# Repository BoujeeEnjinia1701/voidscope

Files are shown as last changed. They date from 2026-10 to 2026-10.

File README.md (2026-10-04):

# VoidScope

     

**Area:** Situational field hardware · **TRL:** 3 of 9 (proof of concept on paper) · **Value-engineering target:** about $2,000 USD (estimated cost $1,780 USD) · **Difficulty:** 3 of 5

Searches rubble voids with a camera probe that also delivers water and air to a trapped survivor.

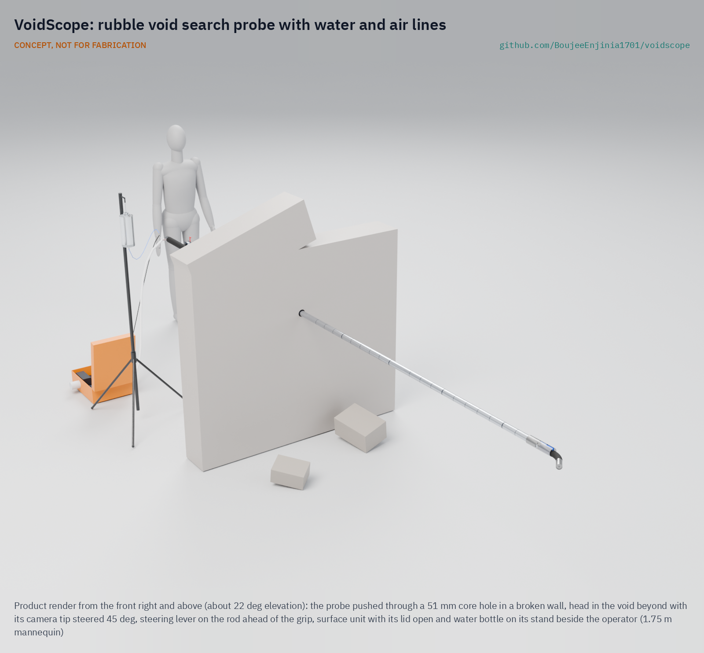
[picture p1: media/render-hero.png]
VoidScope: rubble void search probe with water and air lines, product render


[Exploded render](media/render-exploded.png) · [Detail render](media/render-detail.png) · [Interactive 3D model](media/viewer.html) · [Concept blueprint (PDF)](media/concept-blueprint.pdf) · [General arrangement (PDF)](cad/drawings/VDS-DWG-001.pdf) · [Calculations](docs/04-calcs/01-sizing.md) · [Prototype build plan](docs/05-build-plan.md) · [Design decisions](docs/06-design-decisions.md) · [Review note](docs/REVIEW.md)

## Concept rationale

Most people pulled alive from collapsed buildings are found by local responders in the first day, with little equipment. A camera probe lets a crew look into a void through a small hole instead of opening it blind, and the same probe can then carry water and fresh air to the person it finds. One tool does both jobs, so a crew that has located a survivor does not have to break a second path in to supply them.

Keeping the design open and buildable from commodity parts matters because commercial search cameras sit in the tens of thousands of dollars. VoidScope is a documented push probe built from a bought sealed camera head, aluminium tube and turned aluminium parts, with the rod itself as the air duct and a single-use food-grade water line inside it. Its value-engineering target is $2,000 USD and the constructable design is estimated at $1,780 USD, so that municipal and volunteer teams can build, repair and train with it.

## Burning platform

Time decides who lives. More than 90 per cent of earthquake survivors are rescued within the first three days, most within 24 hours by local responders using minimal equipment, and international teams typically need more than 24 hours to arrive ([Gulf News, citing Ilan Kelman, UCL, 2023](https://gulfnews.com/world/mena/why-first-72-hours-are-crucial-for-turkey-syria-quake-rescues-1.1675864021699)). The same source notes that without water, trapped people start dying at the three to five day mark.

The tools that help crews see into voids are costly. A Leader Cam search camera lists at $17,562 USD ([Emergency Responder Products](https://emergencyresponderproducts.com/products/leader-cam)), and the Savox SearchCam 3000 kit weighs 18.6 kg (41 lb) in its case ([Savox datasheet](https://www.datocms-assets.com/120614/1756472896-savox-searchcam-3000-datasheet-2.pdf)). Neither delivers water or air. Where supplies do reach trapped people, it is by improvisation: at Rana Plaza, rescuers gave the survivor Reshma water, oxygen and saline while they cut her free ([Global News, 2013](https://globalnews.ca/news/550768/bangladesh-rescuers-find-survivor-in-rubble-17-days-after-collapse/)).

## Where it could be used

### By industry

| Industry | Use |
| --- | --- |
| Fire and rescue services | Hasty void search and survivor support by municipal crews without a funded USAR camera |
| Humanitarian and disaster response | Low-cost search kit for local and volunteer teams in the first 72 hours after an earthquake |
| Construction and demolition | Standby search tool on sites where structures under construction may collapse |
| Mining and tunnelling | Looking into collapsed drifts or rescue pipes and passing water and air to trapped workers |
| Training and education | Affordable training probe for USAR courses and community emergency response teams |

### By country or region

| Country or region | Why it matters there |
| --- | --- |
| Turkey and Syria | The February 2023 earthquakes killed more than 42,000 people, and one survivor was pulled out after 248 hours without food or water ([CNN, 2023](https://www.cnn.com/2023/02/16/europe/turkey-syria-earthquake-rescue-efforts-intl/index.html)). |
| Bangladesh | The Rana Plaza collapse in 2013 left more than 1,000 dead, and rescuers worked for more than two weeks to reach survivors in the basement ([IBTimes UK, 2013](https://www.ibtimes.co.uk/rana-plaza-disaster-woman-named-reshma-found-466613)). |
| Nigeria | When a 21-storey building under construction collapsed in Ikoyi, Lagos, in 2021, up to 100 people were feared trapped ([Al Jazeera, 2021](https://www.aljazeera.com/news/2021/11/1/lagos-building-collapses-several-killed)) and 42 bodies were eventually recovered ([VOA, 2021](https://www.voanews.com/a/death-toll-in-lagos-high-rise-building-collapse-rises-to-42-/6303343.html)). |
| Nepal | The 2015 magnitude 7.8 earthquake killed more than 1,300 people by the first day's reports, and survivors pulled from the rubble swamped hospitals in the capital ([NPR, 2015](https://www.npr.org/sections/thetwo-way/2015/04/25/402160910/7-8-quake-hits-nepal-toppling-buildings-killing-at-least-138)). |

## What sparked the idea

On 10 May 2013, seventeen days after the Rana Plaza building collapsed near Dhaka, rescuers heard a garment worker named Reshma tapping on the wreckage with a pipe. She had rationed a few bottles of water. While crews cut through rods and debris to free her, they passed her water, oxygen and saline ([Global News, 2013](https://globalnews.ca/news/550768/bangladesh-rescuers-find-survivor-in-rubble-17-days-after-collapse/)). Finding her took days of listening; supplying her took improvisation. VoidScope asks whether one simple probe could do both, sooner.

## Problem

After a building collapse, local crews reach most survivors first but rarely have search cameras, and those who find someone alive still need to keep them supplied while the dig goes on. Commercial search cameras cost more than many local teams can pay and do not deliver water or air.

Full problem statement: [docs/01-problem.md](docs/01-problem.md)

## Concept

A 4.5 m push probe, 48 mm across at its widest, that passes a standard 51 mm core hole; its camera tip bends up to 90° either way from a thumb lever to look around a bend. Four aluminium sections click together with snap buttons and stay threaded on the camera cable and a water guide tube, like the cord in a tent pole. A sealed 1080p camera with its own lights sits in the steerable tip; a small speaker for two-way talk and a bite valve sit in the turned aluminium head. A battery blower in the surface unit pushes filtered air down the rod's bore and out of six holes at the head, never above 0.9 kPa even when the tip is blocked; a gravity drip from a bottle on a stand reaches the bite valve through a capillary that caps the flow at 4.5 mL/min. The monitor and recorder sit in the lid of the surface unit.

Full design precis: [docs/02-concept.md](docs/02-concept.md) · Requirements: [docs/03-requirements.md](docs/03-requirements.md)

## Key components

- Camera head: bought IP68 pipe-inspection head, 29 mm, 1080p, 12 LEDs
- Head: turned aluminium collar (socket, air outlets, speaker, water exit) and nose (camera, bite valve pocket)
- Rod: four 1,050 mm sections of 38.1 mm aluminium tube with bonded couplers and snap buttons; depth bands every 100 mm
- Tail cap with the air inlet barb, and a grip
- Lines: camera and speaker cable; PTFE guide tube; single-use water set with capillary, roller clamp and bite valve
- Surface unit: IP67 case with LiFePO4 battery, blower, intake filter, flow meter, push-to-talk amplifier, and a 7 in monitor with recorder in the lid
- Water bottle on a light stand; rod carry case; cleaning kit and spare water sets

## Building the prototype

The design is constructable: every part can be cut, drilled, turned or bought, and every joint has a fixing, checked by 180 model checks. The [prototype build plan](docs/05-build-plan.md) takes a maker through fourteen made components and seventeen assembly steps, each with a picture, and lists the first checks and the safety stops. It is a plan, not yet built; building and testing to it is TRL 4 work. Decisions live in the [design decisions register](docs/06-design-decisions.md).

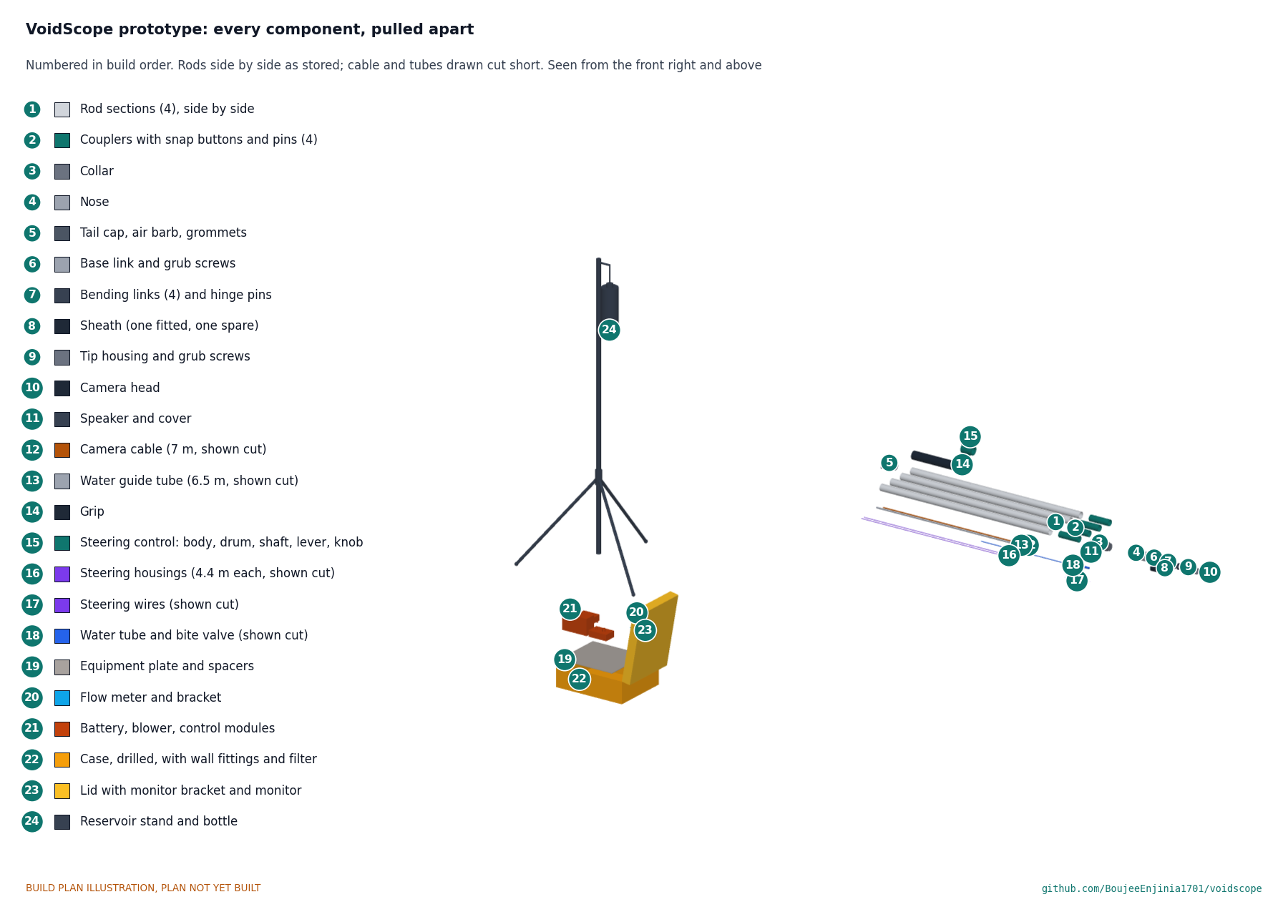
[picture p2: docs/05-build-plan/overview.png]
VoidScope prototype: every component, pulled apart


## Safety

> Safety-critical rescue equipment. Published as an open engineering reference, never as certified rescue equipment, and not a medical device. This is a TRL 3 concept, not for fabrication.
>
> Only trained rescue teams should use it, inside their own incident command and structural safety procedures. The operator never enters the void.
>
> Water can be inhaled by a survivor who is drowsy, injured or lying badly. Give water only under the direction of the team's medical lead, only to a conscious person who can drink, and only by the gravity drip through the bite valve, never under pressure. Never remove the capillary that caps the flow.
>
> Fresh air must be clean and low pressure; blowing air into a void can raise dust. Filter the intake and never connect fuel-engine exhaust, a compressor or compressed gas cylinders. The blower is chosen so it cannot exceed 1 kPa even with the tip blocked.
>
> The surface unit holds 12.8 V lithium iron phosphate packs. Charge them only on their own charger, away from the kit, on a non-combustible surface, never below 0 °C.
>
> Parts that touch the survivor are single-use or cleaned to a written procedure between uses.
>
> This design is published as an open engineering reference. It is not certified equipment.

## Repository layout

| Folder | Contents |
| --- | --- |
| `docs/` | Problem, concept, requirements, calculations and design decisions |
| `cad/src/` | build123d Python source, the source of truth for all geometry |
| `cad/step/`, `cad/stl/` | Exported models for FreeCAD, other CAD tools and printing |
| `cad/drawings/` | 2D sketches and dimensioned drawings |
| `bom/` | Bill of materials |
| `electronics/` | KiCad schematics and PCB layouts |
| `firmware/` | Microcontroller code |
| `media/` | Renders, perspectives and photos |
| `build-log/` | Dated prototyping notes |

## Documentation

Controlled documents follow the portfolio [documentation standard](.kit/STANDARDS.md). Each carries a document ID (VDS-PRC-001 for the precis), a version and a revision history. Branded PDFs are built with `python .kit/render.py` and attached to GitHub Releases when a document is tagged, for example `VDS-PRC-001/v1.0`.

## Credits

Designed by Amish Chadha at Design Molecule Labs. See [CONTRIBUTORS.md](CONTRIBUTORS.md) for roles. To cite this design, use [CITATION.cff](CITATION.cff) (GitHub shows it as "Cite this repository").

AI assistance (Claude) was used to accelerate prototype documentation and first-pass research. Design direction and all decisions are Amish Chadha's, recorded in this repository's decision records (`docs/decisions/`).

## Licenses

- **Hardware** (CAD, drawings, BOM, electronics): [CERN-OHL-S v2](LICENSE)
- **Software** (firmware, scripts, notebooks): [MIT](LICENSE-SOFTWARE)

A project of the [Design Molecule](https://designmolecule.com) lab.

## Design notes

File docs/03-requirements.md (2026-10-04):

---
doc_id: VDS-REQ-001
title: VoidScope requirements
project: VoidScope
doc_type: Requirements
version: "0.5"
status: Draft
date: '2026-10-03'
author: Amish Chadha
license: CERN-OHL-S-2.0
revisions:
- version: "0.1"
  date: '2026-09-30'
  author: Amish Chadha
  change: Initial scaffold
- version: "0.2"
  date: '2026-10-03'
  author: Amish Chadha
  change: "TRL 2: R2 split into reach (R2) and bends (R11); R5 restated as a ceiling with a bite valve; R6 adds the blocked-tip limit; R8 worded as a value-engineering target; R12 two-way voice added; concept status for each"
- version: "0.3"
  date: '2026-10-03'
  author: Amish Chadha
  change: "TRL 3: status from VDS-CAL-001 on the constructable design (VDS-DDR-002)"
- version: "0.4"
  date: '2026-10-03'
  author: Amish Chadha
  change: "R11 restated by Amish (decision 3A) as seeing around a 45-degree bend from a straight hole, with a test-box verification; met on paper by the steerable camera tip (VDS-DDR-003); status of R1, R2, R4, R8 and R9 updated from VDS-CAL-001 v0.2"
- version: "0.5"
  date: '2026-10-03'
  author: Amish Chadha
  change: "Round-2 decision 3A (VDS-DDR-004): water offered with the tip steered aside; medical lead's confirmation in drills. Requirement wording unchanged"
---

# VoidScope requirements

Eleven of the twelve requirements are met on paper by the constructable design with its steerable camera tip: eight by calculation and three by design, all to be confirmed by test at TRL 4. R9 (setup in 3 minutes) is estimated at 2.2 minutes but can only be settled by timed drills. R11 was restated on 2026-10-03 by Amish, who chose option A for it ("3A", in his reply "1A 2A 3A 4A 5A 6A 7A 8A 9A 10A 11A"): instead of following a channel with two 45° bends, the probe goes in straight and its camera tip, steered from the handle, looks around a 45° bend. The rigid rod, the air path through its bore and the water tube to the bite valve are unchanged.

*Table 1. Requirements and status at TRL 3 (tags in brackets refer to VDS-CAL-001).*

| ID | Requirement | Target | Verification (TRL 4 or later) | Status at TRL 3 |
| --- | --- | --- | --- | --- |
| R1 | Probe passes a standard core hole | Outer diameter of tip and rod at or below 50 mm | Pass the assembled probe through a 51 mm test ring along its full length | Met with the tip locked straight: 48 mm at the head and tip, 47 mm at the grip [A1]. The handle-end fittings (the tail cap's air barb and now the steering control) are wider and stay outside the hole |
| R2 | Reach into a void along a straight path | Working length of at least 4 m (13 ft) | Measure assembled length from the grip to the tip | Met: 4,203 mm from the grip; 4,131 mm can go in before the steering control reaches the hole [A4g, A4] |
| R3 | See in darkness and dust | Read a 20 mm high letter at 1 m in a dark, dusty test box | Test box with a set dust load and no ambient light | Met on paper: 19 pixels per letter against 10 needed; 7 lx left after 2 m of dusty air [C2, C6]; dust load to test |
| R4 | Survive rubble handling | Head survives 20 drops of 1 m onto concrete and 1 m water immersion for 30 minutes | Drop and immersion tests followed by a video check | By design: IP68 camera in an aluminium tip housing, sheathed bending section, nose with 2.85 mm minimum wall [G2]; to test, with the tip straight and bent |
| R5 | Controlled water delivery | Drip from 0 up to a ceiling of no more than 5 mL/min at any allowed height up to 40 °C; no flow when the clamp is closed or the valve is not bitten | Timed collection at the tip at set heights and temperatures | Met: ceiling 1.5 mL/min at 1 m and 20 °C, 4.5 mL/min at 2 m and 40 °C [D1, D2] |
| R6 | Air delivery to the void | At least 20 L/min of filtered air at the tip; never more than 1 kPa above ambient, even with the tip blocked | Flow meter and manometer at the tip, open and blocked | Met: 44 L/min at full speed, 0.9 kPa at shut-off [E3, E5] |
| R7 | Shift-long battery life | At least 4 h of continuous video and light at 20 °C and at -10 °C | Run-down test at 20 °C and at -10 °C | Met: 6.2 h and 4.3 h on one pack [F4] |
| R8 | Cost against the value-engineering target | Full kit parts cost against the USD 2,000 target | Costed bill of materials from named suppliers | USD 1,780, USD 220 under the target [I2, I4] |
| R9 | Quick to deploy | Two trained people assemble and start searching within 3 minutes | Timed drills with a USAR partner | Estimate 2.2 min [H6]; only a timed drill can settle it |
| R10 | Hygienic water path | Water path parts replaceable in under 5 minutes without tools | Timed replacement against a cleaning procedure | By design: single-use water set, about 4 min [D8]; to time |
| R11 | See around a 45-degree bend from a straight hole (restated 2026-10-03, Amish, decision 3A) | With the probe pushed straight through a 51 mm hole, steer the camera to look down a passage that turns 45° to either side and read what is there | Test box: a 51 mm hole into a straight passage 300 mm wide that turns 45° 0.5 m beyond the hole. Push the probe straight in, steer the tip from the handle and read 20 mm letters 1 m down the turned passage on the monitor; repeat to the other side; straighten the tip and withdraw it through the hole | Met on paper: the tip bends up to 90° each way [J3]; bent 45° it needs 83 mm to the side [J6] and a 20 mm letter at 1 m gets 19 pixels [C2] |
| R12 | Talk with the survivor | Two-way voice between the operator and a person at the tip | Speech test in a rubble box | By design: tip speaker as speaker and microphone, push-to-talk headset |

## Assumptions

- Local crews can open or find gaps of about 50 mm into most voids of interest.
- A rigid, sectioned rod is good enough for a first version, with a camera tip that bends in one plane; turning the rod chooses the plane. Following a bent channel with the rod itself is not required (R11 as restated).
- A slow gravity drip through a bite valve is an acceptable way to give water when a medical lead directs it; the bite valve stays on the nose and the operator steers the tip aside to give water (drill card, build plan section 5a); the medical lead's confirmation in drills is a TRL 4 item.
- Commodity sealed pipe-inspection camera heads meet the image, light and sealing targets.

> **Safety:** These requirements describe rescue equipment that delivers water and air to a trapped person and carries a lithium battery. The steerable tip must be locked straight before it goes into or comes out of a hole. Meeting them on paper does not make the design safe to use. VoidScope is an open engineering reference, not certified rescue equipment and not a medical device; see VDS-PRC-001, Safety.

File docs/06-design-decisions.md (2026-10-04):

---
doc_id: VDS-DEC-001
title: VoidScope design decisions register
project: VoidScope
doc_type: Design decisions register
version: "0.3"
status: Draft
date: '2026-10-03'
author: Amish Chadha
license: CERN-OHL-S-2.0
revisions:
- version: "0.1"
  date: '2026-10-03'
  author: Amish Chadha
  change: "Register opened at TRL 3; every decision made under Amish's 2026-10-03 pre-approval"
- version: "0.2"
  date: '2026-10-03'
  author: Amish Chadha
  change: "Amish's requirement decision 3A (steerable camera tip, R11 restated) recorded as made (VDS-DDR-003); one new open decision on bite valve access; four items to confirm when parts are bought; value engineering updated"
- version: "0.3"
  date: '2026-10-03'
  author: Amish Chadha
  change: "Open decision 1 (bite valve access) decided, round 2, 3A (VDS-DDR-004); one item added to confirm when parts are bought; no open decisions"
---

# VoidScope design decisions register

Every design decision still to be made, and every decision made, in one place. Each decision is argued in full in its decision record under `docs/decisions/`; this register is the index Amish works from. The build plan (`docs/05-build-plan.md`) describes the design as it stands and does not list open decisions.

> **Safety:** Several decisions below set safety stops: the drip ceiling, the bite valve, the blower's shut-off pressure and the battery chemistry. The open decision on bite valve access touches how a survivor is given water. They were taken on the conservative side (VDS-DDR-001, Table 2). VoidScope is rescue equipment that is not certified and is not a medical device.

## Open decisions

None. Open decision 1 (bite valve access) was decided by Amish on 2026-10-03: the valve stays on the nose and the tip is steered aside to give water; see Decisions made and VDS-DDR-004.

## To confirm when parts are bought

| # | What to confirm | Why it matters | Source |
| --- | --- | --- | --- |
| 1 | The camera head is 29 mm or less across and about 55 mm long, IP68 at 1 m for 30 min, AHD 1080p with about a 90° view and 12 dimmable LEDs, with a pigtail at least 170 mm long | It sets the tip housing bore, R3 and R4; the pigtail must reach back through the tip to its splice in the nose | VDS-DDR-001 D4; VDS-CAL-001 C |
| 2 | The blower's shut-off (maximum static) pressure is 1.0 kPa or less, and its curve gives at least 20 L/min through 0.38 kPa | It is the air pressure safety stop (R6) | VDS-DDR-001 D8, S3; VDS-CAL-001 E |
| 3 | The flow meter's pressure drop is 0.2 kPa or less at 20 L/min and it fits 100 mm tall | A larger drop lowers the full-speed flow; the lid must close | VDS-CAL-001 E; VDS-DDR-002 P11 |
| 4 | The snap button suits 1.47 mm and 2.11 mm walls, its button stands about 1.5 mm proud, and it holds a 300 N pull | It locks every joint | VDS-DDR-002 P2; VDS-CAL-001 B |
| 5 | The two tube sizes telescope with about 0.11 mm a side as bought | The couplers must slide in by hand | VDS-DDR-002 P1 |
| 6 | The capillary bore is 0.5 mm and the measured flow at 1 m and 20 °C is about 1.5 mL/min | It sets the drip ceiling (R5) | VDS-DDR-001 S1; VDS-CAL-001 D |
| 7 | The bite valve is about 11 mm across, fits the 4 mm tube and stays shut under 20 kPa of water head | It is the water safety stop | VDS-DDR-001 S2; VDS-CAL-001 D7 |
| 8 | The speaker is 20 mm across and 4 mm thick, IP67 | It must sit flush in its pocket | VDS-DDR-002 P8 |
| 9 | The hybrid cable is 6 mm or less across, and the case, monitor (28 mm deep) and battery (151 x 65 x 94 mm) match the sizes modelled | They set the grommets, the plate layout and the lid stack | VDS-DDR-002 P10, P11 |
| 10 | The 0.6 mm 7x7 stainless wire rope breaks at 250 N or more | It sets the factor of 3.0 at a 30 N thumb push against the stop | VDS-DDR-003; VDS-CAL-001 J16 |
| 11 | The 3 mm steering housings bend to about 15 mm radius where they turn up into the control body, and their friction is about 0.15 | A stiffer housing needs a taller pad; more friction raises the thumb force | VDS-DDR-003 T5, T8; VDS-CAL-001 J13 |
| 12 | The camera cable's bending stiffness is near 5,000 N·mm² | It sets the thumb force to hold 90° (about 5 N) | VDS-CAL-001 J12 to J14 |
| 13 | The printed links' 2.0 mm pin holes ream cleanly and the lugs hold the pins without rocking | The joints must swing freely but not wobble the camera | VDS-DDR-003 T3 |
| 14 | Confirm in drills with the medical lead that a survivor can reach the bite valve on the nose past the tip steered fully aside | The valve stays on the nose (decision 3A, round 2); if it is hard to reach, a 60 mm flexible valve extension is the fallback | VDS-DDR-004 |

## Value engineering

Value-engineering target: USD 2,000 (a hypothetical control target, not a limit). Estimated cost of the constructable design: USD 1,780 (USD 220 under the target). Main cost drivers and savings worth trying:

- The largest lines are the lathe time allowance (USD 240), the monitor with recorder and bracket (USD 175), the cleaning kit and four spare water sets (USD 118), the rod sections (USD 128 for four), the rod carry case (USD 115), the battery packs (USD 110 for two), the surface unit case (USD 110) and the camera head (USD 95).
- Savings worth trying: a builder with a lathe saves USD 240; a soft carry bag in place of the hard rod case saves about USD 80; a single battery pack saves USD 55 but leaves no spare for a full shift at -10 °C; printing the base link and drum in PA12 with the links would save about an hour of lathe time (USD 60) at some cost in wear.
- Making the design constructable added the couplers, buttons and pins, the guide tube, the equipment plate, the brackets and the lathe allowance, about USD 290 in all. The steerable tip (decision 3A) added USD 202: links, pins and sheaths USD 42, base link USD 6, tip housing USD 8, wires and housings USD 38, steering control USD 48 and one more hour of lathe time USD 60.

## Decisions made

| Date | Decision | Decided by | Record |
| --- | --- | --- | --- |
| 2026-10-03 | TRL 2 review items D1 to D13: lines inside with the bore as air duct; 38.1 mm aluminium sections with snap buttons; no articulation; bought IP68 camera head; monitor in the surface unit lid; tip speaker as speaker and microphone; gravity drip with capillary ceiling and bite valve; blower chosen by shut-off pressure; two LiFePO4 packs; independent of the crawler block; requirements restated; budget, pitch and problem kept | Amish: "I pre-approve the batch runs along with any recommendations you come up with. I also accept any cost overruns or variations from the assumed scope cost." | VDS-DDR-001 |
| 2026-10-03 | Conservative safety choices S1 to S6, each with the evidence that would relax it | Amish, same pre-approval | VDS-DDR-001, Table 2 |
| 2026-10-03 | First co-design candidate to approach: the disaster management training school of the Armed Police Force, Nepal; second: Turkey's AFAD training centres (not contacted, not partners) | Amish, same pre-approval | VDS-DDR-001 D11 |
| 2026-10-03 | Design for construction, changes P1 to P14 | Amish, same pre-approval | VDS-DDR-002 |
| 2026-10-03 | R11 (two 45° bends) recorded as not met in the first version; a flexible lead section is a later version, not TRL 3 work (superseded the same day by decision 3A below) | Amish, same pre-approval | VDS-REQ-001 v0.3; VDS-DDR-001 D12 |
| 2026-10-03 | Appearance model departures from `model.py` (rounded edges, depth bands, labels, cables drawn to the surface unit, rubble context) accepted for renders only | Amish, same pre-approval | `docs/REVIEW.md`, TRL 3 |
| 2026-10-03 | Decision 3A: add a cable-steered articulating camera tip that bends up to 90° each way, controlled from the handle; restate R11 as "see around a 45-degree bend from a straight hole" with a verification method; keep the rigid rod, the air path and the water tube to the bite valve; the tip must still pass the 51 mm hole | Amish: "1A 2A 3A 4A 5A 6A 7A 8A 9A 10A 11A" | VDS-DDR-003; VDS-REQ-001 v0.4 |
| 2026-10-03 | 3A (round 2): bite valve kept on the nose; the drill card says steer the tip aside to give water; "confirm in drills with the medical lead" added under To confirm; articulating camera tips added to the patent screen list. No design change | Amish: "i agree with all the 46 recommendations you provided. please proceed." | VDS-DDR-004 |

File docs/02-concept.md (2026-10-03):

---
doc_id: VDS-PRC-001
title: VoidScope design precis
project: VoidScope
doc_type: Precis
version: "0.4"
status: Draft
date: '2026-10-03'
author: Amish Chadha
license: CERN-OHL-S-2.0
revisions:
- version: "0.1"
  date: '2026-09-30'
  author: Amish Chadha
  change: Initial scaffold
- version: "0.2"
  date: '2026-10-03'
  author: Amish Chadha
  change: "TRL 2 populate: how it works, components, key design choices, first-order numbers, safety, concept media"
- version: "0.3"
  date: '2026-10-03'
  author: Amish Chadha
  change: "TRL 3: constructable design (VDS-DDR-002), numbers from VDS-CAL-001, decisions recorded under Amish's 2026-10-03 pre-approval"
- version: "0.4"
  date: '2026-10-03'
  author: Amish Chadha
  change: "Steerable camera tip (Amish's decision 3A, VDS-DDR-003): summary, key choice 2, numbers from VDS-CAL-001 v0.2, patent note"
---

# VoidScope design precis

Searches rubble voids with a camera probe that also delivers water and air to a trapped survivor.

VoidScope is a 4.5 m push probe, 48 mm across at its widest, that passes a standard 51 mm core hole. A sealed 1080p camera with its own lights sits in a steerable tip that a thumb lever on the rod bends up to 90° to either side, so the camera looks around a bend from a straight hole; a small speaker on the head gives two-way talk. The rod is the air duct: a battery blower at the surface pushes filtered air down the bore and out of six holes at the head, at no more than 0.9 kPa even with every hole blocked. Inside the rod a guide tube carries a single-use water tube from a bottle at the surface to a bite valve on the nose, so a survivor can sip a slow gravity drip of at most 4.5 mL/min. The estimated parts cost is USD 1,780 against a value-engineering target of USD 2,000.

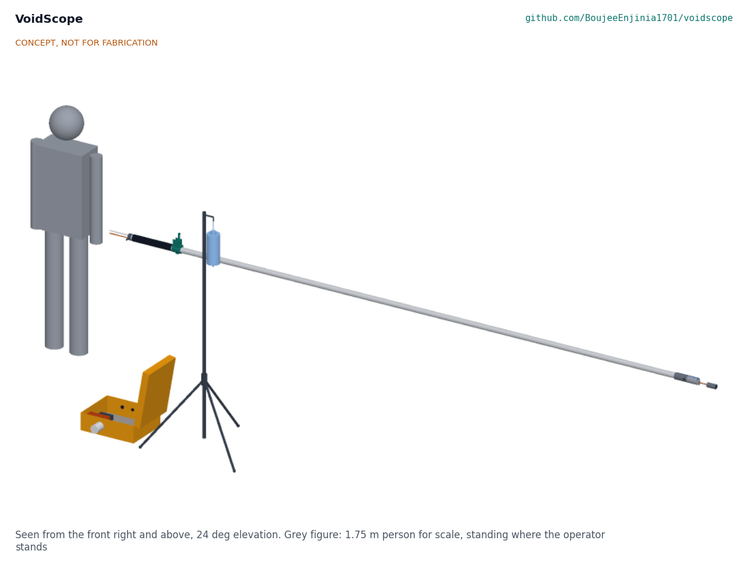
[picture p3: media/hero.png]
Figure 1. VoidScope concept: probe, surface unit and reservoir stand


*Figure 1. The kit as deployed: probe held at waist height by the operator (grey figure, 1.75 m), surface unit on the ground with its lid open, water bottle on its stand.*

## How it works

Two rescuers carry two cases. The long case holds the four rod sections side by side, already threaded on the camera cable and the water guide tube like the shock cord in a tent pole, with the head at the front. The second case is the surface unit: battery, blower, flow meter, push-to-talk amplifier and a 7 in monitor with a recorder in its lid.

To search, the crew joins the sections (each snap button clicks into the next section), plugs the camera cable and the air hose into the surface unit and feeds the probe into a gap or a cored hole while watching the monitor. The camera is aimed by turning the rod; depth marks every 100 mm show how far in the tip is.

When they find someone, they leave the probe in place. They talk through the speaker at the tip, which also works as the microphone. If the team's medical lead decides that the person is conscious and able to drink, the crew hangs the water bottle on its stand no more than 1 m above the tip and opens the roller clamp. The survivor pulls the bite valve out of its pocket on the nose and sips; the tube pays out from the surface. A 600 mm capillary in the line sets the highest possible flow, so even a bottle hung too high on a hot day cannot pass more than 4.5 mL/min. The blower is set to about 20 L/min on the flow meter to freshen the air in the void while the dig goes on around the probe.

*Figure 2. Air and water paths, with estimated flows.*

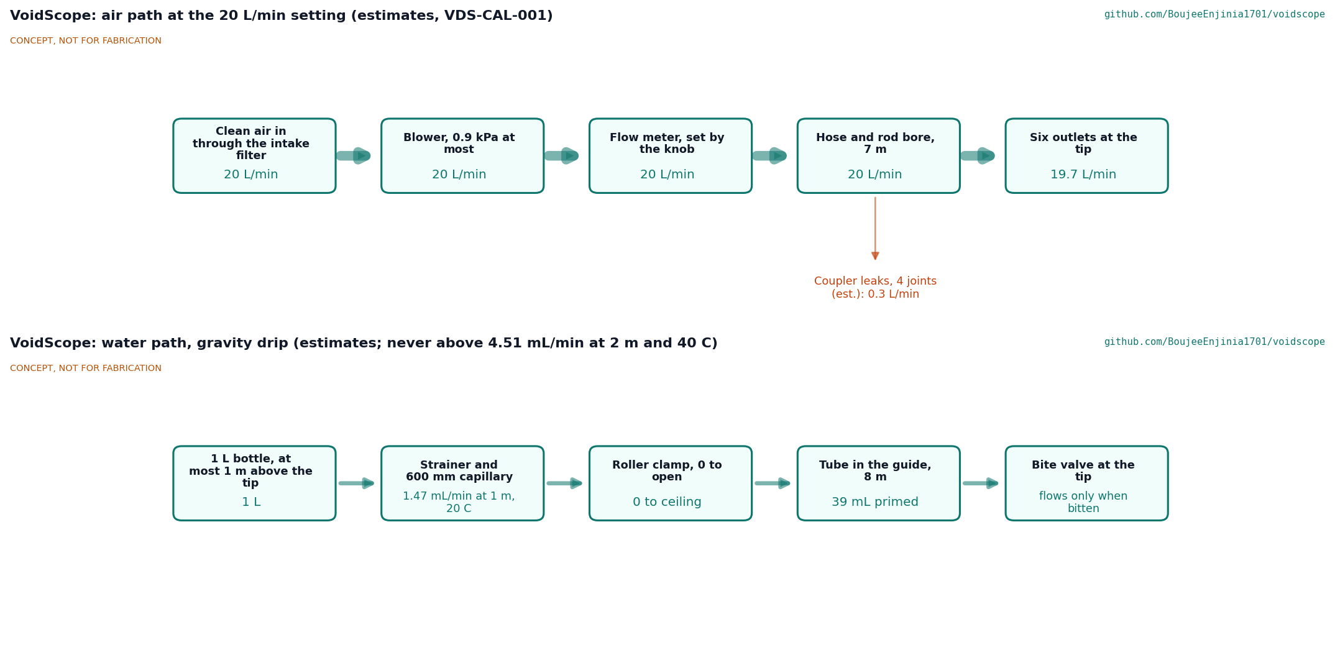
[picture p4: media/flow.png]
Figure 2. Air and water flow


## Components

*Table 1. Main components (BOM line numbers in brackets).*

| # | Component | Role |
| --- | --- | --- |
| 1 | Camera head (1) | Bought sealed pipe-inspection camera, 29 mm, IP68, AHD 1080p, 12 LEDs |
| 2 | Nose (2) and collar (3) | Turned 6061 aluminium head, 48 mm: camera bore below the axis, bite valve pocket on top, air plenum with six outlets, speaker pocket, water exit, socket for the first rod section |
| 3 | Speaker (4) | 20 mm IP67 speaker in the collar, also the microphone |
| 4 | Rod sections (5) and couplers (6) | Four 1,050 mm sections of 38.1 x 1.47 mm 6061-T6 tube; internal couplers bonded and pinned, locked by V-spring snap buttons; the bore is the air duct |
| 5 | Tail cap (7) and grip (8) | Turned cap with the air inlet barb and two grommets for the lines; rubber grip |
| 6 | Lines (9, 10, 11) | Hybrid camera and speaker cable; PTFE guide tube; single-use food-grade water tube with bite valve, capillary, roller clamp, stopcock and strainer |
| 7 | Water reservoir (12, 13) | 1 L graduated bottle hung on a light stand with height marks |
| 8 | Surface unit (14 to 23) | IP67 case with an equipment plate, LiFePO4 battery, blower, intake filter, flow meter, control modules, wall fittings, and the monitor with recorder in the lid; headset with push-to-talk |
| 9 | Support kit (24 to 28) | Air hose and sleeve, charger, rod carry case, cleaning kit and spare water sets, fixings |

## Key design choices

All choices below were decided on 2026-10-03 under Amish's pre-approval ("I pre-approve the batch runs along with any recommendations you come up with"); the TRL 2 choices are in VDS-DDR-001 and the changes made for construction in VDS-DDR-002.

1. **Lines inside the rod, with the bore as the air duct.** Nothing runs outside to catch on rebar, and the bore gives the air a large, low-loss path: about 10 Pa over the rod at 20 L/min.
2. **Rigid sectioned rod with a steerable camera tip.** The rod stays cheap and repairable and still cannot follow bends; instead the camera tip, on five pinned joints steered by two wires from a thumb lever, looks around a 45° bend from a straight hole (R11 as restated by Amish on 2026-10-03, decision 3A; VDS-DDR-003).
3. **Bought sealed camera head in a machined nose.** Sealing a camera to IP68 is the hardest part to make well; a pipe-inspection head already is.
4. **Tent-pole storage.** The sections stay threaded on the cable and guide tube, so setting up means only joining four snap buttons.
5. **Pressure-limited air.** A centrifugal blower whose shut-off pressure is at or below 1 kPa cannot pressurise a blocked void beyond that, whatever the knob says.
6. **Flow-limited water with a bite valve.** A fixed capillary sets the ceiling; the bite valve means no water leaves the tip unless the survivor bites. No pump and no pressurised water.
7. **Two-way voice at the tip.** Talking to the survivor is how the crew judges whether they are conscious and able to drink.
8. **One battery type, two packs.** 12.8 V LiFePO4 packs with built-in protection; one runs video and light for 4.3 h at -10 °C.

## First-order numbers

*Table 2. Key figures from VDS-CAL-001 (estimates, assumptions stated there).*

| Quantity | Value |
| --- | --- |
| Largest diameter; clearance in a 51 mm hole | 48 mm; 1.5 mm a side |
| Probe length; length that can go into a void | 4,538 mm; 4,131 mm |
| Camera tip: bend each way; sideways reach bent 45° | 90°; 83 mm |
| Probe mass; surface unit mass | 4.2 kg; 6.2 kg |
| Tip droop with 2 m unsupported | 17 mm |
| Buckling load of the whole rod | 940 N (4.7 times a 200 N push) |
| Pixels across a 20 mm letter at 1 m | 19 (10 needed) |
| Water ceiling: 1 m at 20 °C; 2 m at 40 °C | 1.5 mL/min; 4.5 mL/min |
| Air: total loss at 20 L/min; flow at full speed | 0.38 kPa; 44 L/min |
| Highest air pressure at a blocked tip | 0.9 kPa |
| Run time, video and light, one pack at -10 °C | 4.3 h |
| Estimated cost | USD 1,780 (USD 220 under the USD 2,000 target) |

## Patent design-arounds

From the preliminary patent, trademark and prior-art screen (not legal advice):

- Run a focused CPC patent search on combined search camera and supply probes before public release (the preliminary screen found no blocking patent).
- The rigid rod was first chosen partly to stay clear of articulation patents. The steerable tip (decision 3A) uses a plain two-wire pinned-link bending section of the kind long used in borescopes, but the focused search should now also cover articulating camera tips on search poles.
- Water is delivered by a passive, gravity-fed sanitary drip only, with no pump and no pressurised water to the survivor. The constructable design keeps this: bottle, capillary, clamp and bite valve.
- VoidScope does not adopt the proposed tethered crawler block (VDS-DDR-001, D10), so the RedZone US8024066B2 tether odometry question does not arise; the depth marks are printed on the rod.

## Shared blocks

- Rescue family siblings RubbleJack, HeapLine and SleeveDrift for procedures and kit lists.
- The tethered crawler block is not used (D10).

## Safety

> **Safety:** VoidScope is safety-critical rescue equipment. It is published as an open engineering reference, never as certified rescue equipment, and it is not a medical device.
>
> - **Structure.** Only trained rescue teams should use it, inside their own incident command and structural safety procedures. The operator never enters the void and never stands on unstable debris to push the probe.
> - **Water.** Water can be inhaled by a survivor who is drowsy, injured or lying badly. Give water only under the direction of the team's medical lead, only to a conscious person who can drink, and only by the gravity drip. Never connect a pump, a pressurised container or a syringe to the line once the probe is in the void. The capillary and bite valve are the safety stops; never remove the capillary to speed up the flow.
> - **Air.** Air must be clean and at low pressure. Filter the intake, keep it away from engine exhaust and smoke, and never connect a compressor or a gas cylinder to the tail cap. Blowing air can raise dust; start at the lowest setting and watch the picture.
> - **Battery.** The packs are 12.8 V lithium iron phosphate with built-in protection. Charge them only with the matching charger, away from the kit, on a non-combustible surface, never below 0 °C.
> - **Hygiene.** Parts that touch the survivor (water tube, bite valve) are single-use. The bottle is cleaned to a written procedure between uses.
>
> Choices that touch safety took the conservative option (VDS-DDR-001): the drip ceiling is sized for a 2 m water height at 40 °C, twice the allowed height, and the blower is chosen by its shut-off pressure rather than by a relief valve. The evidence that would relax them is listed in VDS-DEC-001.

## Next steps

- TRL 4 (not started; capped): build the prototype to VDS-BLD-001, then test it against VDS-REQ-001 with the first co-design candidate's medical lead.

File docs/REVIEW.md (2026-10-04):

# Review note: VoidScope

## Session 2026-09-30: scaffolded

### What was done

- Repository created from kit 1.6.0 at TRL 1, target TRL 2.
- `docs/01-problem.md` (VDS-PRB-001 v0.1): problem with cited evidence, users, environment, constraints, prior work, open questions.
- `docs/02-concept.md` (VDS-PRC-001 v0.1): how it works, components, patent design-arounds, shared blocks, safety.
- `docs/03-requirements.md` (VDS-REQ-001 v0.1): 10 proposed requirements.
- `README.md` with concept rationale, burning platform, where it could be used, and what sparked the idea.

## Session 2026-10-03: TRL 2 (populate)

Run as the first half of `/to-trl3` under Amish's instruction of 2026-10-03: "start with the first 14 repos from the list of 29 projects. I pre-approve the batch runs along with any recommendations you come up with. I also accept any cost overruns or variations from the assumed scope cost." Kit 1.7.0 installed first (`.kit/`, `.claude/commands/`, root `CLAUDE.md`; `.kit/PHASE.yaml` as installed). No commit or push, by instruction.

### What was done

- VDS-PRB-001 v0.2: constraints tied to the requirements; co-design checklist; first co-design candidate named; the v0.1 open questions answered by the TRL 2 decisions.
- VDS-PRC-001 v0.2: how it works, components, key design choices with first-order numbers, safety section.
- VDS-REQ-001 v0.2: R2 split into straight reach (R2) and bends (R11); R5 restated as a drip ceiling with a bite valve; R6 adds a blocked-tip limit; R8 worded as a value-engineering target; R12 two-way voice added.
- Concept media: because the whole TRL 3 path ran in one session, the massing model was taken straight into the constructable model, and every concept picture was generated from that (see the TRL 3 section).

### Key results at TRL 2 (first-order, superseded by VDS-CAL-001)

- Lines inside the rod fit with room to spare once the rod bore carries the air; a separate 9 mm air line would have lost about 0.46 kPa at 20 L/min, more than a pressure-limited blower can give.
- A fixed capillary is the simplest way to cap a gravity drip whatever the bottle height; an open 2.5 mm tube alone would pass about 70 mL/min at 1 m.
- A rigid rod cannot meet the TRL 1 verification of "a test channel with two 45° bends"; that part of R2 became R11.

### Decisions made under Amish's pre-approval (VDS-DDR-001)

D1 to D13, each with options and the reason, in `docs/decisions/0001-trl2-review-decisions.md`: lines inside with the bore as the air duct; 38.1 mm aluminium sections with snap buttons, tent-pole storage; no articulation; bought IP68 camera head; monitor in the surface unit lid; tip speaker as speaker and microphone, fitted as standard; gravity drip with a capillary ceiling and a bite valve; blower chosen by its shut-off pressure; two LiFePO4 packs; independent of the tethered crawler block; requirements restated; budget, pitch and problem kept. Safety choices S1 to S6 taken on the conservative side, each with the evidence that would relax it. First co-design candidate to approach: the disaster management training school of the Armed Police Force, Nepal; second: Turkey's AFAD training centres (not contacted, not partners).

### Safety concerns

- Aspiration: water to a drowsy or badly lying survivor. Mitigated by the medical lead's direction, the bite valve (no flow unless bitten) and the capillary ceiling.
- Air: pressurising or dusting a void. Mitigated by a blower whose shut-off pressure is at most 1 kPa, an intake filter and a flow meter.
- Structure: the operator never enters the void; the probe is never a lever.
- Battery: LiFePO4 packs with built-in protection, charged away from the kit.

## Session 2026-10-03: TRL 3 (advance, constructable design and build plan)

The second half of `/to-trl3`: `/advance-trl3` including `/build-plan` steps 1 to 4, with every decision recorded as made under Amish's pre-approval quoted above. TRL cap respected: no hardware, test plans, firmware, PCB layouts, purchasing lists or build-log entries. No commit or push.

### What was done

- `cad/src/model.py`: parametric build123d model of the whole kit as deployed (probe, surface unit, reservoir stand), built from components with every fixing, and 106 constructability checks (`python cad/src/model.py --check`). All 106 pass. STEP and STL in `cad/step/` and `cad/stl/` (assembly, probe, head, surface unit).
- `docs/04-calcs/sizing.py` and `docs/04-calcs/01-sizing.md` (VDS-CAL-001 v0.1): envelope and reach, rod structure and handling, vision, water, air, power, robustness, deployment, mass and cost; `results.csv`.
- `cad/src/sheets.py`: general arrangement VDS-DWG-001 at Rev P2 (P1 preliminary GA, P2 design for construction), with a 1:2 detail of the head.
- `bom/bom.csv`: 29 lines, every one priced, with a supplier type.
- `cad/src/concept_media.py`: hero (1.75 m figure standing where the operator stands), head cutaway, exploded view, air and water flow diagram, blueprint VDS-DWG-010 Rev P2, `model.glb` (1.2 MB, exported at 1.0 mm linear and 0.35 rad angular deflection) and `viewer.html`.
- `docs/decisions/0002-design-for-construction.md` (VDS-DDR-002): fourteen changes, P1 to P14, with reasons.
- `cad/src/build_plan_media.py`: overview, nine making sketches VDS-DWG-101 to 109, eight joint close-ups, fifteen step pictures and the wiring and lines diagram.
- `docs/05-build-plan.md` (VDS-BLD-001 v0.1) and `docs/06-design-decisions.md` (VDS-DEC-001 v0.1).
- `cad/src/product_model.py`: appearance model with `product_parts()`, `TITLE` and `RENDER_VIEWS` (hero, exploded, detail); render scenes exported to `/home/claude/renders/voidscope` for the photoreal renders on Amish's Mac.
- VDS-PRB-001 v0.3, VDS-PRC-001 v0.3, VDS-REQ-001 v0.3; `project.yaml` at TRL 3 with `design_state: constructable` and the evidence list; README with the render hero, links line and a "Building the prototype" section.

### Key results (VDS-CAL-001)

- Envelope 48 mm (head) in a 51 mm core hole; probe 4,398 mm; working length 4,063 mm.
- Probe 3.66 kg; surface unit about 6.2 kg with one pack.
- Rod buckling 1,001 N (5 times a 200 N push); 2.55 on yield at a button hole with 3 m unsupported in a void; tip droop 15 mm at 2 m.
- Vision: 19 pixels across a 20 mm letter at 1 m; 7 lx after 2 m of heavy dust.
- Water ceiling 1.47 mL/min at 1 m and 20 °C; never more than 4.51 mL/min (2 m, 40 °C).
- Air: 0.38 kPa loss at 20 L/min, 44 L/min at full speed, 0.9 kPa with the tip blocked.
- Battery: 6.2 h at 20 °C and 4.3 h at -10 °C of video and light on one pack.
- Value-engineering target: USD 2,000. Estimated cost of the constructable design: USD 1,578 (USD 422 under the target); USD 1,398 for a builder with a lathe.

### Requirements not met

- **R11, two 45° bends:** not met. The rigid rod goes straight only. A flexible lead section between section 1 and the head is a later version (recorded as decided, not redesigned at TRL 3).
- R9 (3 min setup) is an estimate, 2.1 min, that only a timed drill can settle. R3, R4, R10 and R12 are met on paper or by design and need TRL 4 tests.

### Decisions made under the pre-approval

- VDS-DDR-001 (TRL 2 review, D1 to D13 and S1 to S6) and VDS-DDR-002 (design for construction, P1 to P14), indexed in VDS-DEC-001. Open decisions: none. Nine items are listed in VDS-DEC-001 to confirm when parts are bought (camera size and rating, blower shut-off pressure, flow meter drop, snap button strength, tube telescoping fit, capillary flow, bite valve, speaker, cable, case, monitor and battery sizes).
- Appearance model departures from `model.py`, accepted under the same pre-approval: painted depth bands every 100 mm, a screen face on the monitor, LED dots and a lens on the camera face, the hose, cable and water tube drawn from the probe to the surface unit and bottle, a broken concrete wall with a 51 mm core hole, rubble and a standing 1.75 m mannequin. All main dimensions come from `model.py`.

### Build plan findings

- The concept said nothing about how the sections join; two stock tube sizes (1.5 x 0.058 in and 1.375 x 0.083 in) telescope with 0.11 mm a side and made the coupler a cut-to-length part, no turning.
- A flat 28 mm speaker cannot sit inside a 48 mm round outline; the 20 mm speaker fits with its cover flush.
- Putting the camera 6.5 mm below the axis made room for the bite valve pocket on top inside the 48 mm outline, with 2.85 mm minimum walls.
- The first model check found three clashes, each fixed: the lines against a 25 mm tail cap bore (now 30 mm with a 44 mm flange), the water tube 0.25 mm into the collar spigot (groove floor raised to 20 mm), and the tube's bend into the bite valve hitting the groove floor (pocket lengthened to 50 mm); a stand leg crossed the open case (stand moved).
- A variable-area flow meter reads only upright and must fit under the lid: it stands on a bracket at the end of the plate; the tallest part is 19 mm below the rim.
- With 3 m in the void and the tip unsupported, the operator must push down 34 N at the grip; in practice the tip must rest on debris beyond about 2 m. This is in the first checks.

### Safety concerns

- The water line is the main hazard: aspiration by a survivor who cannot drink safely. The bite valve, the capillary ceiling sized for twice the allowed height, the medical lead's direction and the rule never to connect a pump or pressurised container are the stops (build plan S5, S7).
- The blower's shut-off pressure is the only air pressure stop; it must be confirmed on the datasheet when bought and measured at a blocked tip before use (S4).
- Lathe work with an offset four-jaw set-up (nose, collar) and tube cutting (S1).
- LiFePO4 packs: fuse and lead out until the checks pass; charging away from the kit (S2, S3, S8).
- Structural: the operator stays outside the void; the probe is never a lever (S6).

### Kit notes (reported for the kit source, kit not edited)

- `.kit/concept.py` `cutaway_parts()` centres its cutting box on x = 0 and z = 0, so it removes nothing from parts far from the origin; `concept_media.py` moves the head to the origin before cutting.
- `.kit/concept.py` `export_web_model()` uses the default 0.001 mm glTF deflection and `Compound(children=...)`; `concept_media.py` calls `export_gltf` itself with `Compound([...])` and 1.0 mm and 0.35 rad deflection.

### Not done here

- Photoreal renders, captions, `media/render-*.png`, `media/card.png` and `media/social-preview.png`: made on Amish's Mac from the exported scenes. The README already leads with `media/render-hero.png`, so `render.py --check` warns until it exists.

### Recommended next step

The design looks ready for TRL 4: build the prototype to VDS-BLD-001 and run the first checks, starting with the parts in "To confirm when parts are bought", and approach the first co-design candidate so its medical lead can review the water line before any drill with a person at the tip. TRL 4 stays on hold under the portfolio cap until Amish lifts it.

## 2026-10-03: photoreal renders

Rendered with Blender Cycles on Amish's Mac from `cad/src/product_model.py`; captioned with `.kit/photo_caption.py`; `media/card.png` and `media/social-preview.png` made with `.kit/cards.py`. Views: hero, exploded, detail. image_qc passes and `render.py --check` has no FAIL.

## 2026-10-03: Amish's requirement decisions carried out

Amish chose option A on every requirement decision put to him: "1A 2A 3A 4A 5A 6A 7A 8A 9A 10A 11A". VoidScope's is decision 3A (R11): add a cable-steered articulating camera tip that bends up to 90° each way, controlled from the handle; restate R11 as "see around a 45-degree bend from a straight hole" with a verification method; keep the rigid rod, the air path and the water tube to the bite valve; check the tip still passes the 51 mm hole. Recorded in VDS-DDR-003 (`docs/decisions/0003-steerable-camera-tip.md`) and in the register VDS-DEC-001 v0.2. TRL cap respected; no commit or push, by instruction.

### Changes and their results

- **Steerable camera tip** (`cad/src/model.py`): the camera moves out of the nose into a turned tip housing on five pinned joints (turned base link in the nose, four PA12 links printed by SLS, 2 mm stainless pins, nested lugs with ends rounded about the pins), covered by a 0.6 mm silicone sheath. Each joint closes at 18.1°, so the tip bends 90° each way (VDS-CAL-001 J2, J3); posed at 90° each way in the model, no two links overlap (J7). The tip adds 140 mm ahead of the nose.
- **Steering**: two 0.6 mm stainless wires from crimped anchors in the tip housing, through every link, into two 3 mm PTFE-lined housings that run inside the rod bore (clear of the springs by 2.0 mm, the coupler bores by 0.95 mm, the cable by 6.0 mm) and up through two 4 mm holes in section 4 into a printed steering control clamped 8 mm ahead of the grip: 18 mm drum, 50 mm thumb lever, friction lock. 71° of lever gives 90° at the tip, 35° gives 45°; about 5 N at the thumb holds the full bend (J10, J11, J14).
- **Knock-on changes**: nose bored through with two M3 grub screw holes, the camera's lip and spacer ring gone; collar's lower side outlets moved from 225° and 315° to 240° and 300° so the housings pass, plus two housing stops in its front wall; one more hour of lathe time.
- **Constructability checks**: 180 of 180 pass (was 106), including every tip part inside the 48 mm head outline with the tip straight, each joint's lug clearances (0.2 mm) and pins, wires in their holes (0.3 mm), housings along the rod and the control's fits. STEP and STL regenerated.

### New result per requirement

- **R11 (restated in VDS-REQ-001 v0.4):** met on paper. 90° available each way against 45° needed; bent 45° the tip needs 83 mm to the side of the probe's line (J6), so it turns in the 300 mm test passage; the camera then points down the turned passage with 19 pixels across a 20 mm letter at 1 m (C2). Verification: test box with a 51 mm hole into a 300 mm passage turning 45° 0.5 m beyond it; read 20 mm letters 1 m down the turn, each side; straighten and withdraw.
- **R1:** still met with the tip locked straight, 48 mm (A1). The steering control, like the tail cap's air barb, is wider and stays outside the hole.
- **R2:** 4,131 mm can go into a void before the steering control reaches the hole (A4); 4,203 mm from the grip (A4g); target 4,000 mm.
- **R4:** by design, to test; the printed links and the thin sheath are the new weak points, so the drop tests should be run with the tip straight and bent.
- **R8:** Value-engineering target: USD 2,000. Estimated cost of the constructable design: USD 1,780 (USD 220 under the target). The tip added USD 202 (BOM lines 30 to 34 and line 29 raised to USD 240), each with its price basis in `bom/bom.csv`. `budget_usd` unchanged.
- **R9:** 2.2 min estimated (0.1 min added to check the steering); still needs timed drills.
- **Mass and handling:** probe 4.18 kg (was 3.66 kg); head 0.77 kg; buckling 940 N, 4.7 times a 200 N push; at 3 m unsupported 32 N at the grip and 2.33 on yield at a button hole. R3, R5, R6, R7, R10 and R12 are unchanged.

### Documents and pictures changed

- VDS-REQ-001 v0.4, VDS-CAL-001 v0.2 (new section J), VDS-BLD-001 v0.2, VDS-DEC-001 v0.2, VDS-DDR-003 v0.1 (new), `bom/bom.csv` (34 lines).
- General arrangement VDS-DWG-001 to Rev P3 (detail A now shows the head and tip in plan at 1:2.5). Making sketches VDS-DWG-101, 103 and 104 to Rev P2; new VDS-DWG-110 (bending link), 111 (base link), 112 (tip housing), 113 (steering control body) and 114 (drum and lever).
- Build plan pictures: overview, joint 3 (nose and base link), joint 5 subtitle, new joints 9 (bending section) and 10 (steering control), steps 3, 5, 6, 7, 8 and 11 redrawn for the tip and control, and steps 9, 10 and 12 to 17 redrawn (renumbered from 8 to 15).
- Concept media: hero, cutaway (head and tip), exploded view, `model.glb` and the concept blueprint VDS-DWG-010 to Rev P3.
- Appearance model `cad/src/product_model.py`: the tip is shown steered 45° (toward the viewer) in the hero and detail views and straight in the exploded view, with the steering control and red lever on section 4. Render scenes re-exported to `/home/claude/renders/voidscope`; the photoreal renders on Amish's Mac need re-running.

### Decisions proposed and awaiting Amish

- **Bite valve access (VDS-DEC-001, open decision 1). Proposed, awaiting Amish.** The valve stays on top of the nose as decision 3A asked, so the camera tip now extends 140 mm beyond it. Options: A, keep it there and steer the tip fully aside to offer water, confirmed in drills with the medical lead; B, carry the valve on a 60 mm flexible extension clipped along the sheath; C, move it onto the tip housing. Recommendation: A for the first prototype, B if drills find the valve hard to reach.

### Safety concerns

- The tip must be locked straight before it goes into or out of a hole (new safety stop S9); the wires are not self-locking, so a bent tip pulled back is straightened by the hole's edge rather than jamming, but it should not be relied on.
- The bent tip is not a tool for moving debris: the links are printed nylon (S9). A 30 N thumb push against the stop puts 83 N in a wire, a factor of 3.0 on its assumed breaking load (J15, J16); the wire's real breaking load is to confirm when bought (VDS-DEC-001, item 10).
- Giving water past the steered tip (open decision 1; build plan S7 now asks for the tip to be steered aside).

### Recommended next step

Amish to settle open decision 1. The design otherwise remains ready for TRL 4 under the portfolio cap: the R11 test box and the steering checks are added to the first checks in VDS-BLD-001.

## 2026-10-03: photoreal renders redone after Amish's requirement decisions

Rendered with Blender Cycles on Amish's Mac from `cad/src/product_model.py`; captioned with `.kit/photo_caption.py`; `media/card.png` and `media/social-preview.png` made with `.kit/cards.py`. Views: hero, exploded, detail. image_qc passes and `render.py --check` has no FAIL.

## 2026-10-03: Amish's round-2 requirement decisions carried out

Amish, 2026-10-03: "i agree with all the 46 recommendations you provided. please proceed." For VoidScope this is decision 3A on bite valve access, recorded in `docs/decisions/0004-bite-valve-on-the-nose.md` (VDS-DDR-004) and in the register `docs/06-design-decisions.md` (VDS-DEC-001 v0.3). A records and wording change only: no geometry, bill of materials, drawing or picture changed.

| Change | Files | New result |
| --- | --- | --- |
| Bite valve kept on the nose | none (no design change) | Valve 2 mm behind the nose front, tip 140 mm ahead; R5 and R11 as before |
| Drill card: steer the tip aside to give water | `docs/05-build-plan.md` v0.3, new section 5a; stop S7 points to it | The camera sits about 109 mm to the side and 51 mm ahead of the nose, so the valve is the foremost part |
| "Confirm in drills with the medical lead" | `docs/06-design-decisions.md` v0.3, To confirm item 14 | To confirm at TRL 4 |
| Open decision 1 closed | register v0.3, VDS-DDR-004 | Open decisions: none |
| Requirements wording | `docs/03-requirements.md` v0.5 (assumption only) | All results unchanged: R11 met on paper; R9 2.2 min estimated |
| Cost | unchanged | Value-engineering target: USD 2,000. Estimated cost of the constructable design: USD 1,780 (USD 220 under the target). `budget_usd` unchanged |

Mass unchanged (probe 4.18 kg). Pictures changed: none; the appearance model is unchanged and no views were re-exported.

### Patent screen list (to search before public release)

1. Combined search camera and supply probes (CPC search, from the TRL 2 screen).
2. **Articulating camera tips on search poles and borescope-style pinned-link bending sections (added 2026-10-03 under decision 3A).** The tip is a two-wire pinned-link bending section of a long-established kind, but the focused search should cover it before release. Not legal advice.

### Decisions proposed, awaiting Amish

None.

### Cross-repo actions

None.

### Safety

- Water is offered only on the medical lead's direction, in drills, to a person who can speak and drink, with the flow set from closed; the tip is steered aside only after it has been checked straight on the monitor and is straightened and locked afterwards.
- Stops S7 and S9 are unchanged in substance.

### Recommended next step

TRL 4 (R11 test box, steering checks, and the drill with the medical lead on valve reach) needs a new instruction from Amish.

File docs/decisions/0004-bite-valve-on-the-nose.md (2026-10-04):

---
doc_id: VDS-DDR-004
title: VoidScope bite valve kept on the nose
project: VoidScope
doc_type: Design decision record
version: "0.1"
status: Draft
date: '2026-10-03'
author: Amish Chadha
license: CERN-OHL-S-2.0
revisions:
- version: "0.1"
  date: '2026-10-03'
  author: Amish Chadha
  change: Amish's round-2 decision 3A on bite valve access recorded
---

# 0004: Bite valve kept on the nose; steer the tip aside to give water

- **Date:** 2026-10-03
- **Status:** decided by Amish, 2026-10-03 (round 2): "i agree with all the 46 recommendations you provided. please proceed." For VoidScope this is decision 3A, the open decision in VDS-DEC-001 v0.2.

## Context

The steerable camera tip (VDS-DDR-003) extends 140 mm beyond the nose. The bite valve stays on top of the nose, 2 mm behind its front, so a survivor reaches it past the tip and the bending section, whose top is 2.8 mm below the valve.

## Options considered

| Option | What it means |
| --- | --- |
| A (chosen) | Keep the valve on the nose. To offer water, the operator steers the tip fully to one side (the camera then sits 109 mm to the side and 51 mm ahead of the nose); the medical lead confirms in drills that a survivor can reach the valve |
| B | Carry the valve on a 60 mm flexible extension of the water tube clipped along the sheath |
| C | Move the valve onto the tip housing, running the water tube through the bending section (not recommended: the tube would flex at every bend and be harder to change and keep clean, R10) |

## Decision

Option A. No design change: the water line, nose and valve are as in VDS-DDR-003. The changes are written ones:

*Table 1. Changes.*

| Item | Was | Now |
| --- | --- | --- |
| Drill card | None | New: build plan section 5a, "steer the tip aside to give water" |
| Items to confirm | 13 | 14: "Confirm in drills with the medical lead" that a survivor can reach the valve past the steered-aside tip |
| Patent screen list | Focused search to cover articulating camera tips (concept note) | Also listed as an item in the review note, to be searched before public release |

## Consequences

| Item | Result |
| --- | --- |
| Requirements | None changed; R5 (water ceiling) and R11 as before |
| Cost and mass | Unchanged. Value-engineering target: USD 2,000. Estimated cost of the constructable design: USD 1,780 (USD 220 under the target). `budget_usd` unchanged |
| Risk | If drills show the valve is hard to reach, option B is the fallback (a clip and a 60 mm longer water tube) |

## Safety

> **Safety:** VoidScope delivers air and, in drills, water to a person who may be trapped; it carries a lithium iron phosphate battery. Water is offered only when the team's medical lead directs it, the person is conscious, can speak and can drink, and the flow is set from closed. The tip is locked straight before it goes into or out of a hole. It is an open engineering reference, not certified rescue equipment and not a medical device.

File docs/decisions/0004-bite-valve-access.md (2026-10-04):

---
doc_id: VDS-DDR-004
title: VoidScope bite valve access with the steerable tip
project: VoidScope
doc_type: Design decision record
version: "0.1"
status: Draft
date: '2026-10-03'
author: Amish Chadha
license: CERN-OHL-S-2.0
revisions:
- version: "0.1"
  date: '2026-10-03'
  author: Amish Chadha
  change: Amish's decision on register open decision 1 (portfolio decision 46) recorded
---

# 0004: Bite valve access with the steerable tip

- **Date:** 2026-10-03
- **Status:** decided by Amish Chadha, 2026-10-03: "i approve all of the 47 recommendations provided by you. Execute them." For VoidScope this is portfolio decision 46, the recommendation on open decision 1 of VDS-DEC-001 v0.2, taken exactly as worded: "A for the first prototype, B if drills find the valve hard to reach".

## Context

Decision 3A (VDS-DDR-003) added a cable-steered camera tip and kept the water line as it was, so the bite valve still sits in its pocket on top of the nose, 2 mm behind the nose front. The tip now extends 140 mm beyond the valve, and the top of the bending section lies 2.8 mm below it (VDS-DDR-003, T9). A survivor must reach the valve past the steered tip.

## Options considered

*Table 1. Options (no cost or mass stated for any).*

| Option | What it means |
| --- | --- |
| A | Keep the valve on the nose. To offer water the operator steers the tip fully to one side (the camera then sits 109 mm to the side and 51 mm ahead of the nose), and the medical lead confirms in drills that a survivor can reach the valve |
| B | Carry the valve on a 60 mm flexible extension of the water tube clipped along the sheath, so it is the foremost part when the tip is steered aside |
| C | Move the valve onto the tip housing, running the water tube through the bending section |

## Decision

**A for the first prototype; B if the drills find the valve hard to reach.** Nothing in the model, the BOM or the drawings changes. The water line, the capillary ceiling and the bite valve pocket stay as built in VDS-DDR-002 and VDS-DDR-003. The way water is offered changes in the documents:

- To offer water, the operator steers the camera tip fully to one side and locks it, so the bite valve on top of the nose is the foremost part a survivor can reach (build plan safety stop S7, concept VDS-PRC-001).
- A new first check in the build plan (section 5, "Bite valve access") is run in drills with the team's medical lead: a volunteer lying in a mock void reaches, pulls out and bites the valve past the steered tip, with the tip steered to each side.
- If the medical lead finds the valve hard to reach, option B (a 60 mm flexible extension clipped along the sheath) is the fallback. It comes back to Amish with what the drills found, its cost and its effect on the water set change time (R10).

## Consequences

*Table 2. Results.*

| Item | Result |
| --- | --- |
| Requirements | Unchanged: eleven of twelve met on paper, R9 estimated |
| Cost | USD 1,780, unchanged (value-engineering target USD 2,000) |
| Model, drawings, media | Unchanged; no re-render needed |

- With the tip steered fully aside, the camera looks sideways, 109 mm off the nose. It may no longer show the survivor's mouth while they drink, so the operator may have only the voice link to judge coughing or choking. The drills record whether a partly steered tip keeps the survivor in view and still leaves the valve within reach. This is a drill item for the medical lead, not a new decision.
- C stays not recommended: the water tube would flex at every bend and be harder to change and keep clean (R10).

## Safety

> **Safety:** Water can be inhaled by a survivor who is drowsy, injured or lying badly. The risk of aspiration is not reduced by this decision. Water is offered only under the direction of the team's medical lead, only to a conscious person who can speak and drink, only by the gravity drip through the bite valve with the capillary in the line, and never under pressure. The operator steers the tip aside and locks it before water is offered, keeps talking with the survivor while they drink, and shuts the roller clamp at any cough, choking or loss of response. Reaching the valve is confirmed in drills with the medical lead before any use. VoidScope is not certified rescue equipment and is not a medical device.

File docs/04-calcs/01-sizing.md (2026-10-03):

---
doc_id: VDS-CAL-001
title: VoidScope sizing calculations
project: VoidScope
doc_type: Calculation
version: "0.2"
status: Draft
date: '2026-10-03'
author: Amish Chadha
license: CERN-OHL-S-2.0
revisions:
- version: "0.1"
  date: '2026-10-03'
  author: Amish Chadha
  change: "First issue for TRL 3 on the constructable design (VDS-DDR-002): envelope and reach, rod structure and handling, vision, water, air, power, robustness, deployment, mass and cost"
- version: "0.2"
  date: '2026-10-03'
  author: Amish Chadha
  change: "Steerable camera tip (VDS-DDR-003, Amish's decision 3A): new section J for R11 as restated; envelope, reach, masses, handling, setup time and cost recomputed"
---

# VoidScope sizing calculations

On paper the constructable design, now with a steerable camera tip (VDS-DDR-003), meets eleven of its twelve requirements and estimates R9 within its target. The probe is 48 mm at its widest with the tip straight and goes 4.13 m into a void; the rod buckles at 940 N, 4.7 times a hard two-handed push. The tip bends up to 90° each way from a thumb lever, so the camera looks around a 45° bend with half its travel to spare (R11 as restated by Amish on 2026-10-03). The camera puts 19 pixels across a 20 mm letter at 1 m, twice what reading needs. The water ceiling is 1.5 mL/min at the allowed 1 m height at 20 °C and never more than 4.5 mL/min even at twice that height on a 40 °C day. The air path loses 0.38 kPa at 20 L/min, so the blower delivers 44 L/min at full speed while it can never put more than 0.9 kPa on a blocked tip. One battery pack runs video and light for 6.2 h at 20 °C and 4.3 h at -10 °C. The kit costs an estimated USD 1,780, USD 220 under the USD 2,000 value-engineering target. Every number in this note is printed by `docs/04-calcs/sizing.py`; the tag in brackets, for example [B3], is the line of that script's output that carries it.

> **Safety:** These are first-principles estimates for a paper proof of concept. They do not show that the probe is safe to use in a collapsed structure, that the water line is safe for a survivor, or that the battery is safe. The drip ceiling, the blocked-tip pressure and the snap-button pull strength must be measured on hardware before any use. VoidScope is not certified rescue equipment and not a medical device; see VDS-PRC-001, Safety.

## Scope and method

The note checks every requirement in VDS-REQ-001 v0.4 against the design in VDS-PRC-001 v0.3, as changed by VDS-DDR-003, and the parametric model `cad/src/model.py`. The script imports the model's `PARAMS` and `derived()` and builds the model once for part volumes, so the rod, head and case used here are the ones in the STEP files and in drawing VDS-DWG-001. It reads `bom/bom.csv` and `budget_usd` in `project.yaml`. Run it from the repo root with `python docs/04-calcs/sizing.py`; it also writes `docs/04-calcs/results.csv`.

The design case is a probe pushed horizontally or downward through a 51 mm core hole into a dark, dusty void, with the water bottle hung at most 1 m above the tip and the blower set to 20 L/min.

## Assumptions

*Table 1. Main assumptions.*

| Area | Assumption | Basis |
| --- | --- | --- |
| Rod | 6061-T6: E = 69 GPa, yield 240 MPa, density 2.7 g/cm³; stress concentration 3 at an 8.5 mm button hole | Handbook values |
| Loads | Two-handed push 200 N; pull to free a stuck probe 300 N | Assumed; to confirm in drills |
| Masses | Aluminium parts from model volumes; printed nylon (PA12) 0.95 g/cm³, stainless 7.9 g/cm³, silicone 1.15 g/cm³ from model volumes; camera 0.18 kg; cable 45 g/m; steering housings 25 g/m; PTFE guide, water tube and water from their sections; grip 0.15 kg; case 2.6 kg, pack 0.85 kg, monitor 0.6 kg | Catalogue-typical; to weigh at TRL 4 |
| Steering | Camera cable bending stiffness 5,000 N·mm²; housing friction coefficient 0.15 over 180° of bends; 0.6 mm 7x7 stainless wire rope breaks at 250 N; a firm thumb push is 30 N; printed PA12 yields at about 45 MPa | Assumed; the cable stiffness and wire strength to confirm when bought |
| Camera | 1920 pixels across a 90° horizontal view; 10 pixels needed across a letter; LEDs 60 lm in a 120° beam; minimum illumination 0.01 lx | Typical pipe-inspection head data; to confirm when bought |
| Dust | Extinction 0.5 per metre of path | Assumed for heavy suspended dust |
| Water | Poiseuille flow in a 0.5 mm by 600 mm capillary and 8 m of 2.5 mm tube; viscosity 1.52, 1.00 and 0.65 mPa·s at 5, 20 and 40 °C; bite valve and strainer losses ignored (they only lower the flow) | Laminar flow; standard water properties |
| Air | Smooth tubes (laminar or Blasius friction); minor loss 1.5 at each barb, 0.5 at each joint, 1.5 at the outlets; filter 2.5 Pa per L/min; flow meter 0.2 kPa at any flow (variable-area meters are near constant); blower curve shut-off 0.9 kPa and free flow 300 L/min, scaling with speed squared and speed | Screening values; the blower and flow meter figures are to confirm when bought |
| Power | Camera with LEDs 3 W; monitor and recorder 7 W; converter 90 %; blower 4 W at full speed, scaling with speed cubed, plus 0.3 W controller; amplifier standby 0.4 W | Typical module data |
| Battery | 12.8 V 6 Ah LiFePO4, 90 % usable, 70 % of capacity at -10 °C | Typical cell data |

## A. Envelope and reach (R1, R2)

With the tip locked straight the probe passes a 51 mm core hole along its whole length: the head, bending section and tip housing all lie inside 48 mm, the grip is 47 mm and the snap buttons stand 1.5 mm proud of the 38.1 mm rod [A1], leaving 1.5 mm a side at the head [A2]. The model checks every head part, the steerable tip included, inside the 48 mm outline. The steering control on section 4 is wider, but it sits behind the grip's front hand position and never enters the hole. The assembled probe is 4,538 mm long [A3]. The probe can go 4,131 mm into a void before the steering control reaches the hole [A4] (4,203 mm measured from the front of the grip [A4g]), so R2 is met with 131 mm to spare. The head is 313 mm long [A5], of which the steerable tip is the front 140 mm [A6].

## B. Rod structure and handling

The 38.1 x 1.47 mm tube has a second moment of area of 28,400 mm⁴ and a section modulus of 1,490 mm³ [B1, B2]. With couplers, steering housings and filled lines the rod weighs 0.65 kg per metre [B3]; the head weighs 0.77 kg [B4], of which 0.28 kg is the steerable tip ahead of the nose [B4t]. The steering housings, wires and control add 0.41 kg [B4s], and the assembled probe weighs 4.18 kg [B5].

*Table 2. Handling with the hole lip as the pivot and the tip hanging free.*

| Length in the void | Tip droop | Hand force at the grip | Tag |
| --- | --- | --- | --- |
| 1 m | 1.7 mm | 8.6 N lift | [B6a], [B71] |
| 2 m | 17 mm | 3.1 N push down | [B6b], [B72] |
| 3 m | not computed | 32 N push down | [B73] |

The rod is stiff enough to aim, and the operator holds it easily until about 2 m is in the void with nothing under the tip. Beyond that the hand force rises quickly, so in practice the tip should rest on debris; the build plan's first checks include it. At 3 m with the tip unsupported the moment at the hole lip is 51.2 N·m [B8], 34 MPa in the plain tube [B9] and 103 MPa at a button hole [B10], a factor of 2.33 on yield [B11].

The whole rod buckles, pinned at both ends, at 940 N [B12], 4.7 times a 200 N two-handed push [B13]. A 300 N pull to free a stuck probe bears 25.5 MPa on a button hole [B14], shears 3.4 MPa behind it [B15] and puts 11.9 MPa on the two coupler pins with no help from the epoxy [B16]. The button itself is a bought part; its pull strength is to be confirmed when bought (VDS-DEC-001).

## C. Vision (R3)

The camera head is the same bought unit, now carried in the tip housing. At 1 m it sees a 2,000 mm wide field [C1], which puts 19.2 pixels across a 20 mm letter [C2] against the 10 assumed to read it [C3]. The LEDs give about 19 lx on axis at 1 m [C4], about 1,900 times the sensor's minimum [C5], and about 7 lx after 2 m of heavily dusty air [C6]. R3 is met on paper; backscatter from dust close to the lens is the real risk and is a TRL 4 test.

## D. Water (R5, R10)

*Table 3. Drip ceiling with the clamp fully open (mL/min) [D1].*

| Water height above the tip | 5 °C | 20 °C | 40 °C |
| --- | --- | --- | --- |
| 0.5 m | 0.49 | 0.74 | 1.13 |
| 1.0 m (the allowed height) | 0.97 | 1.47 | 2.26 |
| 2.0 m (twice the allowed height) | 1.94 | 2.94 | 4.51 |

The capillary is sized conservatively: even with the bottle hung a metre too high on a 40 °C day, the flow cannot pass 4.51 mL/min [D2], under the 5 mL/min ceiling of R5. At the allowed 1 m and 20 °C the ceiling is 1.47 mL/min [D3], about 88 mL an hour [D4], or roughly 2 L a day; the roller clamp sets any lower rate down to zero. Without the capillary the same line would pass 70 mL/min [D6], which is why it is fitted and never removed. The primed line holds 39 mL [D5]; at most 19.6 kPa of water head sits behind the bite valve [D7], within what a hydration bite valve holds shut. Changing the water set takes about 4 minutes by the steps in [D8], within R10.

What would relax the ceiling: measured flows at the tip with the bought capillary, and the co-design medical lead's view of the rate a survivor should be offered. A shorter capillary could then raise the ceiling toward 5 mL/min at 1 m.

## E. Air (R6)

*Table 4. Pressure losses at 20 L/min [E1].*

| Part of the path | Loss (Pa) |
| --- | --- |
| Intake filter | 50 |
| Flow meter | 200 |
| Hose, 12 mm, 2.5 m | 55 |
| Two barbs (case outlet and tail cap) | 54 |
| Rod bore with four joints | 10 |
| Six outlets | 7 |
| Total | 376 |

The rod bore is a generous duct: it loses only 10 Pa. Most of the loss is in the flow meter and the filter. The air leaves the six outlets at 2.8 m/s [E2], gentle enough not to blast dust. With the assumed blower curve the system passes 44 L/min at full speed [E3], and the speed knob near 65 % [E4] gives 20 L/min. With every outlet blocked the pressure cannot exceed the blower's shut-off, 0.9 kPa [E5], under the 1 kPa limit of R6; this is why the blower is chosen by its shut-off pressure. Each coupler leaks about 0.08 L/min at 50 Pa [E6], negligible. At 20 L/min the blower draws 1.4 W [E7].

What would relax it: none is needed for R6. If the flow meter's real pressure drop is larger than 0.2 kPa, the flow at full speed falls; a flow meter with a lower drop is the fix.

## F. Power (R7)

Video and light draw 11.1 W at the battery [F1], 12.9 W with air and audio [F2]. One 76.8 Wh pack [F3] runs video and light for 6.2 h at 20 °C and 4.3 h at -10 °C [F4], meeting R7 at both temperatures; with air and audio it runs 5.4 h and 3.8 h [F5]. The two packs together give 7.5 h at -10 °C with everything on [F6]. The peak current is 1.4 A [F7], far below the 7.5 A fuse and the pack's rating.

## G. Robustness (R4)

A 1 m drop of the head and the first section together carries about 14 J [G1]. The nose keeps a minimum wall of 2.85 mm [G2]. The camera, already rated IP68, now sits in a 1.85 mm aluminium tip housing with its window recessed 3 mm behind the housing's front edge, and the bending section is covered by a replaceable 0.6 mm silicone sheath. The printed links and the sheath are the new weak points in a drop or against sharp rubble. R4 is met by design and is a TRL 4 test, now including drops with the tip bent and straight.

## H. Deployment (R9)

*Table 5. Setup time estimate, two people [H1 to H6].*

| Step | Minutes |
| --- | --- |
| Open both cases, lift out the rod bundle and head | 0.4 |
| Join the head and four sections (snap buttons) | 0.7 |
| Plug the camera cable, fit the air hose, hang the bottle | 0.6 |
| Switch on, check the picture and voice | 0.4 |
| Steer the tip both ways, lock it straight | 0.1 |
| Total | 2.2 |

The steering wires stay threaded with the other lines, so steering adds no connection, only a check.

## I. Mass and cost (R8)

The surface unit weighs about 6.2 kg with one pack fitted [I1]; with the 4.2 kg probe in its long case the kit is a two-person carry. The bill of materials prices the constructable design at USD 1,780 [I2]. Value-engineering target: USD 2,000 [I3]. Estimated cost of the constructable design: USD 1,780 (USD 220 under the target) [I4]. The steerable tip added USD 202: the printed links, pins and sheaths (USD 42), the base link (USD 6), the tip housing (USD 8), the wires and housings (USD 38), the steering control (USD 48) and one more hour of lathe time (USD 60). A builder with a lathe saves the USD 240 machining allowance, bringing it to USD 1,540 [I5].

## J. Steerable tip (R11, R1)

R11 as restated by Amish on 2026-10-03: see around a 45° bend from a straight hole. The tip is five pinned joints [J1] in a 66 mm bending section [J4] between the base link in the nose and the tip housing that carries the camera. Each joint's link faces close at 18.1° [J2], so with every joint closed the tip bends 90.4° each way [J3]; the lever's stops end the travel at 90°. The model was posed at 90° each way and no two neighbouring links overlap [J7]: the lug ends are rounded about their pins so a link face can swing past them.

*Table 6. Where the camera points (bend shared equally by the five joints).*

| Bend | Camera face, ahead of the nose front | Camera face, to the side | Sideways reach of the bent tip from the centreline | Tag |
| --- | --- | --- | --- | --- |
| 45° | 115 mm | 72 mm | 83 mm | [J5-45], [J6] |
| 90° | 51 mm | 109 mm | 109 mm | [J5-90], [J8] |

To look down a passage that turns 45°, the tip needs half its travel. Bent 45°, the camera points straight down the turned passage and its 90° field of view takes in everything from the line of the probe to 90° off it, so a 20 mm letter 1 m down the turned passage still gets 19 pixels [C2], nearly twice the 10 needed [C3]. The bent tip needs 83 mm to the side of the probe's line [J6], so it turns in any passage about 170 mm wide or wider; the R11 test passage is 300 mm wide. R11 is met on paper with 45° of bend to spare.

**Steering effort.** A 45° bend pulls in 11.1 mm of wire on the inside and pays out 10.9 mm on the outside [J9-45]; 90° pulls in 22.2 mm and pays out 21.6 mm [J9-90]. The 0.6 mm difference is taken up by the housings and needs no spring at this stage. On the 18 mm drum the lever turns 35° for 45° at the tip [J11] and 71° for 90° [J10]. Holding the camera cable bent 90° takes about 119 N·mm [J12], 8.5 N in the wire at the tip and 13.6 N at the drum with friction in the housings [J13], or about 5 N at the thumb on the 50 mm lever [J14].

**Strength.** A 30 N thumb push against the stop puts 83 N in the wire [J15], a factor of 3.0 on its assumed breaking load [J16], 13 MPa of shear in a joint's two 2 mm pins [J17] and 8.7 MPa of bearing on the printed lugs [J18], about a fifth of what PA12 takes. The lugs are the part to watch in drop and abrasion tests; the wire's breaking load is to confirm when bought.

**Getting out again (R1).** The friction lock only holds the lever; the wires are not self-locking. If the probe is withdrawn with the tip still bent, the hole's edge pushes the tip straight against at most a few newtons of wire tension. The procedure is still to steer straight and lock before pulling back through the hole.

What would relax it: a measured bending stiffness for the bought camera cable (a stiffer cable raises the thumb force, a softer one lowers it) and drop tests of the printed links. A two-plane tip (up and down as well) is possible later with four wires; one plane plus turning the rod covers R11.

## Results against requirements

*Table 7. Requirement status.*

| ID | Result | Status |
| --- | --- | --- |
| R1 | 48 mm largest diameter with the tip straight | Met |
| R2 | 4,131 mm into the void (4,203 mm from the grip) | Met |
| R3 | 19 pixels per letter; 7 lx in dust | Met on paper |
| R4 | IP68 camera in an aluminium tip housing; sheathed bending section; 2.85 mm minimum nose wall | By design, to test |
| R5 | Ceiling 1.47 mL/min at 1 m and 20 °C; 4.51 mL/min at most | Met |
| R6 | 44 L/min at full speed; 0.9 kPa blocked | Met |
| R7 | 6.2 h at 20 °C; 4.3 h at -10 °C | Met |
| R8 | USD 1,780 against the USD 2,000 target | USD 220 under the target |
| R9 | 2.2 min estimated | Estimate; timed drills needed |
| R10 | About 4 min, no tools | By design, to time |
| R11 | Tip bends 90° each way; 45° bend seen with 19 px per letter at 1 m; bent tip needs 83 mm to the side | Met on paper |
| R12 | Speaker and microphone on the head, about 0.2 m behind the camera | By design |

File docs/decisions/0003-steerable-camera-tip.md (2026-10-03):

---
doc_id: VDS-DDR-003
title: VoidScope steerable camera tip (R11)
project: VoidScope
doc_type: Design decision record
version: "0.1"
status: Draft
date: '2026-10-03'
author: Amish Chadha
license: CERN-OHL-S-2.0
revisions:
- version: "0.1"
  date: '2026-10-03'
  author: Amish Chadha
  change: "Amish's requirement decision 3A carried out: cable-steered camera tip, R11 restated, the changes it needed and their results"
---

# 0003: Steerable camera tip (R11)

- **Date:** 2026-10-03
- **Status:** accepted. Decided by Amish on 2026-10-03, who chose option A on every requirement decision put to him: "1A 2A 3A 4A 5A 6A 7A 8A 9A 10A 11A". Decision 3A is VoidScope's.

## Context

At TRL 3 the constructable design (VDS-DDR-002) met every requirement but R11, "pass a 4 m test channel with two 45° bends". The rigid rod goes straight only, and a flexible lead section had been left to a later version (VDS-DDR-001 D12). Option A, which Amish chose, keeps the rigid rod and instead lets the camera look around a bend: a cable-steered articulating camera tip that bends up to 90° each way, controlled from the handle, with R11 restated as "see around a 45-degree bend from a straight hole" and given a verification method. The rigid rod, the air path through its bore and the water tube to the bite valve stay as they are, and the tip must still pass the 51 mm hole.

## Options considered

The options were put to Amish with the requirement decisions; he chose A. The design choices below were made to carry A out.

*Table 1. How the tip is built: choices made.*

| Question | Options looked at | Chosen | Why |
| --- | --- | --- | --- |
| Bending section | Notched single tube (laser cut); rolling-contact links; pinned hinge links | Five pinned joints: a turned base link, four printed links and a turned tip housing, joined by 2 mm stainless pins | Pinned links can be printed by any SLS service and built with hand tools; a notched tube needs laser cutting and fatigues |
| Bending planes | One plane (two wires); two planes (four wires) | One plane, sideways (left and right of the bite valve) | R11 needs one plane; turning the rod picks the plane; two wires fit beside the existing lines, four would not |
| Where the camera goes | Keep it in the nose; move it to the tip | In a turned tip housing on the last joint, its window 3 mm behind the front edge | A camera behind the bend cannot see around it |
| How the wires reach the handle | Separate cable outside the rod; inside the rod bore | Two 3 mm PTFE-lined steel-coil housings inside the rod, stopping in the collar's front wall at the head end and in the control body at the handle | No loose cable outside; the housings stay threaded with the other lines (tent-pole storage) |
| Handle control | Bought borescope handle; drum and lever | A printed clamp body on section 4 ahead of the grip, with an 18 mm drum on a shaft, a thumb lever and a friction lock | Built from stock and printed parts; the lever sits where the rear hand's thumb reaches |
| Sealing the joints | Bare links; a sheath | A 0.6 mm silicone sheath over the bending section, replaceable, with a spare in the kit | Keeps grit out of the pins; the camera itself is already IP68 |

## Decision

*Table 2. Changes made to the model, the BOM and the calculations.*

| # | Before | Now | Why |
| --- | --- | --- | --- |
| T1 | Camera in the nose against a 26 mm lip, clamped by a rubber spacer ring | Camera in a tip housing (33 mm outside, 29.3 mm bore, 66 mm long) held by two nylon-tipped M3 grub screws; the spacer ring is gone | The camera must be ahead of the bend |
| T2 | Nose bore 29.3 mm from 12 to 72 mm, then the lip | Nose bore 29.3 mm right through; two M3 tapped holes near the front for the base link's grub screws | Takes the base link's spigot |
| T3 | Nothing ahead of the nose | Base link (turned, 29.25 mm spigot 14 mm into the nose, 33 mm flange), four printed PA12 links (33 mm outside, 23 mm bore, 10 mm bodies, 5.25 mm gaps), tip housing; ten 2 mm pins; nested lugs top and bottom with their ends rounded about the pins | Each joint closes at 18.1°, so five give 90° each way; the rounded lug ends keep neighbouring links clear at full bend (checked in the model at 90° each way) |
| T4 | No steering | Two 0.6 mm 7x7 stainless wires, 14 mm either side of the camera axis, from crimped anchors in the tip housing, through every link and a slanted hole in the base link, along the nose bore and through the collar's front wall into their housings | Pulling one wire bends the tip toward it |
| T5 | No housings in the rod | Two 3 mm housings in the rod bore 10.5 mm either side and 7.5 mm below the axis, clear of the snap button springs (2.0 mm), the coupler bores (0.95 mm), the cable (6.0 mm) and the guide tube (5.0 mm) | The only place in the bore below the spring strips that clears everything |
| T6 | Collar outlets at 0, 45, 135, 225, 270 and 315° | Lower side outlets moved to 240 and 300°; two 3.2 mm housing stops 2 mm deep in the plenum side of the front wall, 1.2 mm wire holes on through the spigot | The housings pass the outlets where 225 and 315° would have put the holes on top of them; six outlets of the same size, so the air path is unchanged |
| T7 | Section 4 plain behind the coupler | Two 4 mm holes on top of section 4, 332 and 368 mm from its back end | Where the housings leave the rod for the control |
| T8 | Nothing on the rod ahead of the grip | Steering control: printed PA12 clamp body 8 mm ahead of the grip, 18 mm aluminium drum on a 6 mm shaft between two cheeks, 50 mm thumb lever, friction lock knob, M4 clamp screw | 71° of lever gives 90° at the tip; about 5 N at the thumb holds it there |
| T9 | Bite valve ending 2 mm behind the nose front | Unchanged position, 2 mm behind the nose front; the tip now extends 140 mm beyond it | The water line is kept as Amish asked; access to the valve is a new open decision (VDS-DEC-001) |
| T10 | Lathe allowance 3 h (USD 180) | 4 h (USD 240) for the base link, tip housing and drum | Three more turned parts |

R11 is restated in VDS-REQ-001 v0.4: "see around a 45-degree bend from a straight hole", verified in a test box with a 51 mm hole into a 300 mm wide passage that turns 45° 0.5 m beyond the hole, reading 20 mm letters 1 m down the turned passage, to each side, then straightening the tip and withdrawing it.

## Consequences

*Table 3. Results (VDS-CAL-001 v0.2).*

| Requirement | Before | Now |
| --- | --- | --- |
| R11, see around a 45° bend (restated) | Not met (rigid rod, old wording) | Met on paper: 90° each way available, 45° needed; bent 45° the tip needs 83 mm to the side; 19 pixels across a 20 mm letter at 1 m |
| R1, 51 mm core hole | 48 mm | 48 mm with the tip locked straight; every tip part inside the outline in the model |
| R2, reach | 4,063 mm from the grip | 4,131 mm can go in before the steering control reaches the hole (4,203 mm from the grip) |
| R9, setup | 2.1 min | 2.2 min (0.1 min to check the steering) |
| R8, cost | USD 1,578 | USD 1,780: Value-engineering target: USD 2,000. Estimated cost of the constructable design: USD 1,780 (USD 220 under the target) |
| Probe mass | 3.66 kg | 4.18 kg (tip 0.28 kg ahead of the nose; housings, wires and control 0.41 kg) |
| Rod buckling | 1,001 N, 5.0 times a 200 N push | 940 N, 4.7 times (longer probe, heavier line) |
| Handling, 3 m unsupported | 34 N at the grip, 2.55 on yield at a button hole | 32 N at the grip, 2.33 on yield |

The model now runs 180 constructability checks, all passing. The new parts to watch at TRL 4 are the printed lugs (8.7 MPa bearing at a 30 N thumb push against the stop, about a fifth of PA12's strength), the 0.6 mm sheath against sharp rubble, the wire's breaking load (a factor of 3.0 assumed) and the camera cable's real bending stiffness, which sets the thumb force. The wires are not self-locking, so a bent tip straightens against the hole's edge if it is pulled back; the procedure is still to steer straight and lock before going in or out.

New for Amish: with the tip 140 mm ahead of the bite valve, the survivor reaches the valve past the camera tip. Options and a recommendation are in the design decisions register (VDS-DEC-001, open decision 1).

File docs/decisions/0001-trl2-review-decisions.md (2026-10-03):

---
doc_id: VDS-DDR-001
title: VoidScope TRL 2 review decisions
project: VoidScope
doc_type: Design decision record
version: "0.1"
status: Draft
date: '2026-10-03'
author: Amish Chadha
license: CERN-OHL-S-2.0
revisions:
- version: "0.1"
  date: '2026-10-03'
  author: Amish Chadha
  change: "TRL 2 review decisions, decided under Amish's 2026-10-03 pre-approval of the batch and its recommendations"
---

# 0001: TRL 2 review decisions

- **Date:** 2026-10-03
- **Status:** accepted. Decided by Amish under his pre-approval of 2026-10-03: "start with the first 14 repos from the list of 29 projects. I pre-approve the batch runs along with any recommendations you come up with. I also accept any cost overruns or variations from the assumed scope cost."

## Context

The TRL 2 populate step (session 2026-10-03, `docs/REVIEW.md`) answered the open questions of VDS-PRB-001 v0.1 and set the key design choices of VDS-PRC-001 v0.2. Under the normal rules each would be recorded as "Proposed, awaiting Amish". Amish pre-approved every recommendation in this batch run, so each item below is recorded as decided, with its options and the reason for the choice. Choices that touch safety take the conservative option and state what evidence would relax them. Partners and regions are recorded as the first candidate to approach, not as agreed. The TRL 2 approval that the TRL 3 step needs is the same instruction.

## Options considered

*Table 1. Options for each item.*

| # | Item | Options | Chosen |
| --- | --- | --- | --- |
| D1 | Where the water and air lines run | Alongside the rod in clips; inside, each in its own tube; inside, with the rod bore as the air duct and the water in a guide tube | Inside, bore as air duct, water tube in a PTFE guide tube |
| D2 | Rod and joints | Telescopic carbon pole; threaded sections; sections with internal couplers and snap buttons | 6061-T6 tube 38.1 x 1.47 mm in four 1,050 mm sections, internal couplers, V-spring snap buttons, lines left threaded through (tent-pole storage) |
| D3 | Head articulation | Articulating head; fixed head aimed by turning the rod | Fixed head, about 90° view, aimed by turning the rod; articulation left for a later version (cost and patent risk) |
| D4 | Camera | Bare board camera in a self-made sealed head; bought sealed pipe-inspection head in a machined nose | Bought IP68 29 mm AHD 1080p head with 12 LEDs, in a turned aluminium nose |
| D5 | Display | Handheld screen on its own cable; monitor in the surface unit lid; phone or tablet over USB | 7 in AHD monitor with recorder in the lid of the surface unit (one battery, one cable; USB does not reach 7 m) |
| D6 | Audio | None; separate microphone and speaker; one speaker used as both, with push-to-talk | One 20 mm IP67 speaker at the tip used as speaker and microphone, push-to-talk headset at the surface (fitted, not optional, because talk is how the crew judges consciousness before water) |
| D7 | Water delivery | Open drip tip with a roller clamp; IV-style drip set; gravity drip with a fixed capillary ceiling, roller clamp and a bite valve | Gravity drip: bottle, strainer, 600 mm x 0.5 mm capillary, roller clamp, priming stopcock, single-use tube, bite valve parked in the nose |
| D8 | Air supply | Hand bellows; diaphragm pump with a relief valve; centrifugal blower with shut-off at or below 1 kPa | 12 V centrifugal blower chosen by its shut-off pressure, intake filter, flow meter, speed knob |
| D9 | Power | AA cells; power-tool packs; 12.8 V LiFePO4 packs | Two 12.8 V 6 Ah LiFePO4 packs with built-in protection, one fitted and one spare |
| D10 | Tethered crawler block | Share the proposed crawler head interface; stay independent | Independent; no shared head interface, so the RedZone tether odometry question does not arise |
| D11 | Co-design partner and region | Any accredited USAR team; a national fire or civil protection training school in an earthquake-prone country | First candidate to approach: the disaster management training school of the Armed Police Force, Nepal; second: Turkey's AFAD training centres. Not contacted; not partners |
| D12 | Requirements | Keep the TRL 1 set; restate | R2 split into reach (R2) and bends (R11); R5 as a ceiling with a bite valve; R6 adds a blocked-tip limit; R8 as a value-engineering target; R12 two-way voice added |
| D13 | Budget, pitch and problem | Change; keep | Kept: `budget_usd` stays at USD 2,000 as a value-engineering target; pitch and problem unchanged |

## Decision

All items D1 to D13 are decided as chosen in Table 1, by Amish under his 2026-10-03 pre-approval.

*Table 2. Safety choices taken on the conservative side, and what would relax them.*

| # | Conservative choice | Evidence that would relax it |
| --- | --- | --- |
| S1 | Drip ceiling sized for a 2 m water height at 40 °C (twice the allowed height), giving 1.5 mL/min at the normal 1 m and 20 °C | Measured flows at the tip with the bought capillary, and the co-design medical lead's view of the rate to offer |
| S2 | Water only through a bite valve, never an open drip tip | A written medical protocol from the co-design partner that allows another mouthpiece |
| S3 | Blower chosen by shut-off pressure (at most 1 kPa), with no relief valve to fail | None needed; a measured blocked-tip pressure at TRL 4 confirms it |
| S4 | Audio fitted as standard, so the crew can judge consciousness before water | The medical lead's view that another check is enough |
| S5 | LiFePO4 packs with built-in protection, charged only away from the kit | None; this is the lowest-risk common lithium chemistry |
| S6 | The probe is never used as a lever or pry bar; the 300 N pull and 200 N push are the design loads | Measured joint and button strength at TRL 4 |

## Consequences

- VDS-PRB-001 v0.2, VDS-PRC-001 v0.2 and VDS-REQ-001 v0.2 carry these decisions; the TRL 3 versions (v0.3) add the constructable design of VDS-DDR-002.
- R11 (bends) is not met by D2 and D3; it is recorded as a requirement not met, not redesigned at TRL 3.
- `project.yaml`: only the TRL fields, `design_state` and the evidence list change. `budget_usd`, the pitch and the problem are unchanged.
- Nothing here authorizes building or testing; TRL 4 is capped.

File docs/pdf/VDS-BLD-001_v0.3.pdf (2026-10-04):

VO I D S C O P E · B U I L D P L A N

# VoidScope prototype build plan

Design Molecule Lab · designmolecule.com

D O C U M E N T CO N T RO L

Document ID | VDS-BLD-001 | Version | 0.3
Status | Draft | Date | 2026-10-03
Author | Amish Chadha | License | CERN-OHL-S-2.0
Project TRL | TRL 3 | Proof of concept
Repository | github.com/BoujeeEnjinia1701/voidscope
Source | docs/05-build-plan.md @ uncommitted

R EV I S I O N H I STO RY

Version | Date | Author | Change
0.3 | 2026-10-03 | Amish Chadha | Drill card added with the rule to steer the tip aside to give water (Amish's round-2 decision 3A, VDS-DDR-004)
0.2 | 2026-10-03 | Amish Chadha | Steerable camera tip and steering control added (VDS-DDR-003, Amish's decision 3A); new sketches, joints and steps
0.1 | 2026-10-03 | Amish Chadha | First build plan; design made constructable (VDS-DDR-002)

D R A F T · N O T F O R F A B R I C A T I O N

## VoidScope prototype build plan

Plan, not yet built. How to build the first proof-of-concept prototype, component by component. Building and testing to it is TRL 4 work. Decisions are kept in the design decisions register (docs/06-design-decisions.md), not here.

### 1. What you are building


Figure 1. Every component pulled apart and numbered in build order. The rod sections lie side by side as they are stored; the cable, tubes, steering housings and wires are drawn cut short.
The prototype is a 4.5 m camera probe and its surface unit. The probe is four aluminium tube sections that click together with snap buttons, a turned aluminium head holding a small speaker and a bite valve, a camera tip ahead of the head that bends up to 90° to either side, a steering lever on the rod just ahead of the grip, and a turned tail cap where the air goes in. The camera cable, a guide tube for the water and two steering wires in their housings stay threaded through the sections. The surface unit is a bought hard case holding a battery, a blower, a flow meter and small control modules, with a monitor in its lid; a water bottle hangs on a light stand beside it. Figure 1 shows the 24 components in the order you make or fit them. Fourteen are made: the rod sections, couplers, collar, nose, base link, tip housing, steering drum and tail cap (tube cutting, drilling and lathe work), the bending links and the steering control body (printed in nylon by a print service), the equipment plate and two small brackets (sheet and angle), and the drilled case. The rest are bought and fitted. The parts cost about USD 1,780 from the bill of materials.

Safety: VoidScope is rescue equipment for trained teams; this prototype is not certified and it is not a medical device. The battery packs are 12.8 V lithium iron phosphate: keep the battery lead unplugged and the fuse out until section 6 says otherwise, and charge packs only on their own charger, on a non-combustible surface. Turning, drilling and cutting tube throw chips and leave sharp edges: wear safety glasses, keep hair and sleeves clear of the lathe chuck, and deburr everything. Cut steering wire ends are sharp; crimp or tape them at once. The water line must never be connected to a pump or a pressurised container, and the capillary is never removed. Two-part epoxy and threadlocker need gloves and ventilation.

### 2. What changed to make it buildable

The concept showed what the probe does; it did not say how the sections join, how the lines cross the joints or how the head fits everything inside 48 mm. Each change keeps what VoidScope does, and all of them are recorded in decision record VDS-DDR-002.
Table 1. Changes from the concept.

Component | The concept had | The buildable design has | Why
Rod and joints | A rod about 50 mm across in about 1 m sections; joints not defined | 38.1 mm tube in four 1,050 mm sections, a 34.93 mm coupler bonded and pinned in each, locked by a snap button (Figure 3) | The two stock tube sizes slide together by hand, and the thinner rod leaves room for the head
Lines | Connectors at each joint | Cable and guide tube stay threaded through every section, like the cord in a tent pole | No connectors inside the rod; setup is four clicks
Air | A separate air line | The rod's own bore carries the air | Far less pressure loss; the joints need no seals
Water | A line inside the rod | A guide tube the single-use water tube pushes through (Figure 9) | The water set changes in about 4 minutes, no tools
Head | One sealed piece | A turned collar and nose joined by three screws; camera set 6.5 mm below the centre; a 20 mm speaker (Figures 5 to 8) | Each part turns on a small lathe; the bite valve and speaker fit inside 48 mm
Display | A handheld screen | A monitor in the lid of the surface unit (Figure 16) | One battery and one cable; the crew's hands stay on the rod
Surface unit | Not laid out | An equipment plate on spacers, an upright flow meter, sealed wall fittings (Figure 13) | The case stays sealed and the lid still closes
Details found by checking the model | A 25 mm tail cap bore, a water groove 0.5 mm too deep, a short valve pocket | A 30 mm bore with a 44 mm flange, the groove floor 20 mm from the centre, a 50 mm pocket | Each part now clears its neighbours
Camera tip | A rigid head; the camera behind a lip in the nose | A camera tip on five pinned joints that bends up to 90° to either side, steered by two wires from a thumb lever on the rod (Figures 18 to 24) | Amish's decision 3A: the camera must see around a 45° bend from a straight hole
Collar outlets | Lower outlets at 225° and 315° | Lower outlets at 240° and 300°; two stops for the steering housings in the front wall (Figure 4) | The steering housings pass where the old outlets were
Hinge lugs | Square lug ends | Lug ends rounded about their pins | With square ends the neighbouring link hit the lug before the full 90° bend

### 3. Making the components

Make and check each component before the assembly step that needs it. Sizes are in millimetres. "Top" is the side the bite valve pocket is on; the tip bends to the left and right of it; the "button line" is a straight line scribed along every section and coupler, on the right side as seen from behind the tail cap, so all the buttons line up. Workshop tolerance is 0.2 mm on turned diameters and 0.5 mm elsewhere unless a step says otherwise; drawings do not carry tolerances before TRL 4.

### 3.1 Rod sections (make 4)

Figure 2. Rod section making sketch (VDS-DWG-101).
What it is and what it is made from. The four straight lengths of the probe. Each is 6061-T6 drawn aluminium tube, 38.1 mm (1.5 in) outside with a 1.47 mm (0.058 in) wall, 1,050 mm long.
How to make it.
Cut four lengths of 1,050 mm, square, with a fine-tooth saw or a tube cutter. Number them 1 to 4; section 1 goes next to the head.
Deburr both ends inside and out. The inside edge must be smooth, because the cable slides past it.
Scribe the button line along each tube with a straight edge.
Sections 1, 2 and 3: on the button line, 30 mm from the back end, drill an 8.5 mm hole (start with 3 mm, then step up). The next section's snap button comes through this hole.
Section 4: no button hole at the back. The tail cap pins go through it in step 2. On top of section 4, drill two 4 mm holes for the steering housings: one 332 mm from the back end and 10.5 mm to the button-line side of the top line, the other 368 mm from the back end and 10.5 mm to the other side.
Mark depth bands every 100 mm, counting from the tip of the assembled probe, and the section number at each end, with a paint marker. Cover each section with clear heat-shrink.

How it fits the parts next to it. The front end of each section takes a coupler, bonded in for 60 mm (Figure 3). The back end slides over the coupler of the section behind it until the two tube ends butt; the snap button pops through the 8.5 mm hole. Section 1's front coupler goes into the collar instead.

1.

2.
3.
4.

5.

6.

Check before moving on. A coupler slides into each back end by hand without rocking, and all four sections are 1,050 mm within 0.5 mm. On section 4 the two housing holes are deburred inside, so the housings are not cut.

### 3.2 Couplers with snap buttons (make 4)

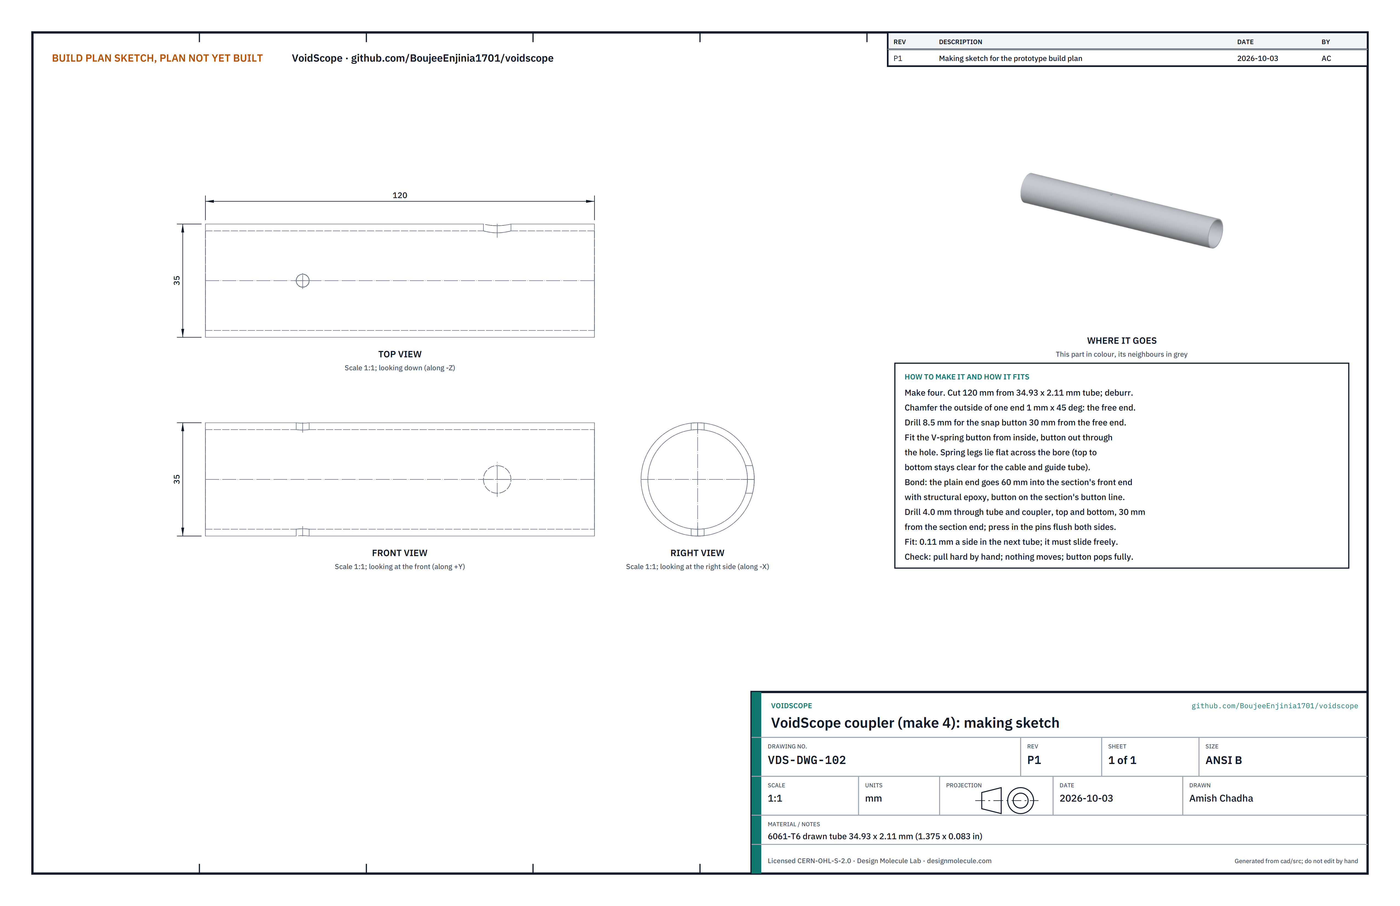
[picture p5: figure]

Figure 3a. Coupler making sketch (VDS-DWG-102).
What it is and what it is made from. The short inner tube that joins two sections. 6061-T6 tube, 34.93 mm (1.375 in) outside with a 2.11 mm (0.083 in) wall, 120 mm long; a stainless V-spring snap button with an 8 mm button; two 4 mm aluminium pins.
How to make it.
Cut four 120 mm lengths; deburr. Chamfer the outside of one end 1 mm at 45°: this is the free end.
Scribe a button line along each. On it, 30 mm from the free end, drill an 8.5 mm hole.
Squeeze the V-spring and slide it in from the plain end, button first, until the button snaps out through the hole. The spring strip lies across the bore from the button side to the opposite side; the spaces above and below it are where the cable and guide tube pass.
Bond: clean the plain end and the inside of the section's front end with solvent, coat both with structural epoxy, and push the coupler 60 mm into the section with the two button lines in line. Wipe off the squeeze-out inside. Before the epoxy sets, drill 4.0 mm through tube and coupler at the top and the bottom, 30 mm from the section's front end, and press in the two pins flush both sides. Leave to cure for 24 hours.

How it fits the parts next to it.

1.
2.
3.

4.

5.

Figure 3. The coupler is bonded and pinned into one section and slides into the next; the tube ends butt and the button locks. The cable and guide tube pass above and below the spring.
The coupler's outside slides inside the next tube with about 0.11 mm a side. Push loads go through the butted tube ends; pull and twist go through the button. The spring sits 3.0 mm from the cable and 2.0 mm from the guide tube. Check before moving on. Each joint clicks together and comes apart with one press of the button; a hard pull by hand moves nothing.

### 3.3 Collar

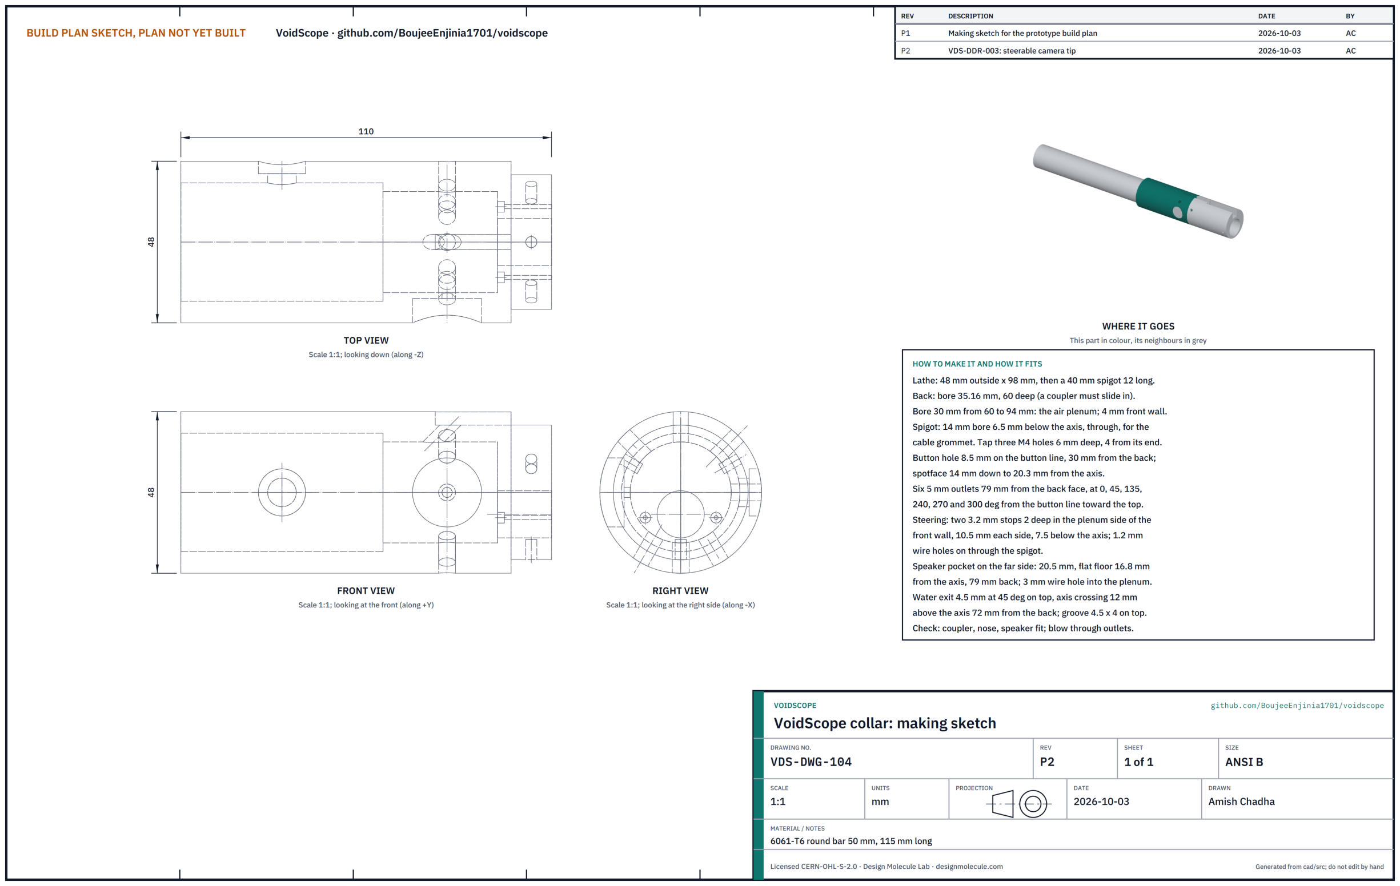
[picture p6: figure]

Figure 4. Collar making sketch (VDS-DWG-104).
What it is and what it is made from. The back half of the head: it takes the first rod section, turns the air out through six holes, holds the speaker, lets the water tube out and carries the nose. 6061-T6 round bar, 50 mm, 115 mm long.
How to make it.
On the lathe, turn to 48 mm outside for 98 mm and a 40 mm spigot 12 mm long at the front; part off.
From the back face, bore 35.16 mm, 60 mm deep, so a coupler slides in. Then bore 30 mm on to 94 mm from the back face: the air chamber. Leave a 4 mm front wall.
Through the spigot, bore 14 mm on a centre 6.5 mm below the axis (offset in a four-jaw chuck, or drill and ream on a drill press with the collar in a vee block). This takes the cable grommet.
Tap three M4 holes 6 mm deep into the spigot, 4 mm from its front end, at the positions on the sketch.
On the button line, 30 mm from the back face, drill 8.5 mm, then spotface 14 mm across until the floor is 20.3 mm from the axis, so a fingertip reaches the button.
Drill six 5 mm air holes into the chamber, 79 mm from the back face: on the button line, at 45° and 135° above it, and at 240°, 270° and 300° (bottom and the lower side).
On the side opposite the button line, at 79 mm from the back face, mill a 20.5 mm flat-bottomed pocket down to 16.8 mm from the axis for the speaker; drill a 3 mm wire hole from its floor into the chamber.

1.
2.

3.

4.
5.

6.

7.

On top, drill the 4.5 mm water exit at 45° through into the chamber, its axis crossing 12 mm above the axis at 72 mm from the back face (use a 45° vee block on the drill press). Mill a groove 4.5 mm wide on top from the exit to the front face, its floor 20 mm above the axis.
For the steering, from inside the chamber, counterbore two 3.2 mm holes 2 mm deep into the front wall, each 10.5 mm to one side of the centre and 7.5 mm below it; the housings end in these. Through the middle of each, drill 1.2 mm on through the wall and the spigot for the wire.
Deburr every hole inside and out; the water tube, the wires and the air must meet no sharp edge.

How it fits the parts next to it.

Figure 5. Section 1's coupler slides into the collar socket until the tube butts the collar; the button stands just proud in its spotface.

8.

9.

10.

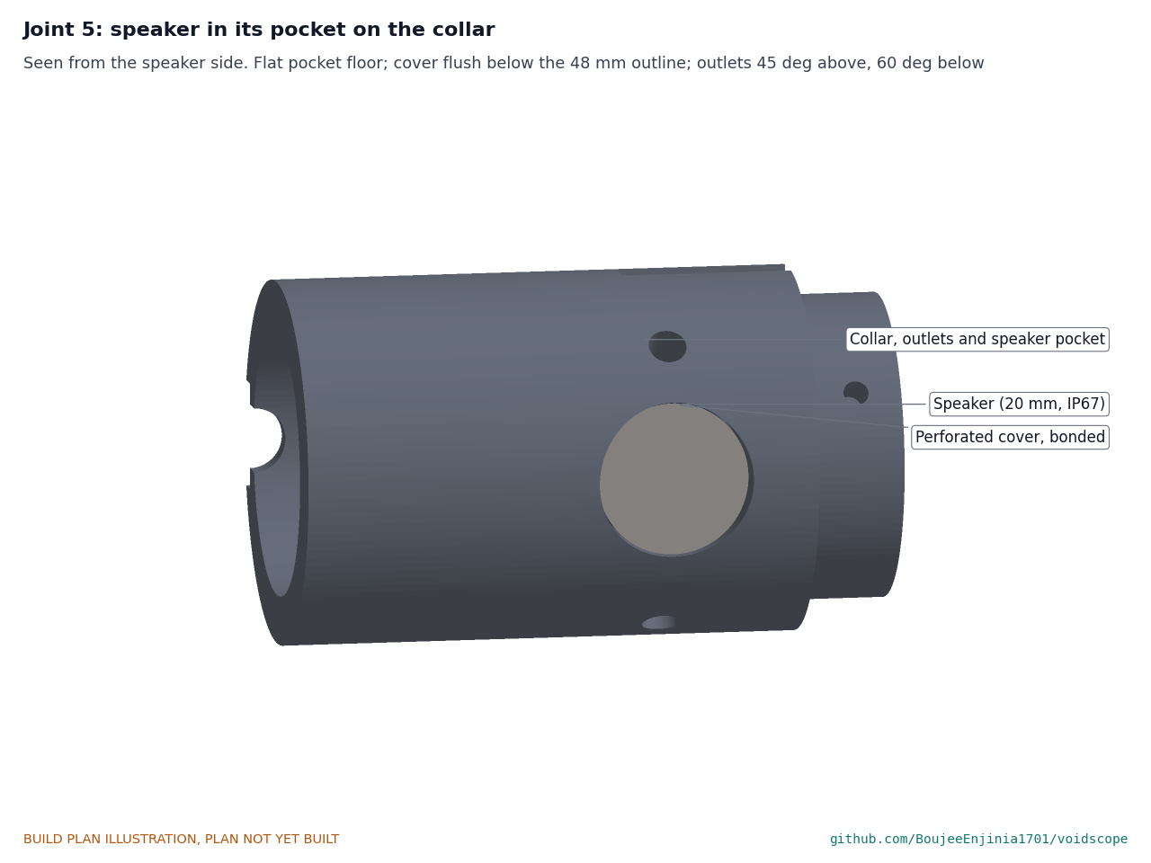
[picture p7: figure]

Figure 6. The 20 mm speaker sits on the flat floor of its pocket under a bonded perforated cover, flush inside the 48 mm outline; air holes lie 45° above it and 60° below it.
The socket takes section 1 exactly like a rod joint. The 40 mm spigot fits the nose's 40.2 mm counterbore. The speaker is bedded in neutral-cure silicone and its cover bonded on top.
Check before moving on. A coupler slides into the socket and the button pops into the spotface. Air blown into the socket comes out of all six holes.

### 3.4 Nose

Figure 7. Nose making sketch (VDS-DWG-103).
What it is and what it is made from. The front of the head: it carries the steerable camera tip in its bore and parks the bite valve on top. 6061-T6 round bar, 50 mm, 80 mm long.
How to make it.
Turn to 48 mm outside and 75 mm long. From the back face, bore 40.2 mm, 12 mm deep, to fit the collar spigot. Set the work 6.5 mm off centre in a four-jaw chuck, the offset away from the top. Bore 29.3 mm from 12 mm from the back face right through the front. The thinnest wall is 2.85 mm, at the bottom.
On top, cut the bite valve pocket: 11.5 mm wide, its floor 12 mm above the axis, 50 mm long, open at the front. A mill is best; a saw and file will do.
Continue a groove 4.5 mm wide on top, floor 20 mm above the axis, from the back face to the pocket. Over the counterbore it breaks through; that is intended.
Drill three 4.5 mm holes 6 mm from the back face at the same angles as the tapped holes in the spigot, and countersink them for M4 screws.
On the two sides, 7 mm back from the front face and level with the bore's centre, drill and tap M3 into the bore for the base link's grub screws.
Break every edge by 0.5 mm, especially at the front and the pocket.

How it fits the parts next to it.

1.
2.

3.

4.

5.

6.

7.

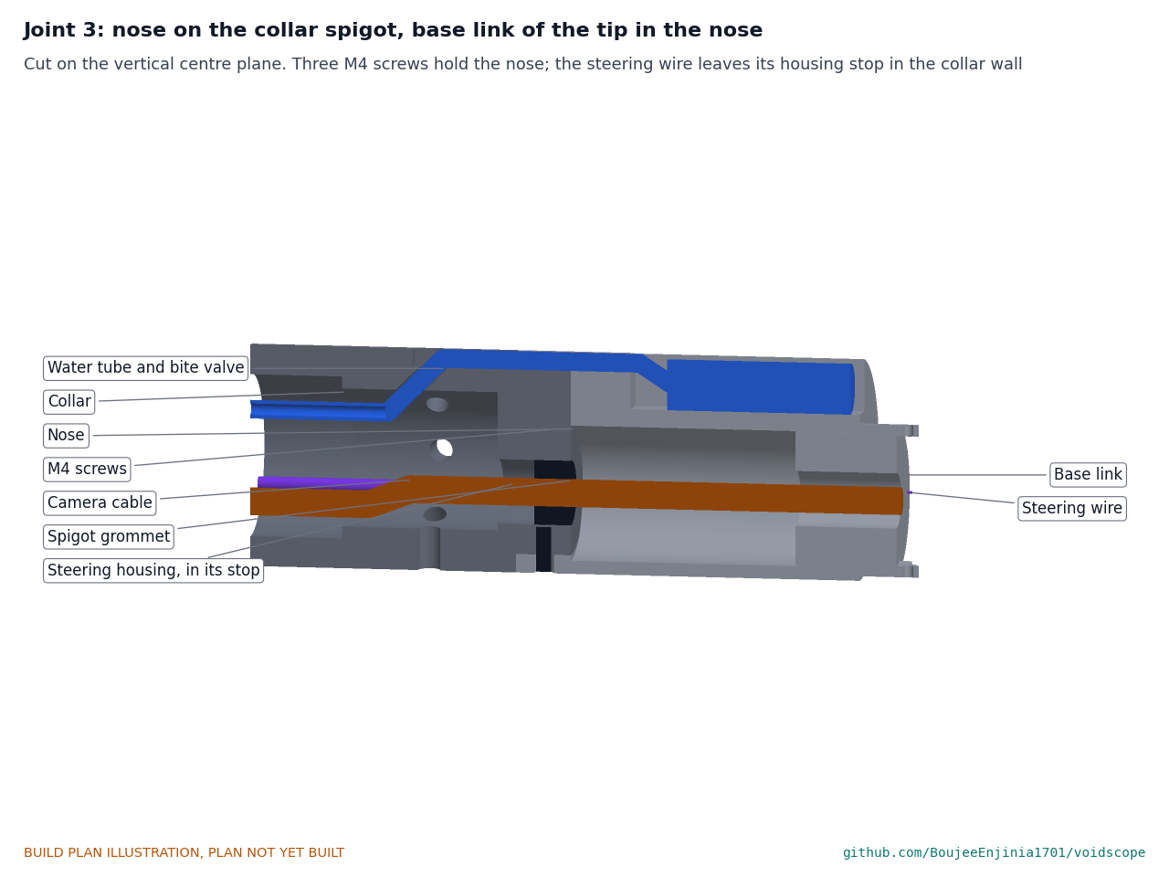
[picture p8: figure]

Figure 8. Three M4 screws hold the nose on the spigot. The base link of the camera tip slides into the front of the nose bore and two M3 grub screws hold it. A steering wire leaves its housing in the collar wall and runs along the nose bore into the base link.

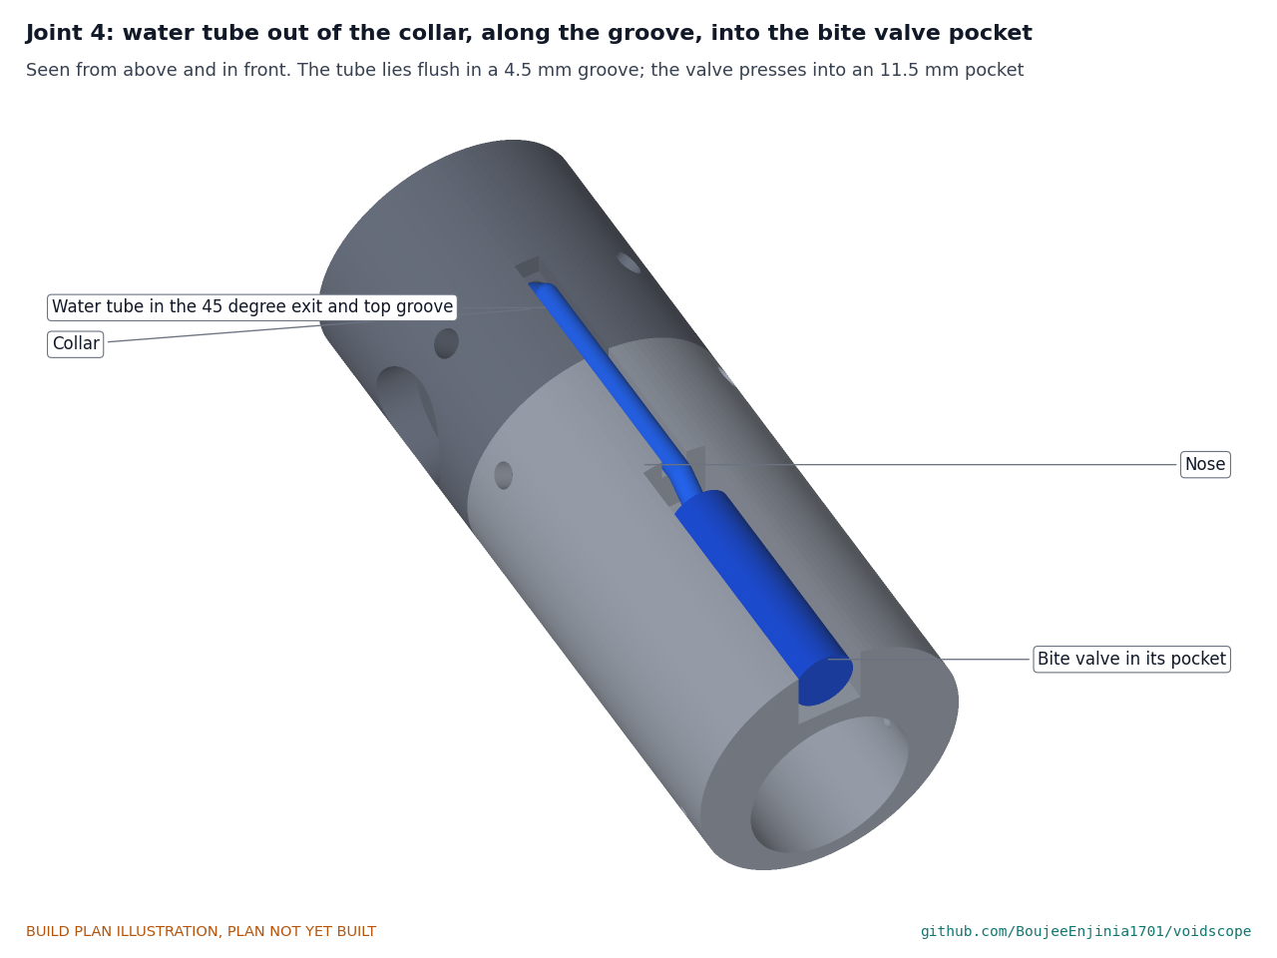
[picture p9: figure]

Figure 9. The water tube leaves the collar through the 45° exit, lies flush in the top groove and ends in the bite valve, pressed into its pocket on the nose.
Check before moving on. The base link's spigot slides into the front of the bore by hand without rocking. The nose slides onto the spigot and the three screw holes line up. A bite valve presses into the pocket and stays there when the nose is shaken.
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

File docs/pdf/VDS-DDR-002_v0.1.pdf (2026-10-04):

VO I D S C O P E · D E S I G N D E C I S I O N R E C O R D

# VoidScope design for construction

### Design Molecule Lab · designmolecule.com

D O C U M E N T CO N T RO L

Document ID | VDS-DDR-002 | Version | 0.1
Status | Draft | Date | 2026-10-03
Author | Amish Chadha | License | CERN-OHL-S-2.0
Project TRL | TRL 3 | Proof of concept
Repository | github.com/BoujeeEnjinia1701/voidscope
Source | docs/decisions/0002-design-for-construction.md @ uncommitted

R EV I S I O N H I STO RY

Version | Date | Author | Change
0.1 | 2026-10-03 | Amish Chadha

Changes that make the TRL 2 concept physically buildable, with the reason for each; decided under Amish's 2026-10-03 pre-approval

D R A F T · N O T F O R F A B R I C A T I O N

# 0002: Design for construction

Date: 2026-10-03
Status: accepted. Decided by Amish under his pre-approval of 2026-10-03: "I pre-approve the batch runs along with any recommendations you come up with. I also accept any cost overruns or variations from the assumed scope cost."
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

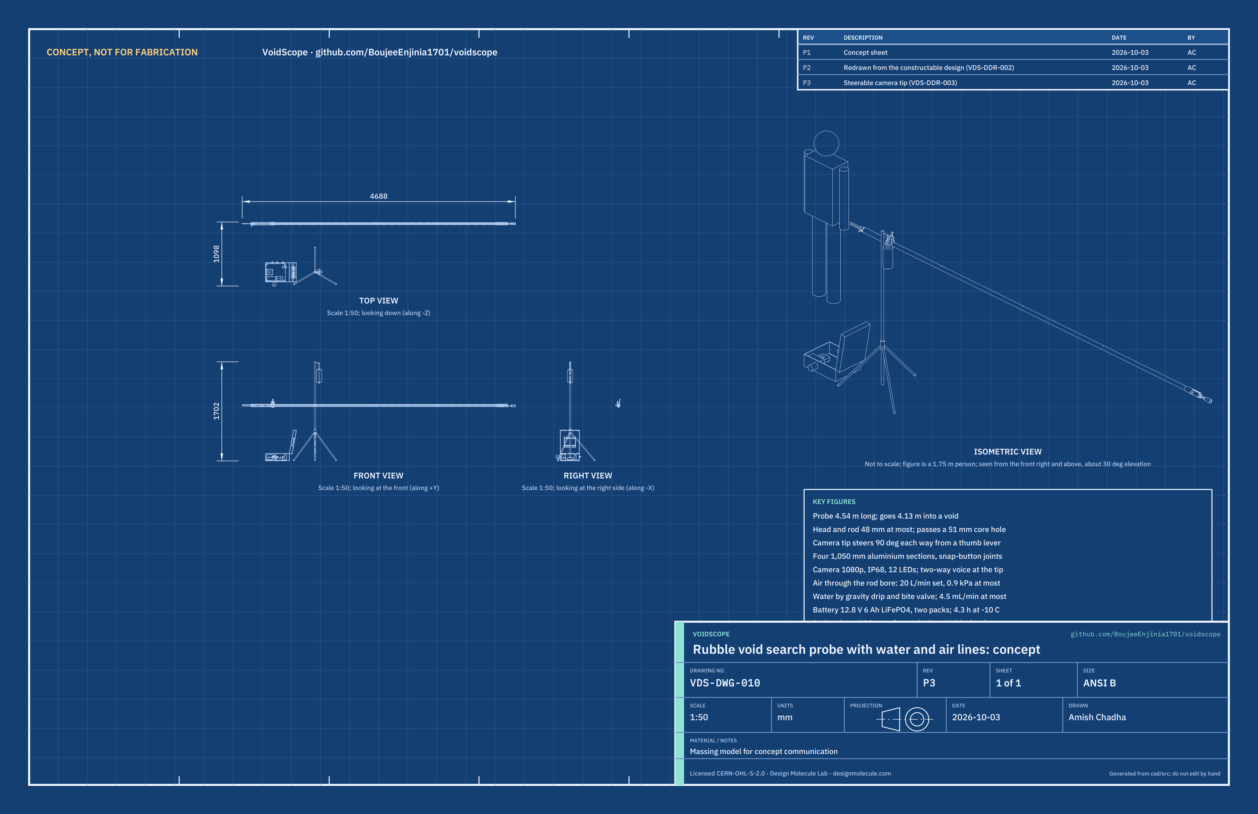
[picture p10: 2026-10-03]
media/concept-blueprint.png

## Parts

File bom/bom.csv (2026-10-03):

item | qty | spec | supplier | unit_cost_usd | make_buy | notes
1 Camera head | 1 | Sealed pipe-inspection camera head, 29 mm diameter by about 55 mm long, IP68 (1 m for 30 min or better), AHD 1080p with a low-light 1/2.9 in sensor, about 90 degree horizontal view, 12 white LEDs around the lens with dimming, 12 V supply, short pigtail lead | Pipe-inspection camera maker via an online electronics marketplace or a drain-camera spares distributor | 95.00 | buy | Indicative price; shut-off and LED drive per maker; diameter and length to confirm when bought (VDS-DEC-001, To confirm 1)
2 Nose | 1 | Turned from 50 mm 6061-T6 round bar, 75 mm long; 48 mm outside; 40.2 mm counterbore 12 mm deep; 29.3 mm bore 6.5 mm below the axis, through, taking the base link of the steerable tip; two M3 tapped holes for its grub screws; bite valve pocket 11.5 mm wide on top; water groove; three 4.5 mm countersunk holes | Metal stockist (bar cut to length) | 9.00 | make | Material price; lathe and mill or drill work per VDS-DWG-103
3 Collar with air outlets | 1 | Turned from 50 mm 6061-T6 round bar, 110 mm long; 48 mm outside, 40 mm spigot; 35.16 mm socket 60 mm deep; 30 mm plenum; six 5 mm outlets; 20.5 mm speaker pocket; 4.5 mm water exit at 45 degrees; 8.5 mm button hole with a 14 mm spotface; three M4 tapped holes; 14 mm spigot bore with a rubber grommet; two 3.2 mm steering housing stops 2 mm deep in the front wall with 1.2 mm wire holes on through the spigot | Metal stockist (bar cut to length); grommet from a hardware store | 13.00 | make | Material and grommet; lathe and drill work per VDS-DWG-104
4 Speaker with cover | 1 | 20 mm waterproof micro speaker, IP67, 8 ohm, 0.5 W, about 4 mm thick; 0.5 mm stainless perforated disc 20 mm bonded over it with neutral-cure silicone | Electronics distributor; stainless mesh from a hardware or craft supplier | 9.00 | buy | Speaker also works as the microphone through the push-to-talk amplifier (line 21)
5 Rod sections | 4 | 6061-T6 drawn aluminium tube 38.1 mm (1.5 in) outside x 1.47 mm (0.058 in) wall, cut to 1,050 mm; holes per VDS-DWG-101 (section 4 also has two 4 mm holes on top for the steering housings); depth marks every 100 mm under clear heat-shrink | Aluminium tube stockist (three 8 ft lengths or two 12 ft lengths) | 32.00 | make | Indicative price per section including offcut; 0.058 in wall chosen so the coupler tube telescopes inside
6 Couplers with snap buttons and pins | 4 | 6061-T6 tube 34.93 mm (1.375 in) outside x 2.11 mm (0.083 in) wall, cut to 120 mm; one stainless V-spring snap button for 1.25 to 1.5 in tube with an 8 mm button; two 4 mm aluminium pins 3.6 mm long; structural epoxy | Aluminium tube stockist; snap buttons from a tent-pole or tube-hardware supplier | 9.50 | make | Price per coupler set including button and pins; button pull strength to confirm when bought (VDS-DEC-001)
7 Tail cap with air barb and grommets | 1 | Turned from 50 mm 6061-T6 round bar, 65 mm long: 44 mm flange 25 mm long, 35.0 mm plug 40 mm long, 30 mm bore, 8 mm end wall with 10 and 12 mm grommet holes, 1/4 BSP tapped side hole; brass 1/4 BSP to 12 mm hose barb; two split rubber grommets; two 4 mm pins | Metal stockist; pneumatic fittings and grommets from a hardware store | 16.00 | make | Material and fittings; lathe work per VDS-DWG-105
8 Grip | 1 | Rubber or closed-cell foam handlebar grip tube, 38 mm bore, about 4.5 mm wall, 300 mm long | Bicycle or sporting goods store | 10.00 | buy | Slid onto section 4 with soapy water
9 Camera and speaker cable | 1 | Hybrid camera cable 7 m: one mini-coax for video plus four 0.25 mm2 cores (12 V, ground, speaker pair), about 6 mm outside, polyurethane jacket; 6-pin GX16 aviation plug at the surface end | Electronics distributor or CCTV cable supplier | 42.00 | buy | Indicative price including the plug; spliced to the camera pigtail inside the collar
10 Water guide tube | 1 | PTFE tube 8 mm outside x 6 mm bore, 6.5 m | Fluid fittings supplier | 32.00 | buy | Smooth bore so the water tube pushes through; never touches the water
11 Water set (single use) | 1 | Food-grade polyurethane tube 4 mm x 2.5 mm, 8 m; silicone bite valve about 11 mm outside; 0.5 mm bore food-grade PTFE capillary 600 mm with two barbed reducers; roller clamp; three-way stopcock; 100 micron inline strainer; 60 mL syringe for priming; resealable bag and label | Fluid fittings and hydration-pack spares suppliers | 26.00 | buy | One set per use; spares in line 27
12 Water reservoir bottle | 1 | 1 L food-grade polypropylene bottle with 25 mL graduations, carry bail and a bottom outlet spigot (laboratory aspirator-bottle class) | Laboratory or catering supplier | 18.00 | buy | Hangs from the stand hook by its bail
13 Reservoir stand | 1 | Photographic light stand, 0.8 to 2.0 m, three legs, with a hook arm and a strap of height marks every 0.1 m | Photo equipment retailer | 28.00 | buy | Sets the water height above the tip; at most 1 m above the tip by procedure
14 Surface unit case | 1 | Hard case, IP67, about 410 x 330 x 175 mm outside (base 125 mm, lid 50 mm), polypropylene, with pressure valve; base drilled for four plate screws, three wall fittings and the intake filter; lid drilled for the monitor bracket | Case retailer | 110.00 | buy | Indicative price for a generic IP67 case of this size; drilled per VDS-DWG-108
15 Equipment plate with spacers | 1 | 5052 aluminium sheet 3 mm, 330 x 300 mm, drilled per VDS-DWG-106; four 6 mm nylon spacers, four M5 stainless screws with bonded sealing washers and nyloc nuts | Metal stockist; fasteners from a hardware store | 22.00 | make | Material and fixings
16 Monitor with recorder and lid bracket | 1 | 7 in AHD monitor with built-in recorder (microSD), 1000 nit or brighter, 12 V, audio in, rear M4 mounting holes; bracket from 2 mm 5052 aluminium sheet folded per VDS-DWG-107 with four M5 screws and bonded sealing washers | CCTV or drain-camera spares supplier; metal stockist | 175.00 | buy | Indicative price for the monitor plus about USD 8 of sheet and fixings
17 Battery pack | 2 | 12.8 V 6 Ah LiFePO4 pack with built-in battery management, about 151 x 65 x 94 mm, XT60 lead, discharge to -20 C; one fitted, one spare | Battery retailer | 55.00 | buy | Two packs: fitted plus spare for a full shift
18 Blower | 1 | 12 V DC centrifugal blower about 97 x 94 x 33 mm with a maximum static pressure (shut-off) of 1.0 kPa or less, PWM speed input; four 10 mm standoffs | Electronics distributor | 24.00 | buy | Shut-off pressure caps the air pressure at the tip; to confirm on the datasheet when bought (VDS-DEC-001)
19 Intake filter | 1 | Inline air intake filter with a pleated fine-dust (F7 class or better) cartridge, about 60 mm diameter, 1/2 in bulkhead thread and nut | Pneumatics or air-quality supplier | 22.00 | buy | Faces away from the void; cartridge replaceable
20 Air flow meter | 1 | Panel variable-area flow meter for air, 5 to 50 L/min, about 32 x 30 x 100 mm, pressure drop 0.2 kPa or less at 20 L/min; bracket from 40 x 40 x 3 mm aluminium angle | Pneumatics supplier; metal stockist | 34.00 | buy | Must stand upright; pressure drop to confirm when bought
21 Control modules | 1 | Printed tray holding: 12 V 3 A buck-boost converter, 10 A blade fuse holder with 7.5 A fuse, illuminated main switch, PWM blower speed controller with knob, push-to-talk intercom amplifier (2 W, microphone preamplifier, relay switching the tip speaker between speaker and microphone), XT60 battery socket, terminal strip, 0.5 and 1.0 mm2 wire | Electronics distributor | 62.00 | buy | All extra-low voltage (12.8 V nominal)
22 Headset with push-to-talk | 1 | Closed-ear headset with boom microphone and a push-to-talk button, 3.5 mm plug to a waterproof panel socket | Electronics or radio accessory supplier | 32.00 | buy | Lets the operator hear a faint voice in a noisy site
23 Wall fittings | 1 | 6-pin GX16 panel socket; brass 1/2 in bulkhead to 12 mm hose barb with nut and seal; waterproof headset panel socket; sealing washers | Electronics distributor; pneumatics supplier | 18.00 | buy | Through the case wall facing the probe
24 Air hose and umbilical sleeve | 1 | Silicone hose 12 mm bore, 2.5 m; two hose clips; 30 mm braided cable sleeve 2.5 m with hook-and-loop ties | Hardware or pneumatics supplier | 24.00 | buy | Carries air from the case outlet to the tail cap barb; the sleeve bundles hose and lines
25 Battery charger | 1 | 14.6 V 2 A LiFePO4 charger with a certified mains adapter and XT60 lead | Battery retailer | 30.00 | buy | Bought certified; mains only at the charging point
26 Rod carry case | 1 | Hard long case about 1,150 x 350 x 150 mm with foam, holding the four sections side by side, the head in a foam cut-out and the lines in loops | Case retailer | 115.00 | buy | The sections stay threaded on the lines in storage
27 Cleaning kit and spare water sets | 1 | Four spare water sets (line 11), food-safe sanitising tablets, 1 L wash bottle, long bottle brush, lint-free cloths, nitrile gloves, labelled bags | Catering and hydration-pack suppliers | 118.00 | buy | One clean water set per use
28 Fixings and consumables | 1 | Structural two-part epoxy, threadlocker, neutral-cure silicone, clear heat-shrink 50 mm, paint marker, M4 countersunk screws, M5 screws, cable ties, solder and heat-shrink sleeves | Hardware store | 38.00 | buy | Indicative allowance
29 Lathe time for nose collar tail cap and tip parts | 1 | Outside turning and drilling of lines 2, 3, 7, 31, 32 and the drum of line 34 where no lathe is at hand (about 4 h shop time) | Local machine shop | 240.00 | buy | Allowance at about USD 60 an hour; was 3 h (USD 180) before the steerable tip added the base link, tip housing and drum (VDS-DDR-003); zero if the builder has a lathe
30 Bending section links pins and sheath | 1 | Four hinged links printed in PA12 nylon by selective laser sintering per VDS-DWG-110 (33 mm outside, 23 mm bore, 10 mm body, hinge lugs top and bottom, two 1.2 mm wire holes); ten 2 x 5 mm stainless dowel pins; two silicone sheaths 33 mm bore x 0.6 mm wall x 80 mm (one fitted, one spare); waxed thread and neutral-cure silicone for the sheath ends | Online SLS printing service; pins from a hardware or model-engineering supplier; silicone tube from a fluid fittings supplier | 42.00 | make | Price basis: about USD 6 per printed link (USD 24), pins USD 4, sheaths about USD 7 each (USD 14); indicative
31 Base link | 1 | Turned from 35 mm 6061-T6 round bar, 25 mm long: 29.25 mm spigot 14 mm long, 33 mm flange 8 mm long, 12 mm bore, milled hinge lugs, two 1.2 mm wire holes drilled on a slant, two grub screw dimples; two M3 x 10 nylon-tipped stainless grub screws | Metal stockist (bar offcut); screws from a hardware store | 6.00 | make | Price basis: bar offcut about USD 3, screws about USD 3; lathe and mill work per VDS-DWG-111 (lathe time in line 29)
32 Tip housing | 1 | Turned from 35 mm 6061-T6 round bar, 75 mm long: 33 mm outside x 66 mm, 29.3 mm camera bore 58 mm deep, 23 mm back bore, milled hinge lugs, two wire anchor holes; two M3 x 4 nylon-tipped stainless grub screws; two 2.5 mm copper crimp ferrules | Metal stockist (bar cut to length); screws and ferrules from a hardware store | 8.00 | make | Price basis: bar about USD 5, screws and ferrules about USD 3; per VDS-DWG-112 (lathe time in line 29)
33 Steering wires and housings | 1 | Two 0.6 mm 7x7 stainless wire ropes, 6 m each; two PTFE-lined steel-coil push-pull cable housings 3 mm outside, 4.4 m each (model aircraft control cable class); silicone sealant where they pass section 4 | Model-engineering or control-cable supplier | 38.00 | buy | Price basis: housing about USD 3 per metre (USD 26), wire rope about USD 1 per metre (USD 12); indicative; breaking load of the wire to confirm when bought (VDS-DEC-001)
34 Steering control | 1 | Clamp body with pad and cheeks printed in PA12 nylon by selective laser sintering per VDS-DWG-113; drum 36 mm across turned from 40 mm 6061-T6 bar with two wire clamp screws per VDS-DWG-114; 6 mm stainless shaft 50 mm; lever cut from 3 mm 5052 sheet with a thumb peg; friction lock knob with a spring washer; M4 clamp screw and nyloc nut | Online SLS printing service; metal stockist; hardware store | 48.00 | make | Price basis: printed body about USD 30, bar, shaft, sheet, knob and fixings about USD 18; indicative

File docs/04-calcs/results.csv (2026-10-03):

tag | quantity | value | unit
A1 | Largest diameter anywhere on the probe with the tip straight (head 48, grip 47, buttons) | 48.0 | mm
A2 | Radial clearance in a 51 mm core hole at the head | 1.50 | mm
A3 | Assembled probe length, tail cap to tip | 4538 | mm
A4 | Working length, tip to the front of the steering control (as far as the probe can go in) | 4131 | mm
A4g | Tip to the front of the grip | 4203 | mm
A5 | Head length, collar back face to tip | 313 | mm
A6 | Steerable tip length ahead of the nose | 140 | mm
B1 | Rod tube second moment of area | 28418 | mm4
B2 | Rod tube section modulus | 1492 | mm3
B3 | Rod line mass (tube, couplers, lines, steering housings, water) | 0.65 | kg/m
B4 | Head mass (collar, nose, steerable tip with camera, speaker, bite valve) | 0.77 | kg
B4t | Steerable tip mass ahead of the nose (base link, links, pins, sheath, tip housing, camera) | 0.28 | kg
B4s | Steering housings and wires, and the steering control | 0.41 | kg
B5 | Probe mass, assembled, lines filled | 4.18 | kg
B6a | Tip droop with 1 m unsupported beyond the hole | 1.69 | mm
B6b | Tip droop with 2 m unsupported beyond the hole | 16.7 | mm
B71 | Hand force at the grip with 1 m in the void and the tip unsupported (+ pushes down) | -8.62 | N
B72 | Hand force at the grip with 2 m in the void and the tip unsupported (+ pushes down) | 3.14 | N
B73 | Hand force at the grip with 3 m in the void and the tip unsupported (+ pushes down) | 32.3 | N
B8 | Bending moment at the hole lip, 3 m in the void, tip unsupported | 51.2 | N m
B9 | Bending stress in the plain tube at that moment | 34.3 | MPa
B10 | Stress at a button hole (stress concentration 3) | 103 | MPa
B11 | Safety factor on yield at a button hole | 2.33
B12 | Euler buckling load of the whole rod, pinned at both ends | 940 | N
B13 | Buckling factor at a 200 N two-handed push | 4.70
B14 | Bearing stress at a button hole at a 300 N pull to free a stuck probe | 25.5 | MPa
B15 | Shear-out stress behind the button hole at 300 N | 3.40 | MPa
B16 | Shear stress in the two coupler pins at 300 N (epoxy ignored) | 11.9 | MPa
C1 | Width seen at 1 m with a 90 degree horizontal view | 2000 | mm
C2 | Pixels across the height of a 20 mm letter at 1 m (1080p) | 19.2 | px
C3 | Pixels needed to read a letter (assumed) | 10
C4 | Illuminance on axis at 1 m from the camera LEDs (60 lm in a 120 degree beam) | 19.1 | lx
C5 | Ratio to the camera's 0.01 lx minimum illumination | 1910
C6 | Light left after 2 m of dusty air at an assumed extinction of 0.5 per m | 7.03 | lx
D1-0.5-5 | Drip ceiling at 0.5 m water height above the tip, 5 C, clamp fully open | 0.48 | mL/min
D1-0.5-20 | Drip ceiling at 0.5 m water height above the tip, 20 C, clamp fully open | 0.74 | mL/min
D1-0.5-40 | Drip ceiling at 0.5 m water height above the tip, 40 C, clamp fully open | 1.13 | mL/min
D1-1-5 | Drip ceiling at 1 m water height above the tip, 5 C, clamp fully open | 0.97 | mL/min
D1-1-20 | Drip ceiling at 1 m water height above the tip, 20 C, clamp fully open | 1.47 | mL/min
D1-1-40 | Drip ceiling at 1 m water height above the tip, 40 C, clamp fully open | 2.26 | mL/min
D1-2-5 | Drip ceiling at 2 m water height above the tip, 5 C, clamp fully open | 1.94 | mL/min
D1-2-20 | Drip ceiling at 2 m water height above the tip, 20 C, clamp fully open | 2.94 | mL/min
D1-2-40 | Drip ceiling at 2 m water height above the tip, 40 C, clamp fully open | 4.51 | mL/min
D2 | Highest possible flow: 2 m height (1 m allowed plus 1 m error) at 40 C | 4.51 | mL/min
D3 | Same, at the 1 m height the procedure allows, 20 C | 1.47 | mL/min
D4 | Water per hour at 1 m, 20 C, clamp fully open | 88.2 | mL/h
D5 | Water in the line when primed (4 x 2.5 mm tube, 8 m) | 39.3 | mL
D6 | Flow at 1 m without the capillary (why it is fitted) | 70.4 | mL/min
D7 | Water pressure at the bite valve at 2 m height (no flow) | 19.6 | kPa
D8 | Water set change: pull old tube 1 min, push new tube 2 min, prime 1 min | 4.00 | min
E1-filter | Pressure drop at 20 L/min: filter | 50.0 | Pa
E1-meter | Pressure drop at 20 L/min: meter | 200 | Pa
E1-hose | Pressure drop at 20 L/min: hose | 54.5 | Pa
E1-barbs | Pressure drop at 20 L/min: barbs | 54.1 | Pa
E1-rod | Pressure drop at 20 L/min: rod | 10.5 | Pa
E1-outlets | Pressure drop at 20 L/min: outlets | 7.21 | Pa
E1-total | Pressure drop at 20 L/min: total | 376 | Pa
E2 | Air speed leaving the six 5 mm outlets at 20 L/min | 2.83 | m/s
E3 | Air flow at full blower speed into an open void | 44.3 | L/min
E4 | Blower speed setting for 20 L/min | 65.0 | %
E5 | Highest pressure at the tip with every outlet blocked (blower shut-off) | 0.90 | kPa
E6 | Leak past one coupler at 50 Pa in the rod (0.11 mm gap, 30 mm long) | 0.0772 | L/min
E7 | Blower electrical power at the 20 L/min setting | 1.40 | W
F1 | Video and light load at the battery (camera 3 W, monitor 7 W, converter 90 %) | 11.1 | W
F2 | With air at 20 L/min and push-to-talk on standby | 12.9 | W
F3 | Pack energy, 12.8 V 6 Ah LiFePO4 | 76.8 | Wh
F4-20 | Video and light run time on one pack at 20 C | 6.22 | h
F5-20 | Run time with air and audio on one pack at 20 C | 5.35 | h
F4--10 | Video and light run time on one pack at -10 C | 4.35 | h
F5--10 | Run time with air and audio on one pack at -10 C | 3.75 | h
F6 | Run time with air and audio on both packs at -10 C (one swap) | 7.50 | h
F7 | Peak current at full blower and full LEDs | 1.43 | A
G1 | Energy of a 1 m drop of the head and section 1 together | 14.2 | J
G2 | Minimum wall in the nose (camera bore to outside, and to the pocket) | 2.85 | mm
H1 | open both cases, lift out the rod bundle and head | 0.40 | min
H2 | join the head and four sections (snap buttons) | 0.70 | min
H3 | plug the camera cable, fit the air hose, hang the water bottle | 0.60 | min
H4 | switch on, check the picture and voice | 0.40 | min
H5 | steer the tip both ways, lock it straight | 0.10 | min
H6 | Estimated time to start searching, two people | 2.20 | min
I1 | Surface unit mass with one pack fitted (case 2.6 kg, pack 0.85 kg, monitor 0.6 kg, others estimated) | 6.16 | kg
I2 | Estimated cost of the constructable design from bom/bom.csv | 1780 | USD
I3 | Value-engineering target (budget_usd) | 2000 | USD
I4 | Under (+) or over (-) the target | 220 | USD
I5 | Cost without outside lathe time (builder has a lathe) | 1540 | USD
J1 | Joints in the bending section | 5
J2 | Bend at which a joint's link faces close (its stop) | 18.1 | deg
J3 | Most the tip can bend each way, all joints closed | 90.4 | deg
J4 | Bending section length, base link flange to tip housing | 66.2 | mm
J5-45 | Camera face at 45 deg: ahead of the nose front, and to the side | 115 ahead, 72 to the side | mm
J5-90 | Camera face at 90 deg: ahead of the nose front, and to the side | 51 ahead, 109 to the side | mm
J6 | Sideways reach of the bent tip at 45 deg, from the probe centreline (half-width of passage it needs) | 83.2 | mm
J7 | Overlap between neighbouring links with the tip bent 90 deg (model check) | 0 | mm3
J8 | Sideways reach of the bent tip at 90 deg, from the probe centreline | 109 | mm
J9-45 | Wire pulled in on the inside of a 45 deg bend, paid out on the outside | 11.1 in, 10.9 out | mm
J9-90 | Wire pulled in on the inside of a 90 deg bend, paid out on the outside | 22.2 in, 21.6 out | mm
J10 | Drum (and lever) turn for 90 deg at the tip, 18 mm drum | 70.7 | deg
J11 | Drum turn for 45 deg at the tip | 35.2 | deg
J12 | Moment to bend the camera cable 90 deg in the bending section (EI 5,000 N mm2 assumed) | 119 | N mm
J13 | Wire tension at the tip, and at the drum with housing friction (mu 0.15, 180 deg of bends) | 8.5 and 13.6 | N
J14 | Thumb force on the 50 mm lever to hold 90 deg | 4.88 | N
J15 | Wire tension with a 30 N thumb push against the stop | 83.3 | N
J16 | Safety factor on a 0.6 mm 7x7 stainless wire rope (250 N breaking, assumed) | 3.00
J17 | Shear in the two 2 mm hinge pins of a joint at that tension | 13.3 | MPa
J18 | Bearing on the printed lugs at that tension (two pins, 2.4 mm lugs); PA12 yield about 45 MPa | 8.68 | MPa

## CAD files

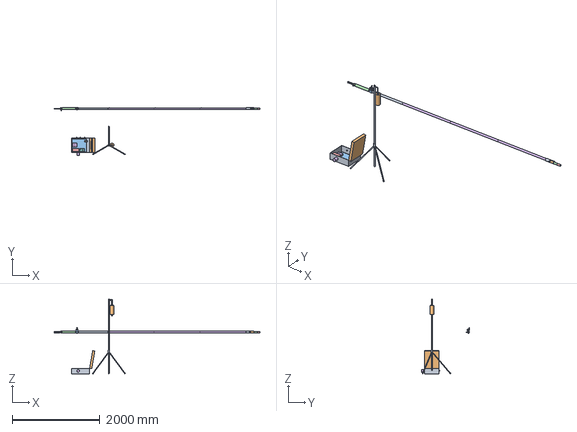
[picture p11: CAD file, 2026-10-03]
cad/step/voidscope-assembly.step
4688.2 x 1098.5 x 1702.0 mm

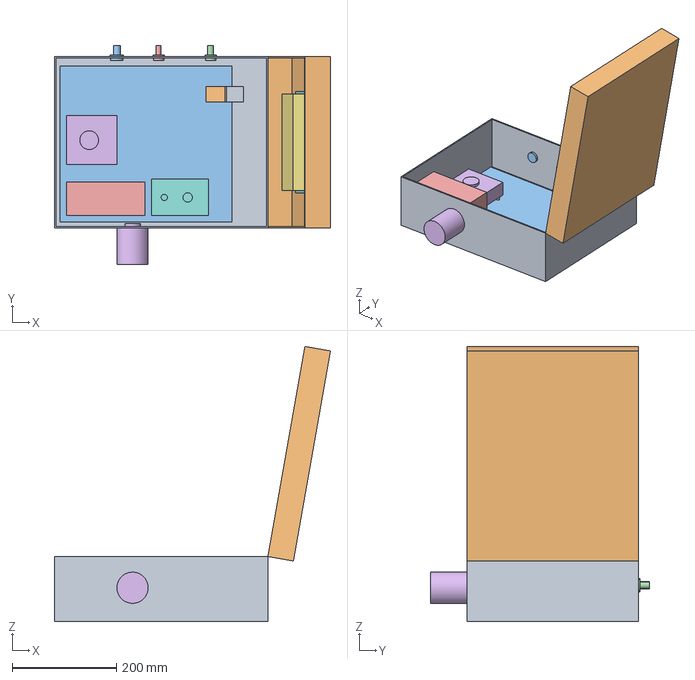
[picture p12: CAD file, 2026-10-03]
cad/step/voidscope-surface-unit.step
530.4 x 421.0 x 528.8 mm

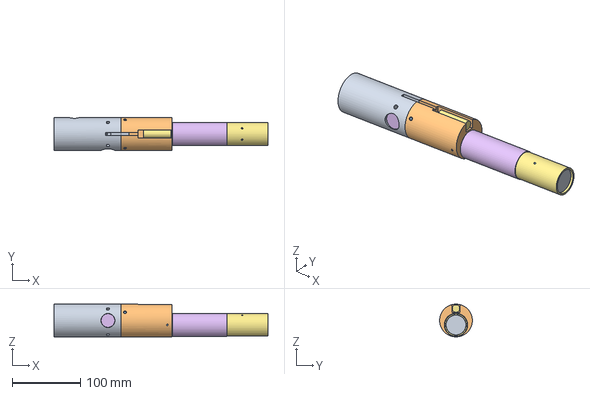
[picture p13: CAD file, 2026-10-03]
cad/step/voidscope-head.step
313.2 x 48.0 x 48.0 mm

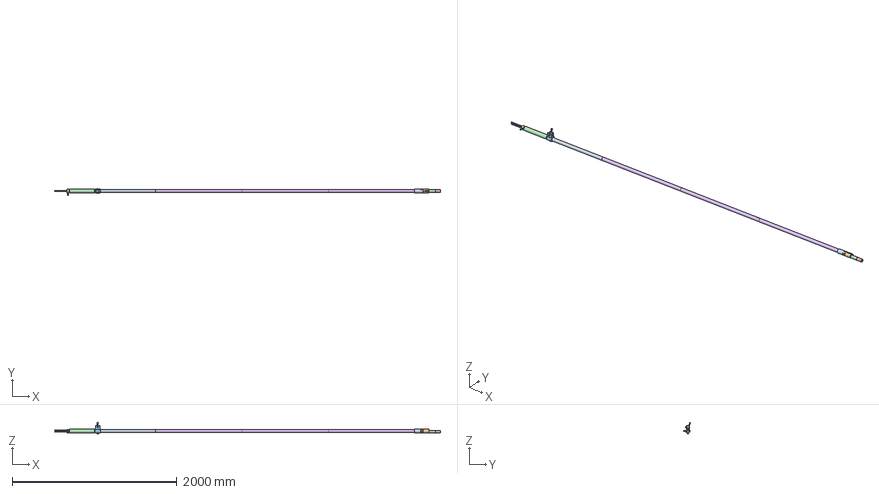
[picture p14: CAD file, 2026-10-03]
cad/step/voidscope-probe.step
4688.2 x 80.5 x 142.0 mm

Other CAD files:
cad/stl/voidscope-assembly.stl
cad/stl/voidscope-head.stl
cad/stl/voidscope-probe.stl
cad/stl/voidscope-surface-unit.stl

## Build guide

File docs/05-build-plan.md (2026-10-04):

---
doc_id: VDS-BLD-001
title: VoidScope prototype build plan
project: VoidScope
doc_type: Build plan
version: "0.3"
status: Draft
date: '2026-10-03'
author: Amish Chadha
license: CERN-OHL-S-2.0
revisions:
  - version: "0.1"
    date: '2026-10-03'
    author: Amish Chadha
    change: First build plan; design made constructable (VDS-DDR-002)
  - version: "0.2"
    date: '2026-10-03'
    author: Amish Chadha
    change: Steerable camera tip and steering control added (VDS-DDR-003, Amish's decision 3A); new sketches, joints and steps
  - version: "0.3"
    date: '2026-10-03'
    author: Amish Chadha
    change: "Drill card added with the rule to steer the tip aside to give water (Amish's round-2 decision 3A, VDS-DDR-004)"
---

# VoidScope prototype build plan

**Plan, not yet built.** How to build the first proof-of-concept prototype, component by component. Building and testing to it is TRL 4 work. Decisions are kept in the design decisions register ([docs/06-design-decisions.md](06-design-decisions.md)), not here.

## 1. What you are building

Figure 1. Every component, pulled apart and numbered in build order

*Figure 1. Every component pulled apart and numbered in build order. The rod sections lie side by side as they are stored; the cable, tubes, steering housings and wires are drawn cut short.*

The prototype is a 4.5 m camera probe and its surface unit. The probe is four aluminium tube sections that click together with snap buttons, a turned aluminium head holding a small speaker and a bite valve, a camera tip ahead of the head that bends up to 90° to either side, a steering lever on the rod just ahead of the grip, and a turned tail cap where the air goes in. The camera cable, a guide tube for the water and two steering wires in their housings stay threaded through the sections. The surface unit is a bought hard case holding a battery, a blower, a flow meter and small control modules, with a monitor in its lid; a water bottle hangs on a light stand beside it. Figure 1 shows the 24 components in the order you make or fit them. Fourteen are made: the rod sections, couplers, collar, nose, base link, tip housing, steering drum and tail cap (tube cutting, drilling and lathe work), the bending links and the steering control body (printed in nylon by a print service), the equipment plate and two small brackets (sheet and angle), and the drilled case. The rest are bought and fitted. The parts cost about USD 1,780 from the bill of materials.

> **Safety:** VoidScope is rescue equipment for trained teams; this prototype is not certified and it is not a medical device. The battery packs are 12.8 V lithium iron phosphate: keep the battery lead unplugged and the fuse out until section 6 says otherwise, and charge packs only on their own charger, on a non-combustible surface. Turning, drilling and cutting tube throw chips and leave sharp edges: wear safety glasses, keep hair and sleeves clear of the lathe chuck, and deburr everything. Cut steering wire ends are sharp; crimp or tape them at once. The water line must never be connected to a pump or a pressurised container, and the capillary is never removed. Two-part epoxy and threadlocker need gloves and ventilation.

## 2. What changed to make it buildable

The concept showed what the probe does; it did not say how the sections join, how the lines cross the joints or how the head fits everything inside 48 mm. Each change keeps what VoidScope does, and all of them are recorded in decision record VDS-DDR-002.

*Table 1. Changes from the concept.*

| Component | The concept had | The buildable design has | Why |
| --- | --- | --- | --- |
| Rod and joints | A rod about 50 mm across in about 1 m sections; joints not defined | 38.1 mm tube in four 1,050 mm sections, a 34.93 mm coupler bonded and pinned in each, locked by a snap button (Figure 3) | The two stock tube sizes slide together by hand, and the thinner rod leaves room for the head |
| Lines | Connectors at each joint | Cable and guide tube stay threaded through every section, like the cord in a tent pole | No connectors inside the rod; setup is four clicks |
| Air | A separate air line | The rod's own bore carries the air | Far less pressure loss; the joints need no seals |
| Water | A line inside the rod | A guide tube the single-use water tube pushes through (Figure 9) | The water set changes in about 4 minutes, no tools |
| Head | One sealed piece | A turned collar and nose joined by three screws; camera set 6.5 mm below the centre; a 20 mm speaker (Figures 5 to 8) | Each part turns on a small lathe; the bite valve and speaker fit inside 48 mm |
| Display | A handheld screen | A monitor in the lid of the surface unit (Figure 16) | One battery and one cable; the crew's hands stay on the rod |
| Surface unit | Not laid out | An equipment plate on spacers, an upright flow meter, sealed wall fittings (Figure 13) | The case stays sealed and the lid still closes |
| Details found by checking the model | A 25 mm tail cap bore, a water groove 0.5 mm too deep, a short valve pocket | A 30 mm bore with a 44 mm flange, the groove floor 20 mm from the centre, a 50 mm pocket | Each part now clears its neighbours |
| Camera tip | A rigid head; the camera behind a lip in the nose | A camera tip on five pinned joints that bends up to 90° to either side, steered by two wires from a thumb lever on the rod (Figures 18 to 24) | Amish's decision 3A: the camera must see around a 45° bend from a straight hole |
| Collar outlets | Lower outlets at 225° and 315° | Lower outlets at 240° and 300°; two stops for the steering housings in the front wall (Figure 4) | The steering housings pass where the old outlets were |
| Hinge lugs | Square lug ends | Lug ends rounded about their pins | With square ends the neighbouring link hit the lug before the full 90° bend |

## 3. Making the components

Make and check each component before the assembly step that needs it. Sizes are in millimetres. "Top" is the side the bite valve pocket is on; the tip bends to the left and right of it; the "button line" is a straight line scribed along every section and coupler, on the right side as seen from behind the tail cap, so all the buttons line up. Workshop tolerance is 0.2 mm on turned diameters and 0.5 mm elsewhere unless a step says otherwise; drawings do not carry tolerances before TRL 4.

### 3.1 Rod sections (make 4)

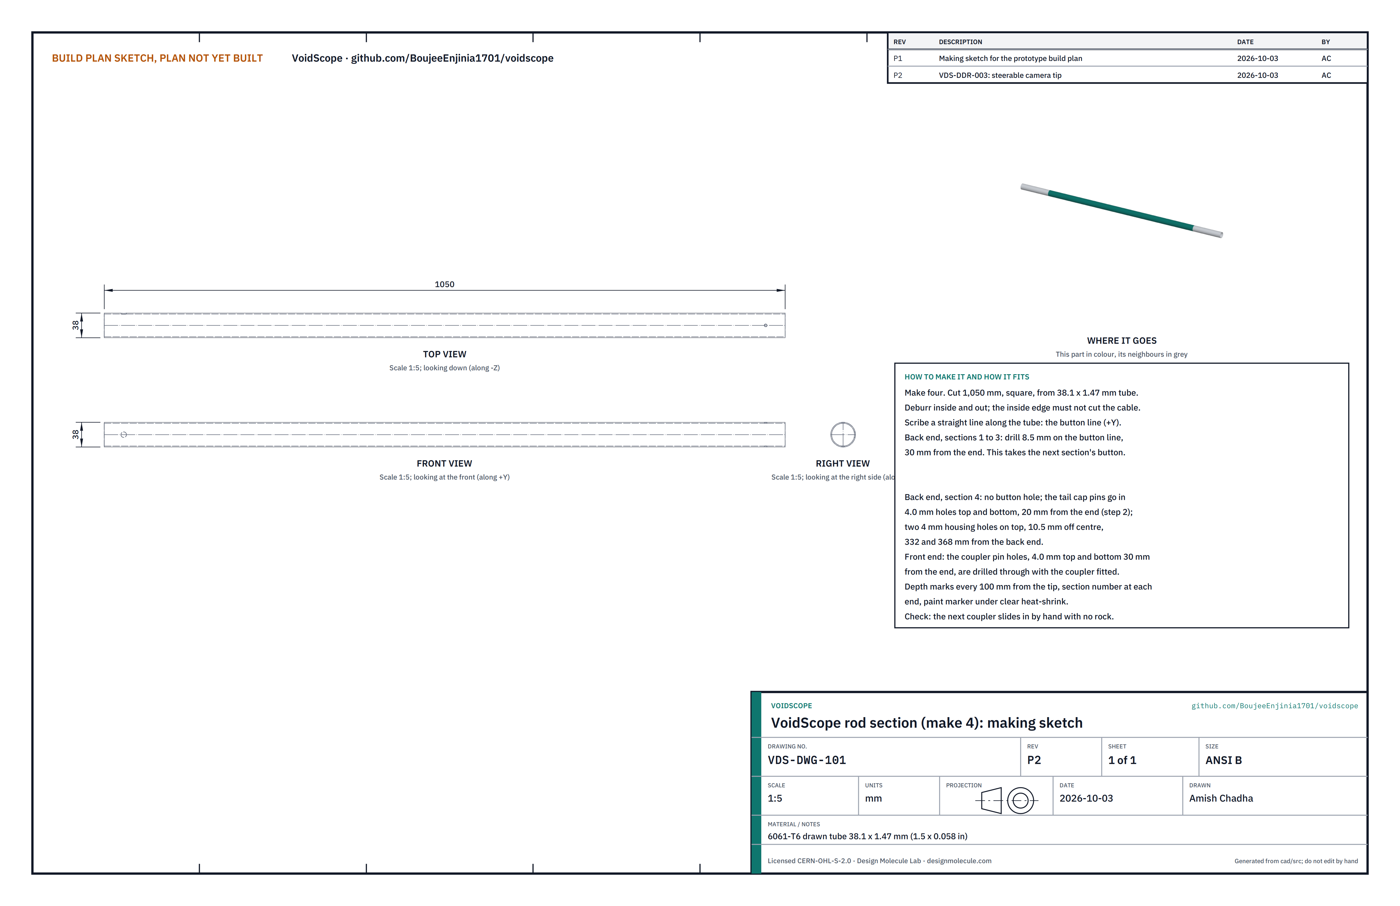
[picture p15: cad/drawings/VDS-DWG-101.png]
Figure 2. Making sketch of a rod section


*Figure 2. Rod section making sketch (VDS-DWG-101).*

**What it is and what it is made from.** The four straight lengths of the probe. Each is 6061-T6 drawn aluminium tube, 38.1 mm (1.5 in) outside with a 1.47 mm (0.058 in) wall, 1,050 mm long.

**How to make it.**

1. Cut four lengths of 1,050 mm, square, with a fine-tooth saw or a tube cutter. Number them 1 to 4; section 1 goes next to the head.
2. Deburr both ends inside and out. The inside edge must be smooth, because the cable slides past it.
3. Scribe the button line along each tube with a straight edge.
4. Sections 1, 2 and 3: on the button line, 30 mm from the back end, drill an 8.5 mm hole (start with 3 mm, then step up). The next section's snap button comes through this hole.
5. Section 4: no button hole at the back. The tail cap pins go through it in step 2. On top of section 4, drill two 4 mm holes for the steering housings: one 332 mm from the back end and 10.5 mm to the button-line side of the top line, the other 368 mm from the back end and 10.5 mm to the other side.
6. Mark depth bands every 100 mm, counting from the tip of the assembled probe, and the section number at each end, with a paint marker. Cover each section with clear heat-shrink.

**How it fits the parts next to it.** The front end of each section takes a coupler, bonded in for 60 mm (Figure 3). The back end slides over the coupler of the section behind it until the two tube ends butt; the snap button pops through the 8.5 mm hole. Section 1's front coupler goes into the collar instead.

**Check before moving on.** A coupler slides into each back end by hand without rocking, and all four sections are 1,050 mm within 0.5 mm. On section 4 the two housing holes are deburred inside, so the housings are not cut.

### 3.2 Couplers with snap buttons (make 4)

Figure 3a. Making sketch of the coupler

*Figure 3a. Coupler making sketch (VDS-DWG-102).*

**What it is and what it is made from.** The short inner tube that joins two sections. 6061-T6 tube, 34.93 mm (1.375 in) outside with a 2.11 mm (0.083 in) wall, 120 mm long; a stainless V-spring snap button with an 8 mm button; two 4 mm aluminium pins.

**How to make it.**

1. Cut four 120 mm lengths; deburr. Chamfer the outside of one end 1 mm at 45°: this is the free end.
2. Scribe a button line along each. On it, 30 mm from the free end, drill an 8.5 mm hole.
3. Squeeze the V-spring and slide it in from the plain end, button first, until the button snaps out through the hole. The spring strip lies across the bore from the button side to the opposite side; the spaces above and below it are where the cable and guide tube pass.
4. Bond: clean the plain end and the inside of the section's front end with solvent, coat both with structural epoxy, and push the coupler 60 mm into the section with the two button lines in line. Wipe off the squeeze-out inside.
5. Before the epoxy sets, drill 4.0 mm through tube and coupler at the top and the bottom, 30 mm from the section's front end, and press in the two pins flush both sides. Leave to cure for 24 hours.

**How it fits the parts next to it.**

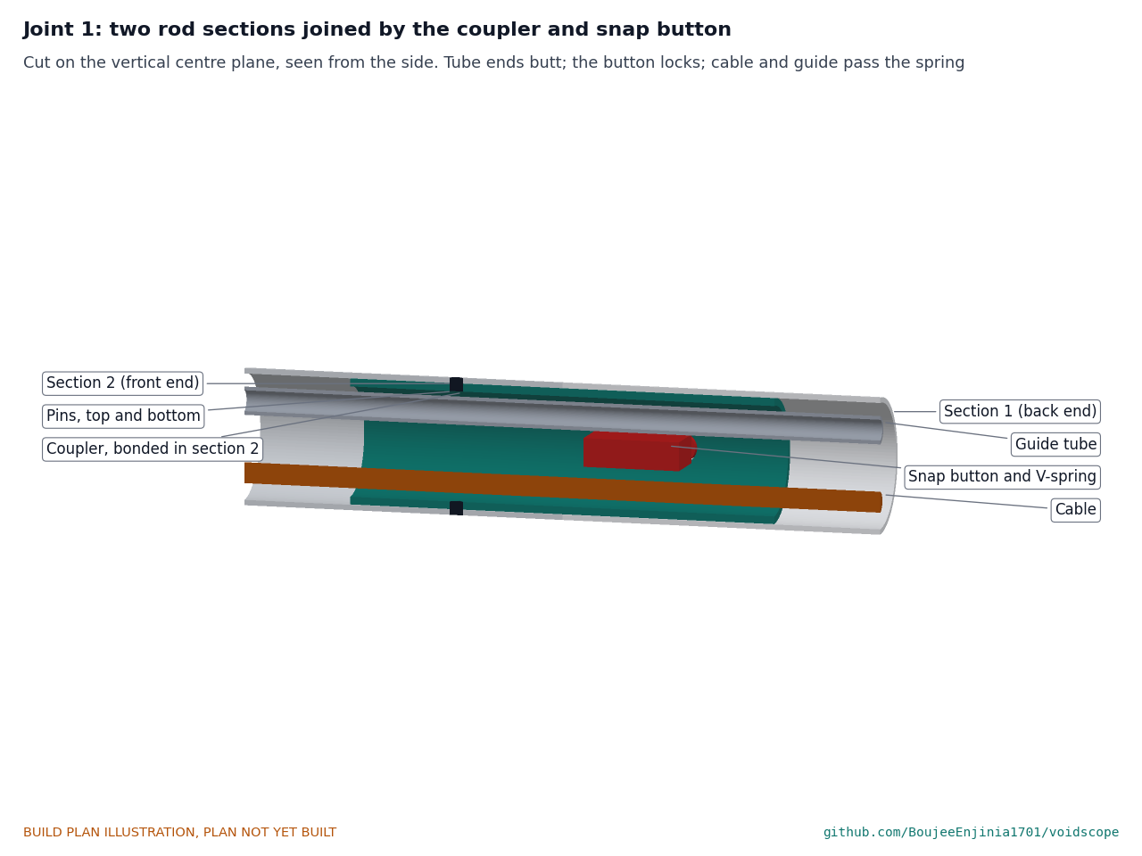
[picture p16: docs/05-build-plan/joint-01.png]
Figure 3. Joint 1: two rod sections joined


*Figure 3. The coupler is bonded and pinned into one section and slides into the next; the tube ends butt and the button locks. The cable and guide tube pass above and below the spring.*

The coupler's outside slides inside the next tube with about 0.11 mm a side. Push loads go through the butted tube ends; pull and twist go through the button. The spring sits 3.0 mm from the cable and 2.0 mm from the guide tube.

**Check before moving on.** Each joint clicks together and comes apart with one press of the button; a hard pull by hand moves nothing.

### 3.3 Collar

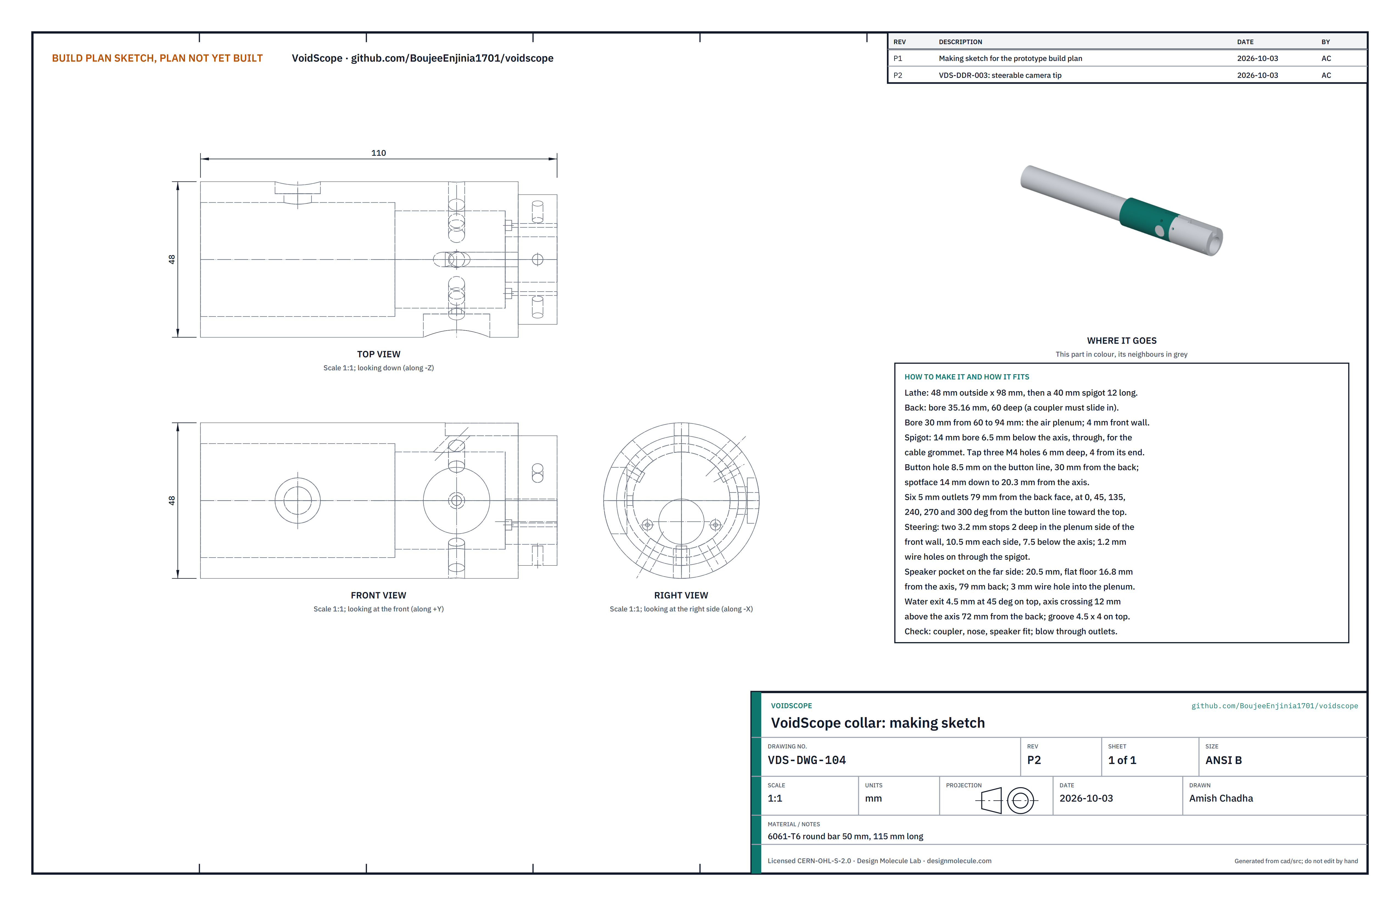
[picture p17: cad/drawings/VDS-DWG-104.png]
Figure 4. Making sketch of the collar


*Figure 4. Collar making sketch (VDS-DWG-104).*

**What it is and what it is made from.** The back half of the head: it takes the first rod section, turns the air out through six holes, holds the speaker, lets the water tube out and carries the nose. 6061-T6 round bar, 50 mm, 115 mm long.

**How to make it.**

1. On the lathe, turn to 48 mm outside for 98 mm and a 40 mm spigot 12 mm long at the front; part off.
2. From the back face, bore 35.16 mm, 60 mm deep, so a coupler slides in. Then bore 30 mm on to 94 mm from the back face: the air chamber. Leave a 4 mm front wall.
3. Through the spigot, bore 14 mm on a centre 6.5 mm below the axis (offset in a four-jaw chuck, or drill and ream on a drill press with the collar in a vee block). This takes the cable grommet.
4. Tap three M4 holes 6 mm deep into the spigot, 4 mm from its front end, at the positions on the sketch.
5. On the button line, 30 mm from the back face, drill 8.5 mm, then spotface 14 mm across until the floor is 20.3 mm from the axis, so a fingertip reaches the button.
6. Drill six 5 mm air holes into the chamber, 79 mm from the back face: on the button line, at 45° and 135° above it, and at 240°, 270° and 300° (bottom and the lower side).
7. On the side opposite the button line, at 79 mm from the back face, mill a 20.5 mm flat-bottomed pocket down to 16.8 mm from the axis for the speaker; drill a 3 mm wire hole from its floor into the chamber.
8. On top, drill the 4.5 mm water exit at 45° through into the chamber, its axis crossing 12 mm above the axis at 72 mm from the back face (use a 45° vee block on the drill press). Mill a groove 4.5 mm wide on top from the exit to the front face, its floor 20 mm above the axis.
9. For the steering, from inside the chamber, counterbore two 3.2 mm holes 2 mm deep into the front wall, each 10.5 mm to one side of the centre and 7.5 mm below it; the housings end in these. Through the middle of each, drill 1.2 mm on through the wall and the spigot for the wire.
10. Deburr every hole inside and out; the water tube, the wires and the air must meet no sharp edge.

**How it fits the parts next to it.**

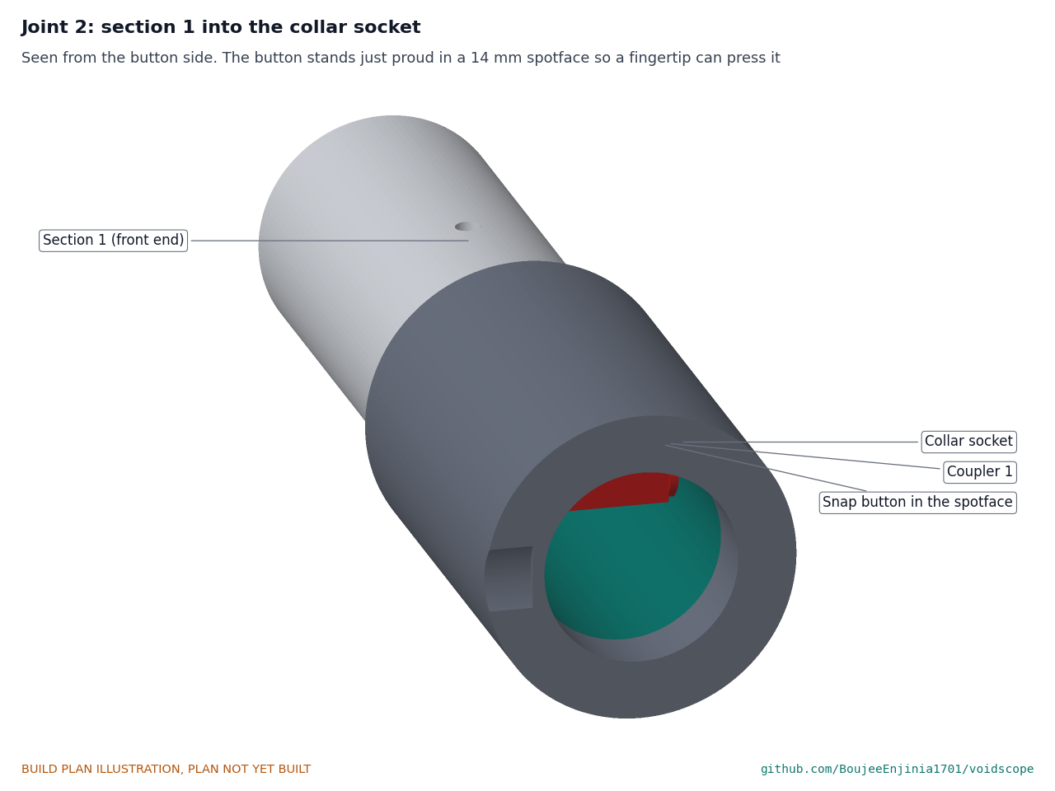
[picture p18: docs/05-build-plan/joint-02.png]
Figure 5. Joint 2: section 1 into the collar socket


*Figure 5. Section 1's coupler slides into the collar socket until the tube butts the collar; the button stands just proud in its spotface.*

Figure 6. Joint 5: the speaker in its pocket

*Figure 6. The 20 mm speaker sits on the flat floor of its pocket under a bonded perforated cover, flush inside the 48 mm outline; air holes lie 45° above it and 60° below it.*

The socket takes section 1 exactly like a rod joint. The 40 mm spigot fits the nose's 40.2 mm counterbore. The speaker is bedded in neutral-cure silicone and its cover bonded on top.

**Check before moving on.** A coupler slides into the socket and the button pops into the spotface. Air blown into the socket comes out of all six holes.

### 3.4 Nose

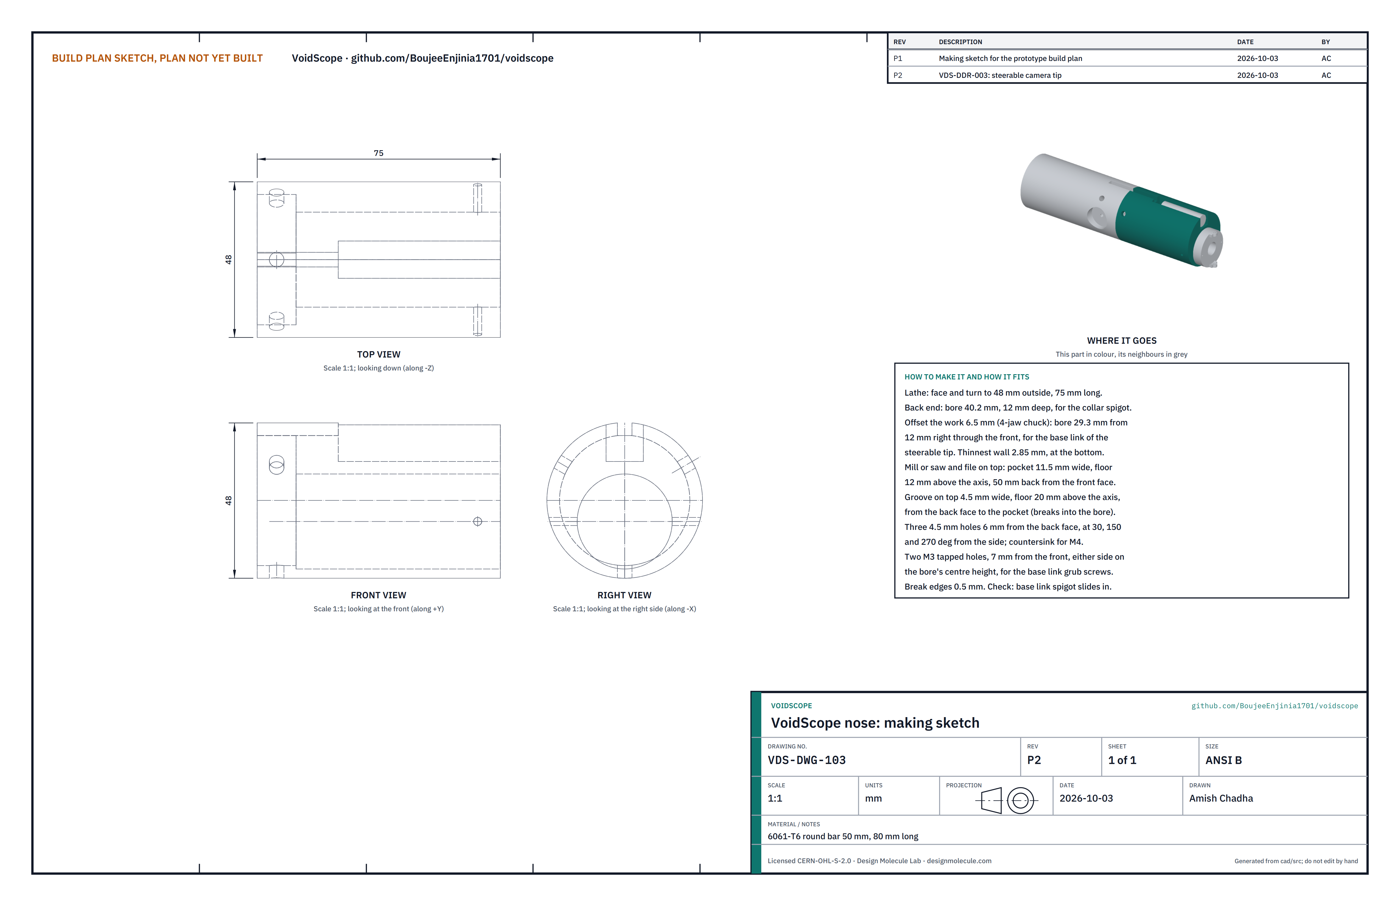
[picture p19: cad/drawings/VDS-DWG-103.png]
Figure 7. Making sketch of the nose


*Figure 7. Nose making sketch (VDS-DWG-103).*

**What it is and what it is made from.** The front of the head: it carries the steerable camera tip in its bore and parks the bite valve on top. 6061-T6 round bar, 50 mm, 80 mm long.

**How to make it.**

1. Turn to 48 mm outside and 75 mm long. From the back face, bore 40.2 mm, 12 mm deep, to fit the collar spigot.
2. Set the work 6.5 mm off centre in a four-jaw chuck, the offset away from the top. Bore 29.3 mm from 12 mm from the back face right through the front. The thinnest wall is 2.85 mm, at the bottom.
3. On top, cut the bite valve pocket: 11.5 mm wide, its floor 12 mm above the axis, 50 mm long, open at the front. A mill is best; a saw and file will do.
4. Continue a groove 4.5 mm wide on top, floor 20 mm above the axis, from the back face to the pocket. Over the counterbore it breaks through; that is intended.
5. Drill three 4.5 mm holes 6 mm from the back face at the same angles as the tapped holes in the spigot, and countersink them for M4 screws.
6. On the two sides, 7 mm back from the front face and level with the bore's centre, drill and tap M3 into the bore for the base link's grub screws.
7. Break every edge by 0.5 mm, especially at the front and the pocket.

**How it fits the parts next to it.**

Figure 8. Joint 3: nose on the collar, base link in the nose

*Figure 8. Three M4 screws hold the nose on the spigot. The base link of the camera tip slides into the front of the nose bore and two M3 grub screws hold it. A steering wire leaves its housing in the collar wall and runs along the nose bore into the base link.*

Figure 9. Joint 4: the water tube and the bite valve

*Figure 9. The water tube leaves the collar through the 45° exit, lies flush in the top groove and ends in the bite valve, pressed into its pocket on the nose.*

**Check before moving on.** The base link's spigot slides into the front of the bore by hand without rocking. The nose slides onto the spigot and the three screw holes line up. A bite valve presses into the pocket and stays there when the nose is shaken.

### 3.5 Tail cap

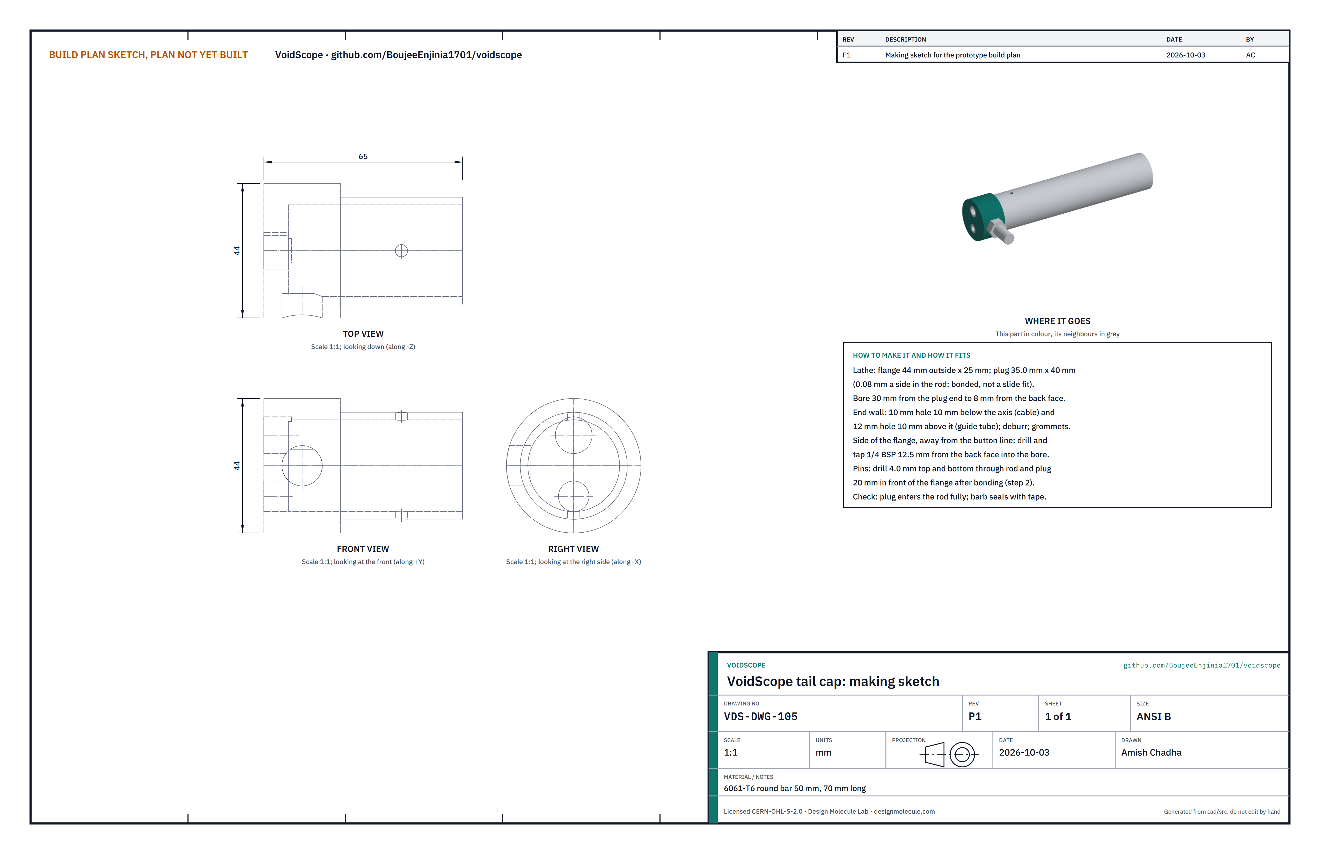
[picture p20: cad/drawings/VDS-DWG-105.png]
Figure 10. Making sketch of the tail cap


*Figure 10. Tail cap making sketch (VDS-DWG-105).*

**What it is and what it is made from.** The plug in the back end of section 4: the air goes in here, and the cable and guide tube come out through two grommets. 6061-T6 round bar, 50 mm, 70 mm long; a brass 1/4 BSP to 12 mm hose barb; two split rubber grommets; two 4 mm pins.

**How to make it.**

1. Turn a 44 mm flange 25 mm long and a 35.0 mm plug 40 mm long. The plug is 0.08 mm a side smaller than the tube's bore: a bonded fit, not a slide fit.
2. Bore 30 mm from the plug end to 8 mm from the back face, leaving an 8 mm end wall.
3. In the end wall, drill a 10 mm hole 10 mm below the axis for the cable grommet and a 12 mm hole 10 mm above it for the guide tube grommet. Deburr. Split each grommet on one side so the lines can be laid in.
4. In the side of the flange opposite the button line, 12.5 mm from the back face, drill and tap 1/4 BSP into the bore. Fit the barb with thread-seal tape.

**How it fits the parts next to it.**

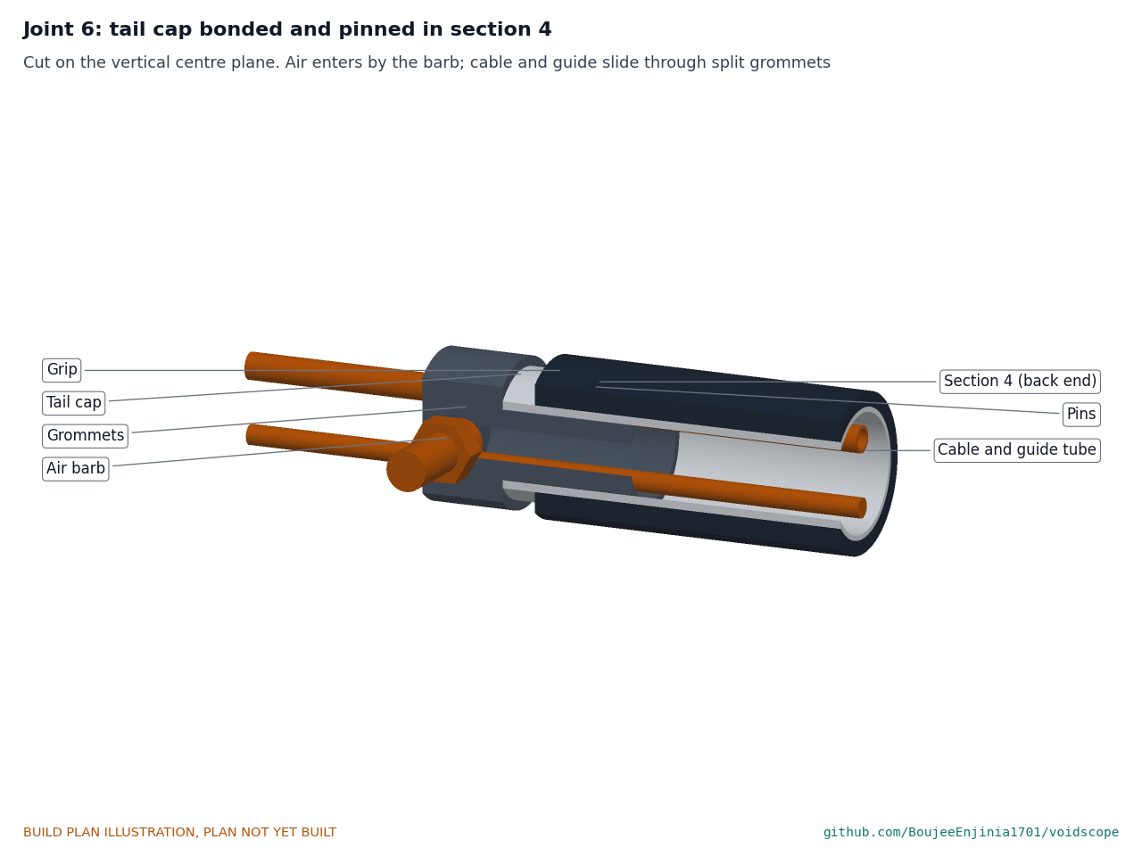
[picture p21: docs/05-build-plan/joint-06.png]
Figure 11. Joint 6: the tail cap in section 4


*Figure 11. The plug is bonded into section 4 against the flange and pinned top and bottom; air comes in by the barb; the cable and guide tube slide through the grommets.*

**Check before moving on.** The plug goes fully into section 4 dry. Blowing into the barb with a thumb over each grommet, air comes out of the plug end only.

### 3.6 Equipment plate

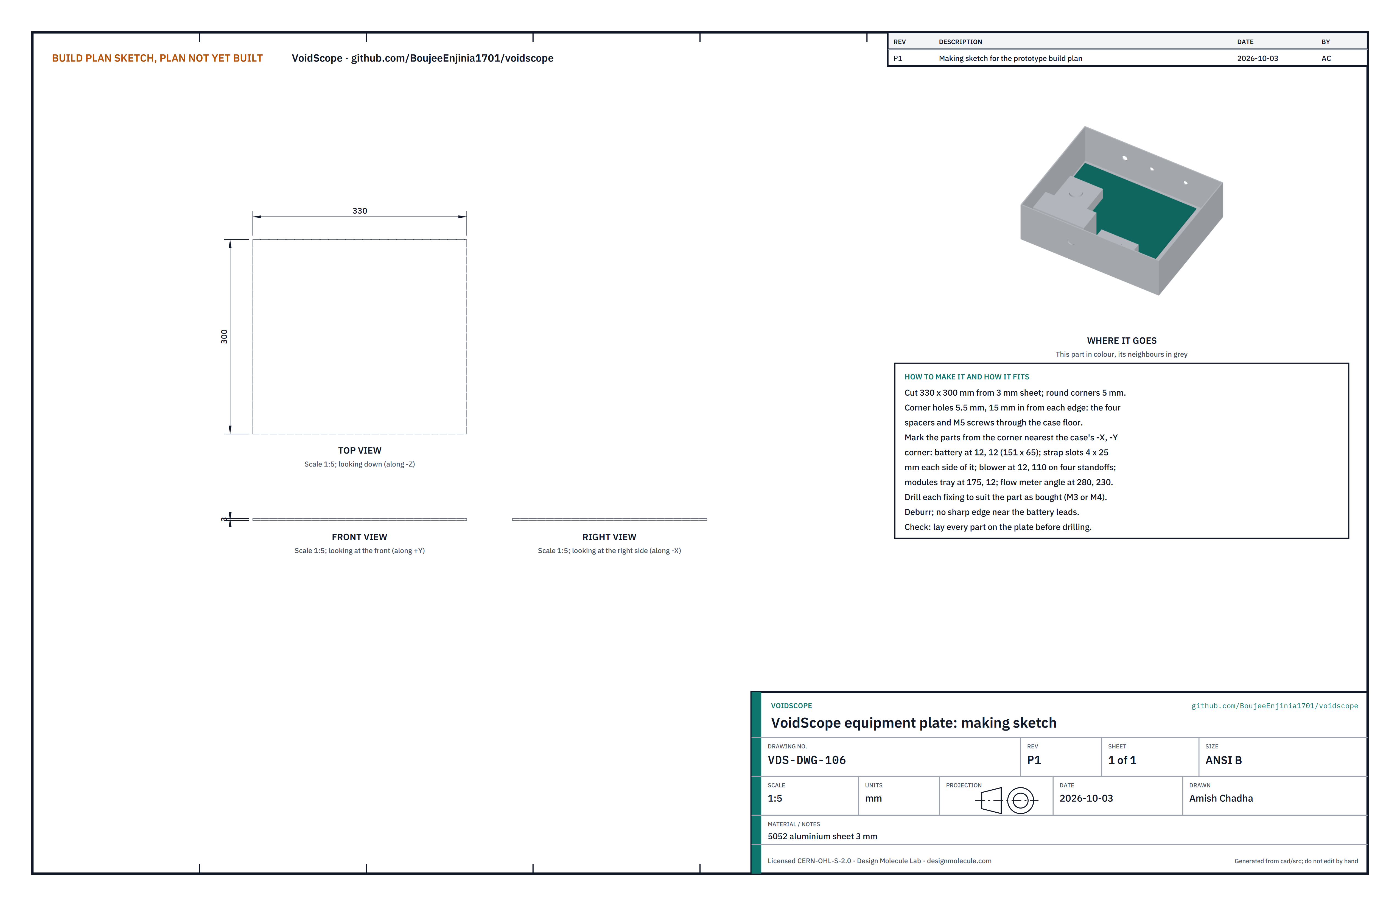
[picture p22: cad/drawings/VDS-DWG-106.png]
Figure 12. Making sketch of the equipment plate


*Figure 12. Equipment plate making sketch (VDS-DWG-106).*

**What it is and what it is made from.** The flat plate in the bottom of the case that every surface unit part is fixed to. 5052 aluminium sheet, 3 mm, 330 x 300 mm.

**How to make it.**

1. Cut the blank; round the corners to 5 mm; deburr.
2. Drill four 5.5 mm holes, 15 mm in from each edge at the corners.
3. Lay out the parts from the corner that will sit nearest the case's back left corner: the battery 12 mm in from both edges, with two pairs of 4 x 25 mm strap slots beside it; the blower 12 mm from the left edge and 110 mm from the front, on four standoffs; the control modules tray 175 mm from the left edge; the flow meter bracket 280 mm from the left edge and 230 mm from the front.
4. Drill each fixing hole to suit the part as bought (M3 or M4).

**How it fits the parts next to it.**

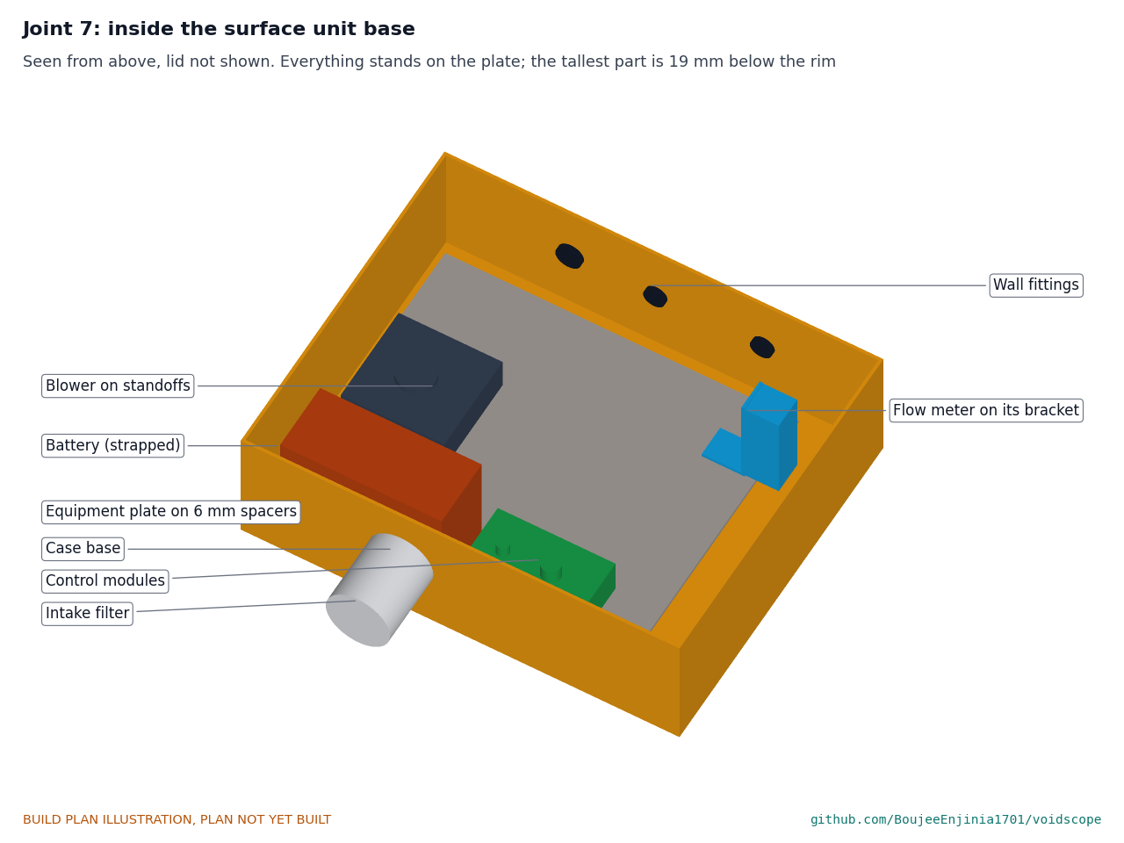
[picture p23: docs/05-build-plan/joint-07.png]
Figure 13. Joint 7: inside the surface unit


*Figure 13. The plate stands on four 6 mm spacers, screwed through the floor; everything else stands on the plate. The tallest part is 19 mm below the rim.*

**Check before moving on.** Every part sits on the plate without overlapping another, and the plate drops into the case with 6 mm clear of every wall.

### 3.7 Flow meter bracket

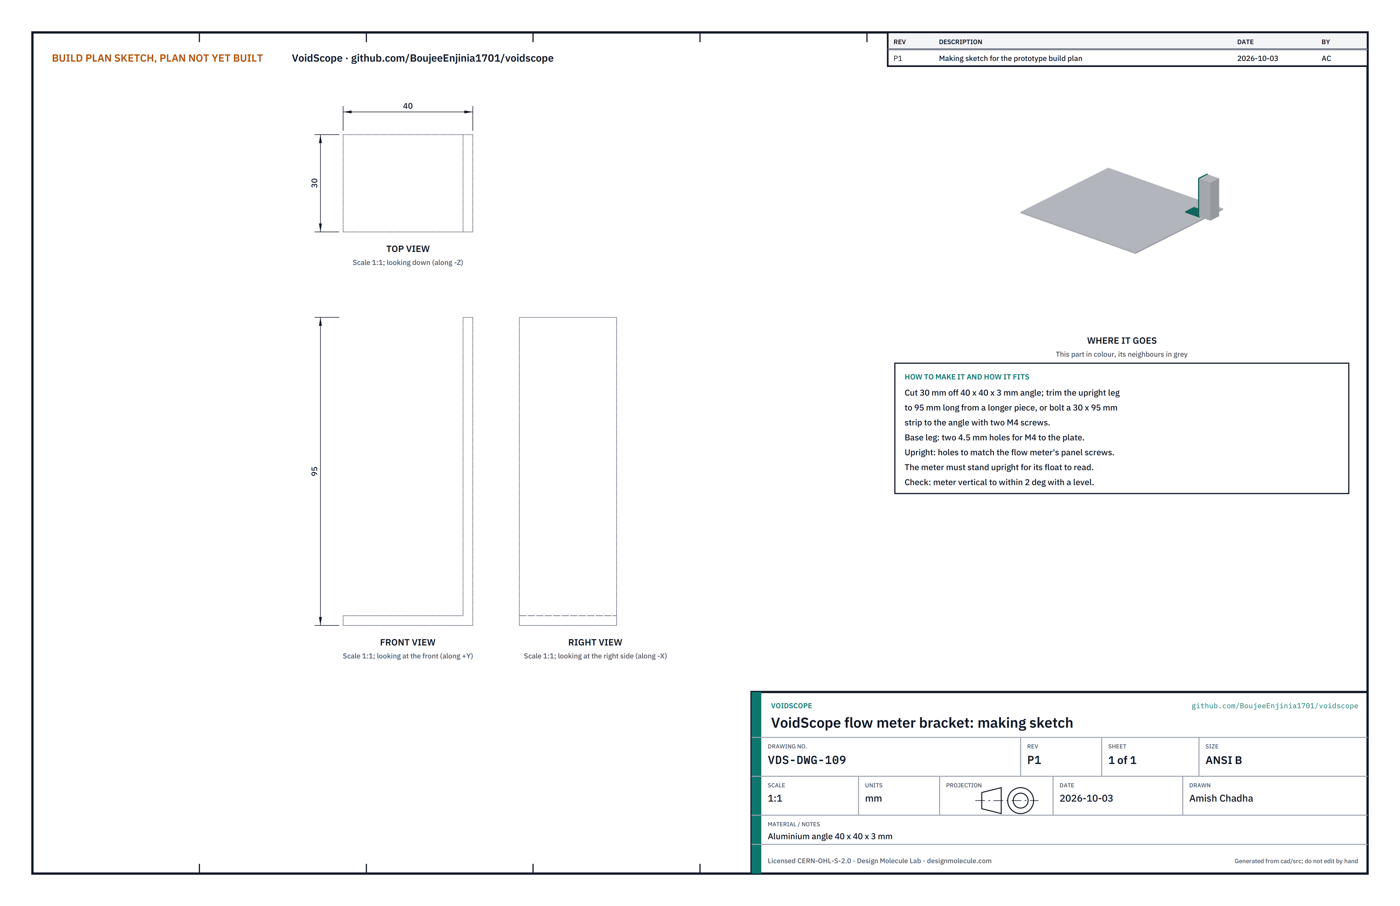
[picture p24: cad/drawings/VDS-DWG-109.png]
Figure 14. Making sketch of the flow meter bracket


*Figure 14. Flow meter bracket making sketch (VDS-DWG-109).*

**What it is and what it is made from.** A short aluminium angle that holds the flow meter upright. Aluminium angle 40 x 40 x 3 mm.

**How to make it.** Cut 30 mm of angle and extend the upright leg to 95 mm with a bolted strip if the angle is too short. Drill two 4.5 mm holes in the base leg and holes in the upright to match the flow meter's panel screws.

**How it fits the parts next to it.** The base leg bolts to the plate with two M4 screws; the meter screws to the upright. The meter must stand upright for its float to read.

**Check before moving on.** With the plate on a level bench, the meter is vertical within 2° on a spirit level.

### 3.8 Monitor bracket

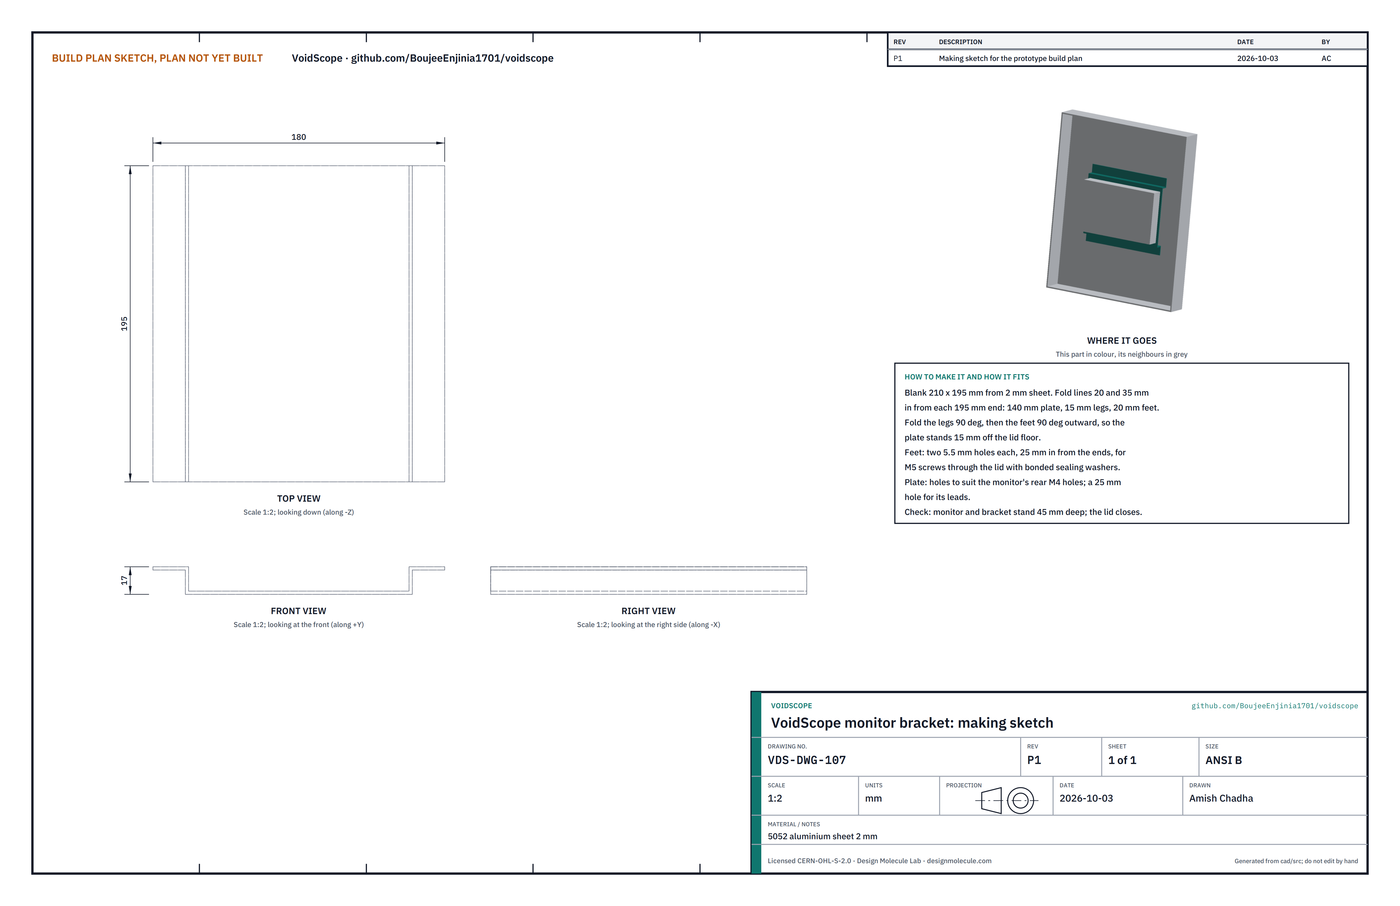
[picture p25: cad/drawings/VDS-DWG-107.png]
Figure 15. Making sketch of the monitor bracket


*Figure 15. Monitor bracket making sketch (VDS-DWG-107), drawn as it sits with the lid closed.*

**What it is and what it is made from.** A folded plate that holds the monitor 15 mm off the lid floor. 5052 aluminium sheet, 2 mm.

**How to make it.**

1. Cut a 210 x 195 mm blank. Mark fold lines 20 mm and 35 mm in from each 195 mm end.
2. Fold the 35 mm lines 90° up (the legs) and the 20 mm lines 90° out (the feet).
3. Drill two 5.5 mm holes in each foot, 25 mm in from its ends; drill the plate to match the monitor's rear M4 holes and a 25 mm hole for its leads.

**How it fits the parts next to it.**

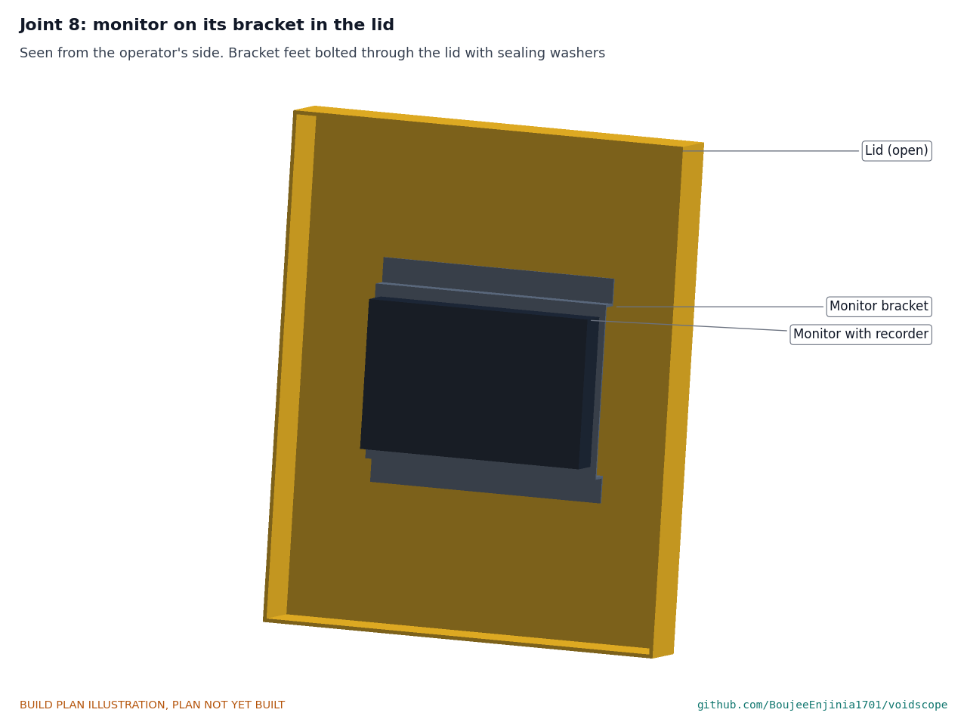
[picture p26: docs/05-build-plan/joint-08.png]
Figure 16. Joint 8: the monitor in the lid


*Figure 16. The bracket's feet bolt through the lid; the monitor screws to the bracket's plate and faces the operator when the lid is open.*

**Check before moving on.** Bracket and monitor together stand 45 mm deep or less, so the lid still closes.

### 3.9 Surface unit case, drilled

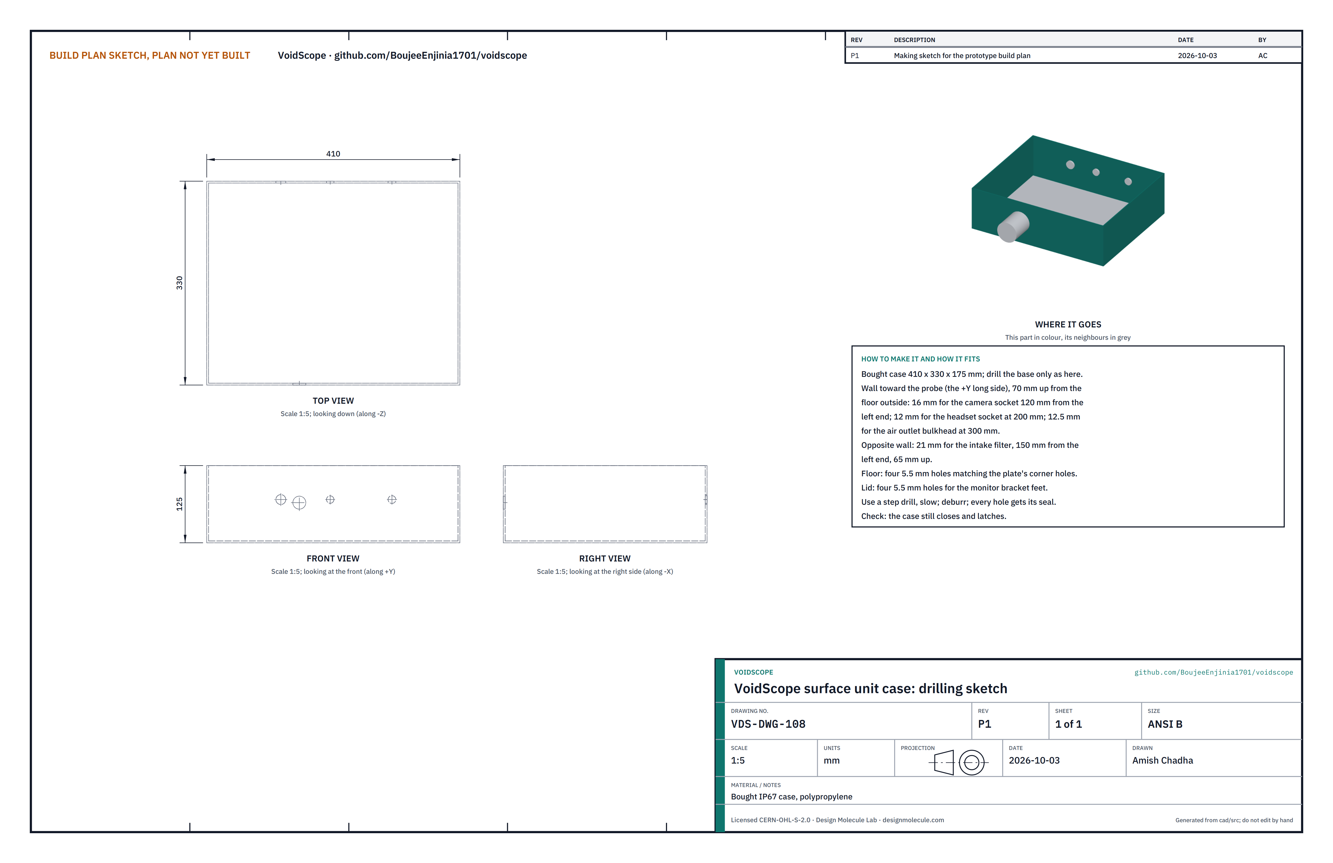
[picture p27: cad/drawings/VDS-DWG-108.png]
Figure 17. Drilling sketch of the case


*Figure 17. Case drilling sketch (VDS-DWG-108).*

**What it is and what it is made from.** A bought IP67 hard case, about 410 x 330 x 175 mm outside, drilled for the plate, the wall fittings and the filter, and its lid drilled for the monitor bracket.

**How to make it.**

1. On the long wall that will face the probe, 70 mm up from the floor outside: drill 16 mm for the camera socket 120 mm from the left end, 12 mm for the headset socket at 200 mm and 12.5 mm for the air outlet at 300 mm.
2. On the opposite wall, drill 21 mm for the intake filter, 150 mm from the left end and 65 mm up.
3. In the floor, drill four 5.5 mm holes to match the plate's corner holes (use the plate as a template). In the lid, drill four 5.5 mm holes to match the bracket feet.
4. Use a step drill at low speed so the plastic does not crack; deburr every hole.

**How it fits the parts next to it.** Every fitting goes through its hole with its seal on the outside and its nut inside; every screw through the floor or lid has a bonded sealing washer, so the case stays sealed.

**Check before moving on.** The case closes and latches with nothing fitted.

### 3.10 Bending links (make 4)

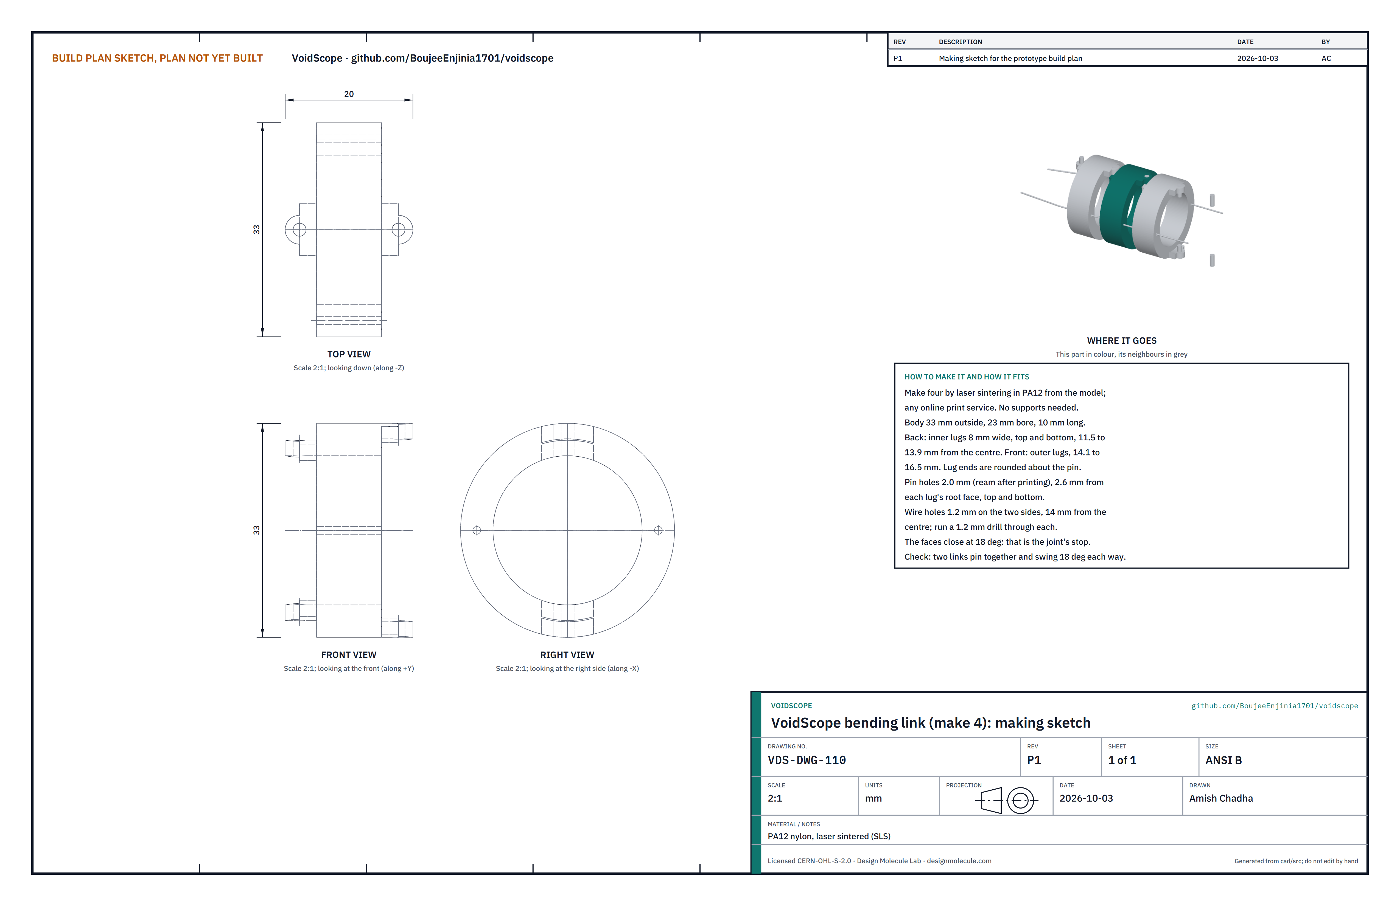
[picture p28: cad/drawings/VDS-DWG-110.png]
Figure 18. Making sketch of a bending link


*Figure 18. Bending link making sketch (VDS-DWG-110).*

**What it is and what it is made from.** The four short rings that let the camera tip bend. Each is printed in PA12 nylon by laser sintering (any online print service can make them from the model): a ring 33 mm across with a 23 mm bore and a 10 mm body, with a pair of thin lugs top and bottom at each end.

**How to make it.**

1. Order four links printed in PA12 from the model file. No supports are needed.
2. Ream the four 2.0 mm pin holes in each link. The holes sit 2.6 mm from the face each lug grows out of.
3. Run a 1.2 mm drill through the two wire holes on the sides, 14 mm out from the centre.
4. Clean off loose powder; the lug ends are rounded and must stay that way.

**How it fits the parts next to it.**

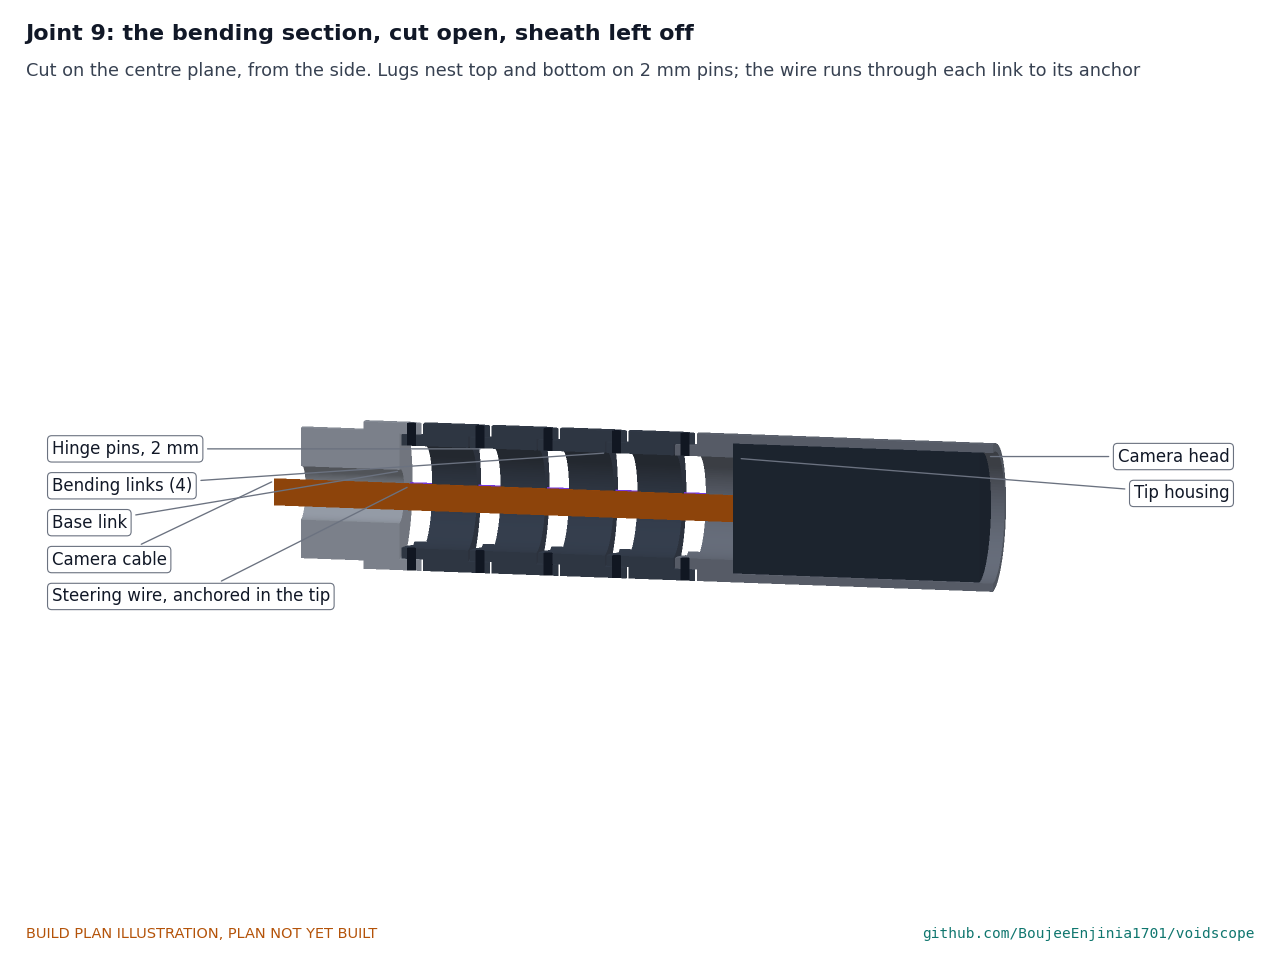
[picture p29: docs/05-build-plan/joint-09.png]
Figure 19. Joint 9: the bending section cut open


*Figure 19. The links nest lug inside lug, top and bottom, on 2 mm pins. Each joint closes at 18°, so the five joints give 90° each way. The steering wire runs through every link to its anchor in the tip housing; the camera cable runs down the middle.*

The back lugs of each link sit inside the front lugs of the one behind, 0.2 mm apart, with a 2 mm stainless pin through each pair. The pin is a press fit in the outer lug and turns freely in the inner one. A 0.6 mm silicone sheath goes over the whole bending section; its ends are bound with waxed thread and sealed with silicone.

**Check before moving on.** Two links pinned together swing 18° each way, then their faces meet. They do not wobble, and a 0.6 mm wire slides through both wire holes.

### 3.11 Base link

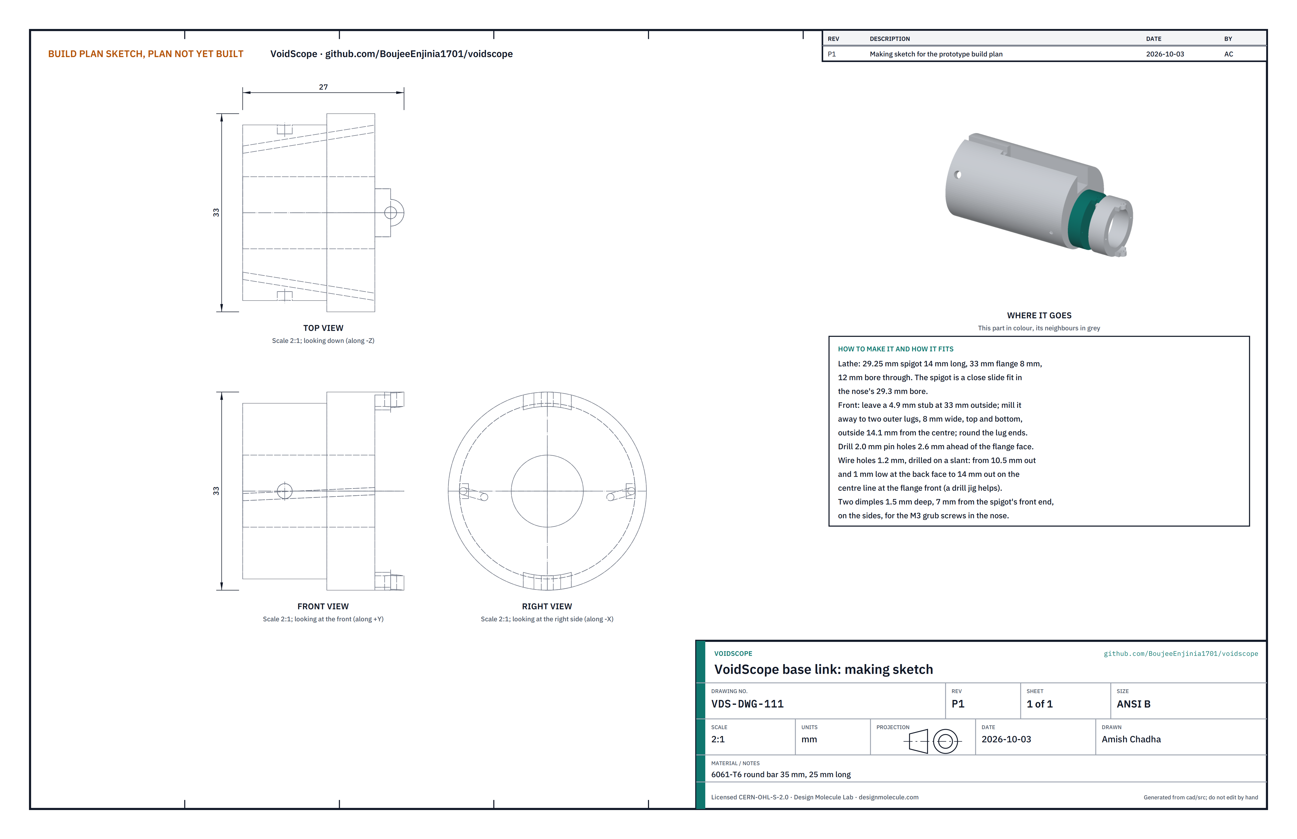
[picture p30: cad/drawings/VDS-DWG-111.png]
Figure 20. Making sketch of the base link


*Figure 20. Base link making sketch (VDS-DWG-111).*

**What it is and what it is made from.** The fixed first joint of the tip: it plugs into the nose and carries the first pair of lugs. 6061-T6 round bar, 35 mm, 25 mm long; two M3 nylon-tipped grub screws.

**How to make it.**

1. Turn a 29.25 mm spigot 14 mm long and a 33 mm flange 8 mm long, and bore 12 mm through. The spigot is a close slide fit in the nose's 29.3 mm bore.
2. Leave a 4.9 mm stub ahead of the flange, 33 mm across; mill it away except for two lugs 8 mm wide at the top and bottom, from 14.1 mm out to the outside. Round the lug ends; drill 2.0 mm pin holes 2.6 mm ahead of the flange face.
3. Drill the two 1.2 mm wire holes on a slant: each starts at the back face 10.5 mm to one side and 1 mm below the centre, and comes out of the flange front 14 mm to that side on the centre line. A small drill jig makes this easier.
4. Drill two dimples 1.5 mm deep in the spigot's sides, 7 mm from its front end, for the grub screw points.

**How it fits the parts next to it.** The spigot goes into the front of the nose until the flange meets the nose's front face, wire holes to the sides and lugs top and bottom. The two grub screws go in through the nose's sides into the dimples. Link 1's back lugs fit inside the base link's lugs.

**Check before moving on.** The spigot slides into the nose by hand, the flange sits flat on the nose's front face and the screws hold it without play.

### 3.12 Tip housing

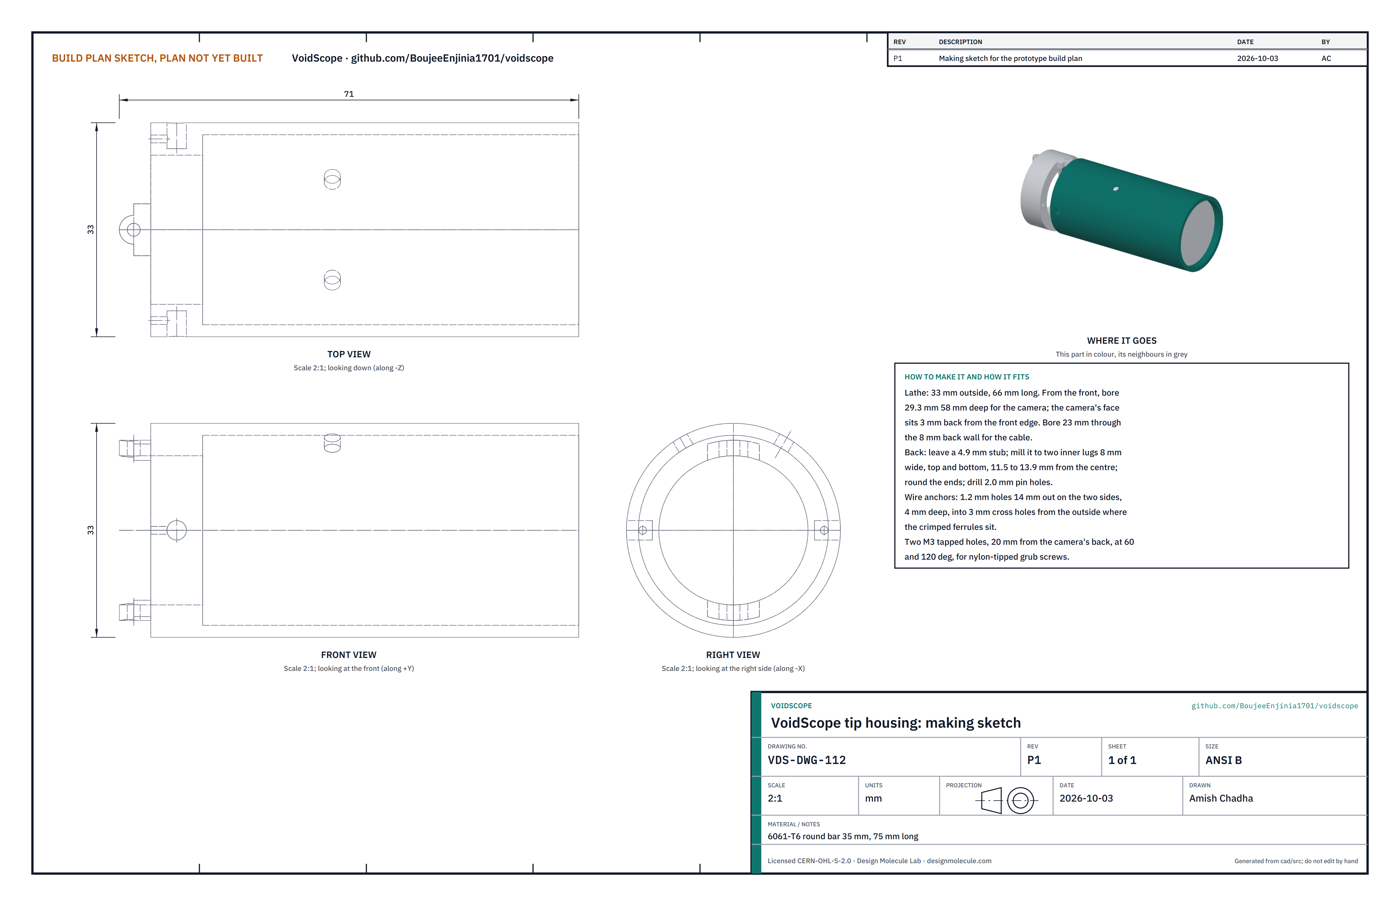
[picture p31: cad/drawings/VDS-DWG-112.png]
Figure 21. Making sketch of the tip housing


*Figure 21. Tip housing making sketch (VDS-DWG-112).*

**What it is and what it is made from.** The last joint of the tip, holding the camera. 6061-T6 round bar, 35 mm, 75 mm long; two M3 nylon-tipped grub screws; two 2.5 mm crimp ferrules.

**How to make it.**

1. Turn to 33 mm outside and 66 mm long. From the front, bore 29.3 mm, 58 mm deep, for the camera. Bore 23 mm through the 8 mm back wall for the cable.
2. Leave a 4.9 mm stub at the back; mill it to two lugs 8 mm wide at the top and bottom, from 11.5 to 13.9 mm out; round the ends; drill 2.0 mm pin holes.
3. Wire anchors: on each side, 14 mm out from the centre, drill 1.2 mm in from the back face 4 mm deep, into a 3 mm cross hole drilled in from the outside. The crimped ferrule sits in the cross hole.
4. Drill and tap two M3 holes 20 mm from the camera's back face, at 60° and 120° from the side toward the top, for the camera's grub screws.

**How it fits the parts next to it.** The camera slides in from the front until its back meets the step; its face then sits 3 mm behind the front edge, protected. Two nylon-tipped grub screws hold it without marking it. The housing's back lugs fit inside link 4's front lugs.

**Check before moving on.** The camera slides in by hand and its face sits 3 mm back. A wire with a crimped ferrule pulls tight against its anchor without slipping.

### 3.13 Steering control

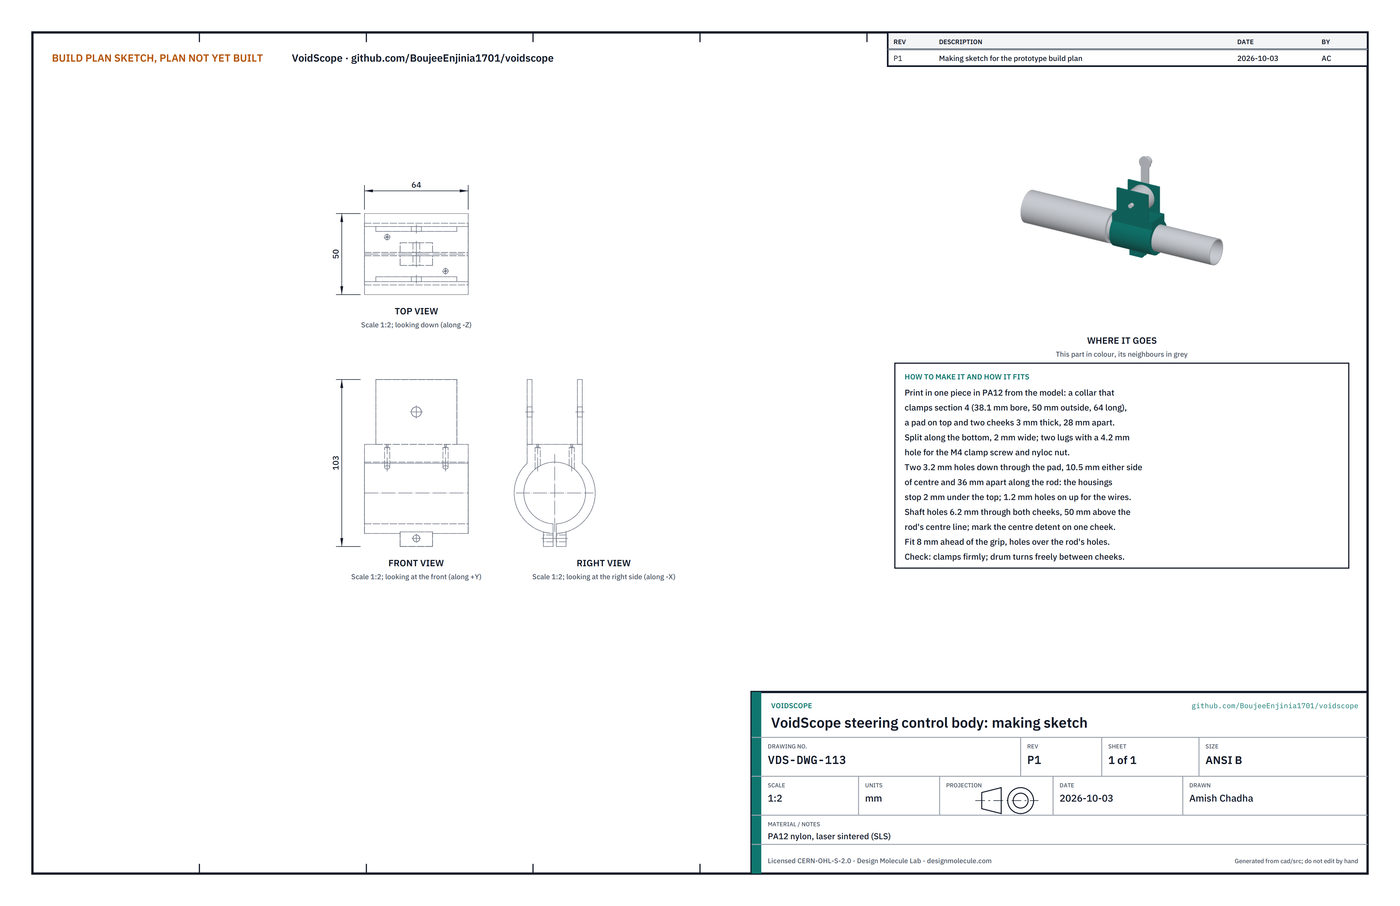
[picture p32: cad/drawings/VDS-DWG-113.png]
Figure 22. Making sketch of the steering control body


*Figure 22. Steering control body making sketch (VDS-DWG-113).*

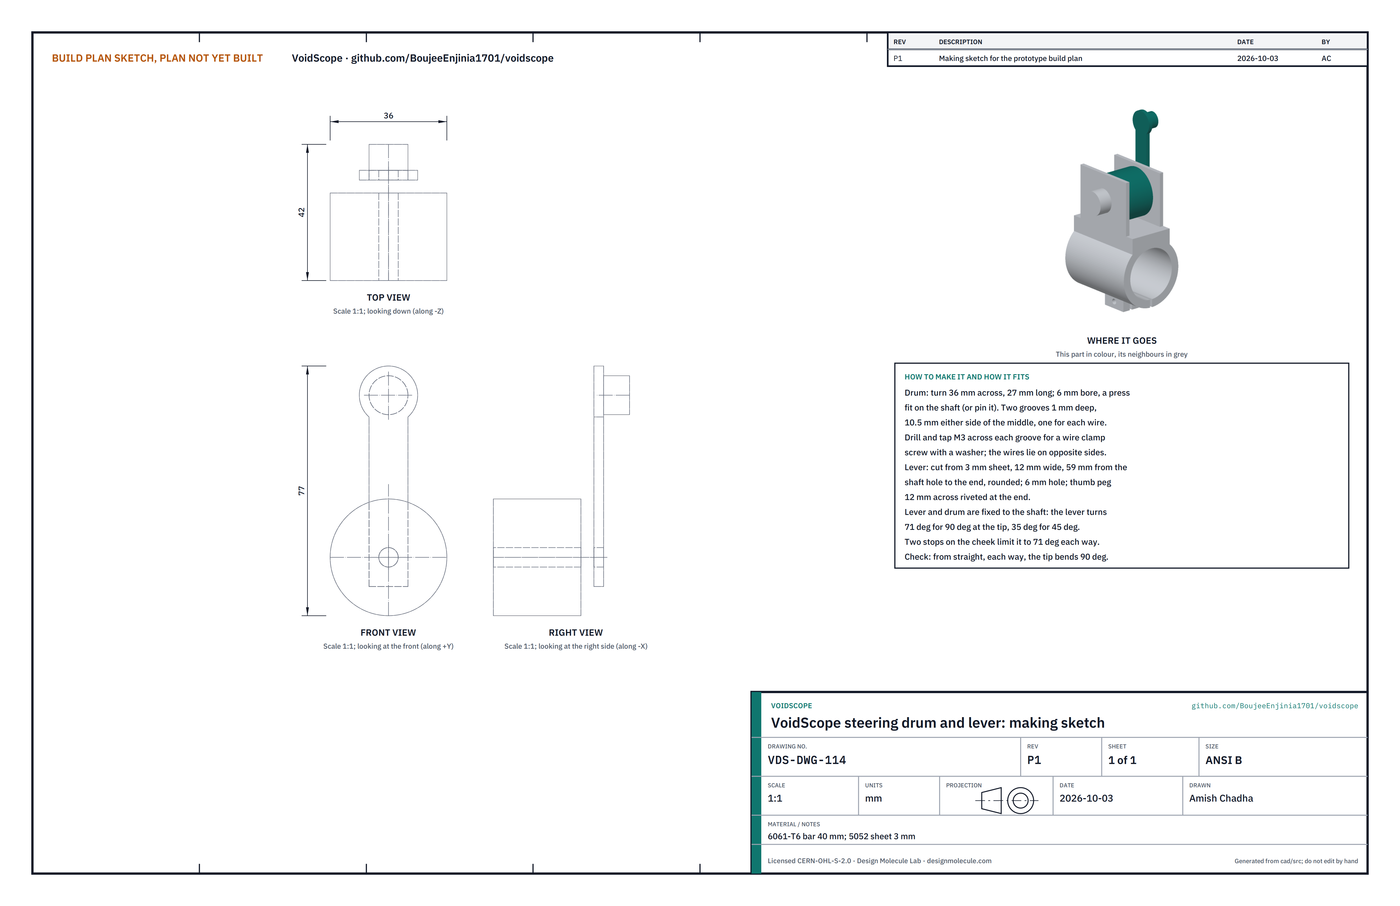
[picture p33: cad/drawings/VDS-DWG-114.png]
Figure 23. Making sketch of the drum and lever


*Figure 23. Steering drum and lever making sketch (VDS-DWG-114).*

**What it is and what it is made from.** The handle end of the steering, clamped on section 4 just ahead of the grip. The body is printed in PA12 nylon in one piece: a collar that clamps the rod, a pad on top and two cheeks 28 mm apart. Between the cheeks a 36 mm aluminium drum on a 6 mm stainless shaft winds the two wires; a 50 mm lever with a thumb peg turns it, and a knob on the other side locks it by friction. Bought: the shaft, the knob with a spring washer, an M4 clamp screw and nut.

**How to make it.**

1. Order the body printed in PA12 from the model file. Clean out the two 3.2 mm housing holes and the 1.2 mm wire holes above them, and the 6.2 mm shaft holes in the cheeks.
2. Turn the drum from 40 mm bar: 36 mm across, 27 mm long, a 6 mm bore. Cut two grooves 1 mm deep, 10.5 mm either side of the middle. Drill and tap M3 across each groove for a small clamp screw and washer.
3. Cut the lever from 3 mm sheet, 12 mm wide and 59 mm from the shaft hole to its rounded end; rivet a 12 mm thumb peg at the end.
4. Fit two small stops on the lever's cheek so it turns 71° each way from upright, and mark the upright position: the tip is straight there.

**How it fits the parts next to it.**

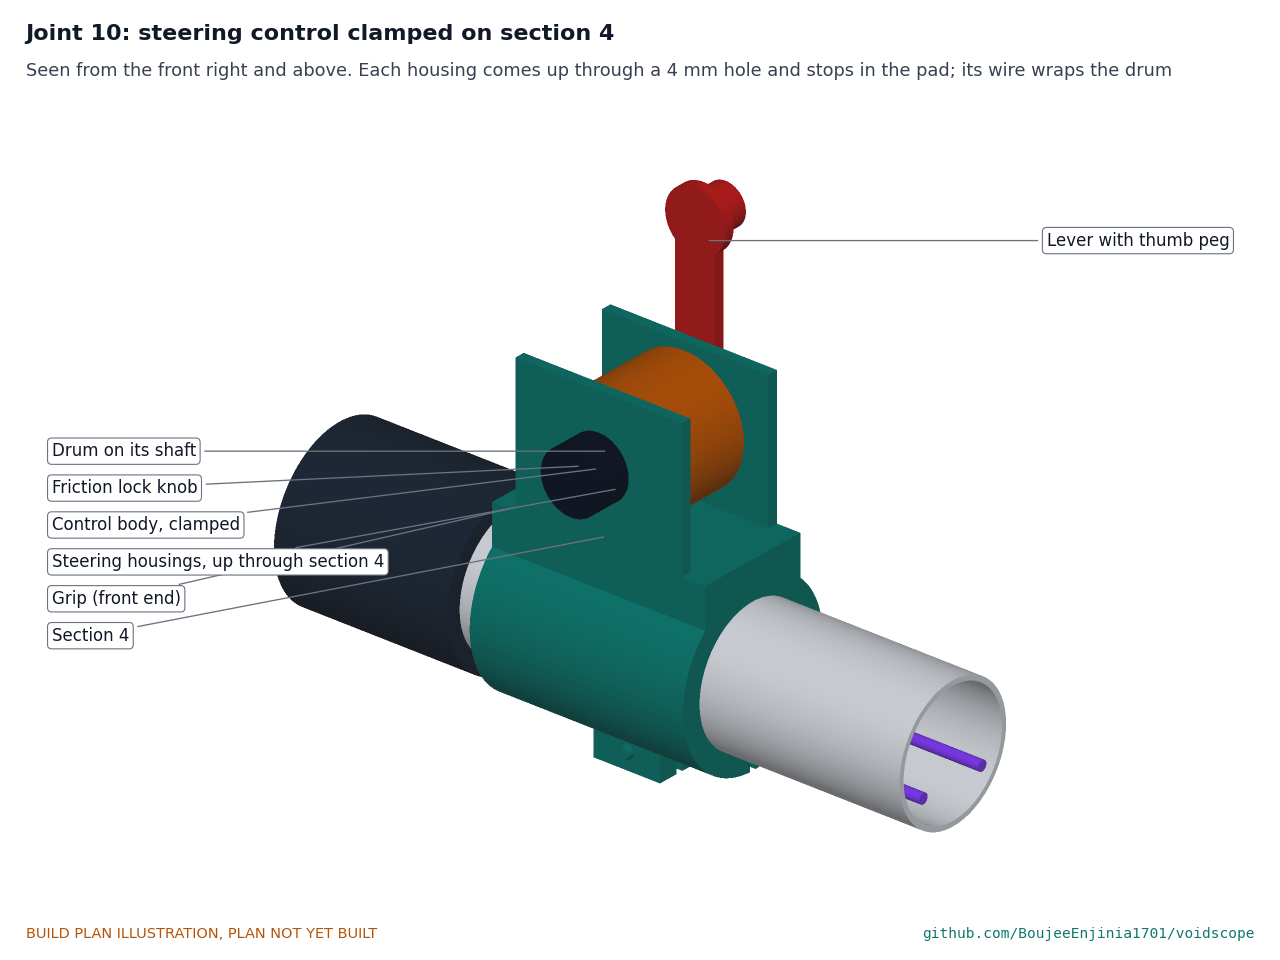
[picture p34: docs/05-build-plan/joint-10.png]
Figure 24. Joint 10: the steering control on section 4


*Figure 24. The body clamps section 4 8 mm ahead of the grip. Each housing comes up through its 4 mm hole and stops in the pad; its wire goes on up to its groove on the drum.*

The body's two housing holes sit over section 4's two 4 mm holes. The lever turns the drum: from upright, 35° of lever bends the tip 45°, and 71° bends it 90°. About 5 N at the thumb holds the full bend. The knob squeezes the cheeks to hold any position.

**Check before moving on.** The body clamps firmly with the screw done up, and the drum turns freely between the cheeks with 0.5 mm to spare on each side.

### 3.14 Bought components

- **Camera head:** sealed pipe-inspection head, 29 mm across, about 55 mm long, IP68, 1080p (AHD), about 90° view, 12 dimmable LEDs, 12 V, with a pigtail at least 170 mm long. Trim the pigtail to 170 mm: it runs back through the tip to a splice in the nose bore.
- **Speaker:** 20 mm IP67 micro speaker, 8 Ω, 0.5 W, about 4 mm thick; a 20 mm disc of perforated stainless sheet as its cover.
- **Cable:** hybrid camera cable, 7 m, with one mini-coax for video and four small cores, 6 mm across at most, with a six-pin aviation plug fitted at the surface end.
- **Guide tube:** PTFE, 8 mm outside, 6 mm bore, 6.5 m.
- **Water set (single use):** food-grade polyurethane tube 4 mm by 2.5 mm, 8 m; silicone bite valve about 11 mm across; 600 mm of 0.5 mm bore food-grade PTFE capillary with two barbed reducers; roller clamp; three-way stopcock; 100 micron strainer; 60 mL syringe. Keep it sealed in its bag until use.
- **Grip:** rubber or foam handlebar grip tube, 38 mm bore, 300 mm.
- **Battery packs (2):** 12.8 V 6 Ah LiFePO4 with built-in protection and an XT60 lead, about 151 x 65 x 94 mm, with a hook-and-loop strap.
- **Blower:** 12 V centrifugal, about 97 x 94 x 33 mm, shut-off pressure 1.0 kPa or less, PWM speed input.
- **Intake filter, flow meter, control modules, wall fittings, headset:** as in the bill of materials, lines 19 to 23.
- **Monitor:** 7 in, AHD input, recorder, 1000 nit or brighter, 12 V, rear M4 holes, 28 mm deep or less.
- **Reservoir:** 1 L graduated food-grade bottle with a bail and a bottom spigot; light stand 0.8 to 2.0 m with a hook arm; mark the stand every 0.1 m.
- **Air hose and sleeve, charger, rod carry case, cleaning kit:** as in the bill of materials, lines 24 to 27.
- **Hinge pins and sheath:** ten 2 x 5 mm stainless dowel pins; silicone tube 33 mm bore, 0.6 mm wall, 80 mm long, two (one spare).
- **Steering wires and housings:** 0.6 mm 7x7 stainless wire rope, two 6 m lengths; PTFE-lined steel-coil push-pull housing 3 mm outside, two 4.4 m lengths; four 2.5 mm crimp ferrules.
- **Steering control fittings:** 6 mm stainless shaft 50 mm long; a friction lock knob with a spring washer; M4 clamp screw and nyloc nut; four M3 nylon-tipped grub screws for the base link and the camera.

## 4. Putting it together

In each picture the parts already fitted are grey and the part being fitted is in colour, with an arrow showing the way it goes in. Long parts are drawn cut short where the whole length would make the picture unreadable.

### Step 1: couplers into the sections

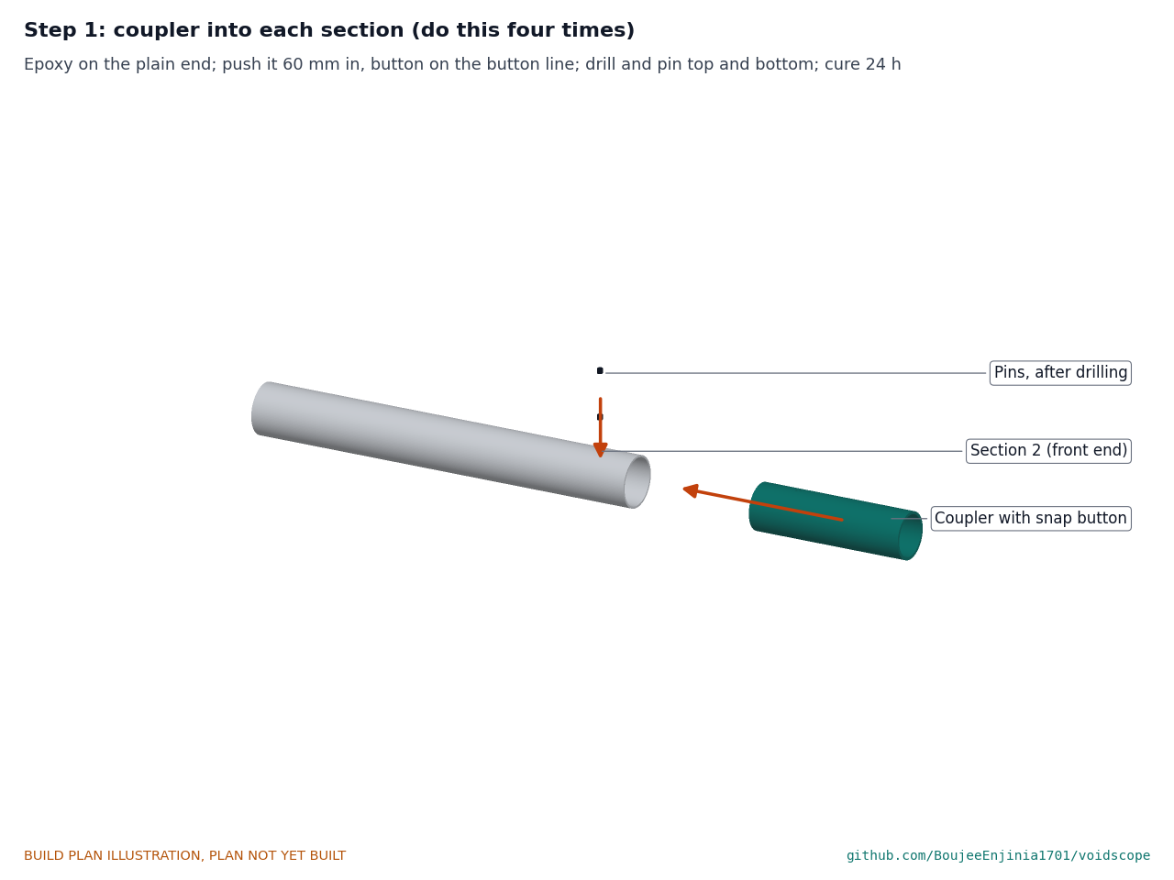
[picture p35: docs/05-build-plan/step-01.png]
Step 1


Done for each of the four sections in section 3.2: epoxy, push in 60 mm with the button lines in line, drill and pin top and bottom, cure for 24 hours. Hold point: do not join any section until the epoxy has cured.

### Step 2: tail cap into section 4

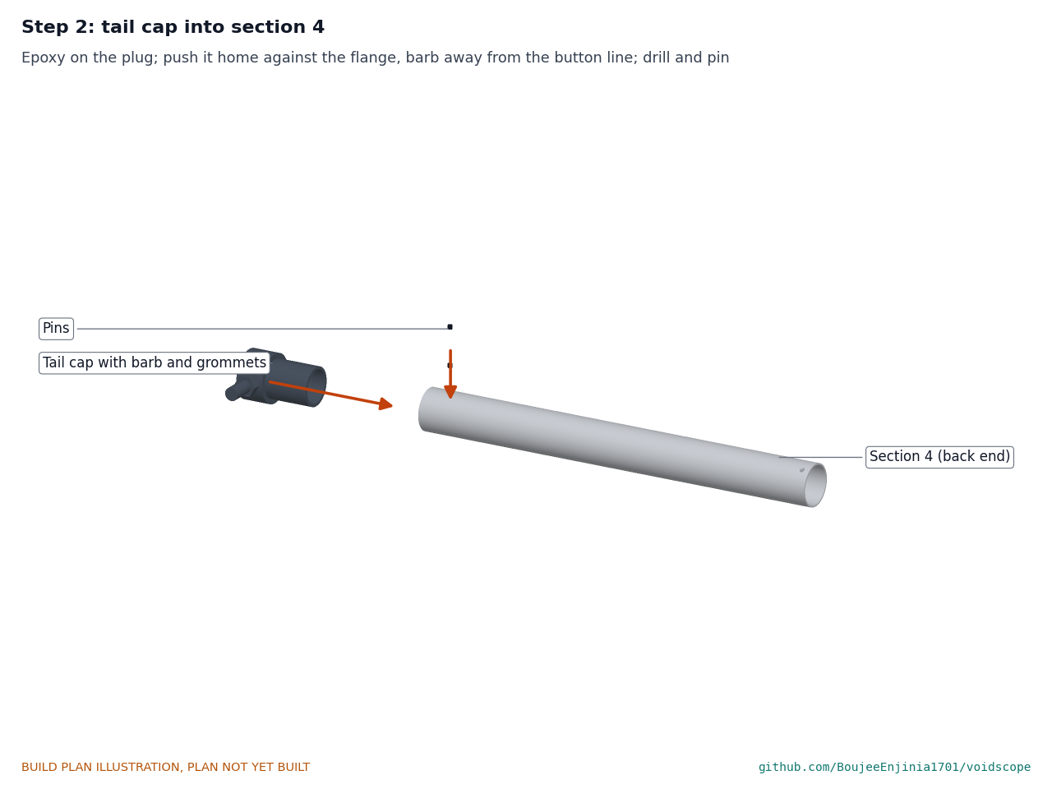
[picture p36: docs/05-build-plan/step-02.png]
Step 2


Epoxy on the plug and in the back end of section 4; push home against the flange with the barb opposite the button line; drill 4.0 mm through tube and plug top and bottom, 20 mm in front of the flange, and press in the pins.

### Step 3: grip and steering control body onto section 4

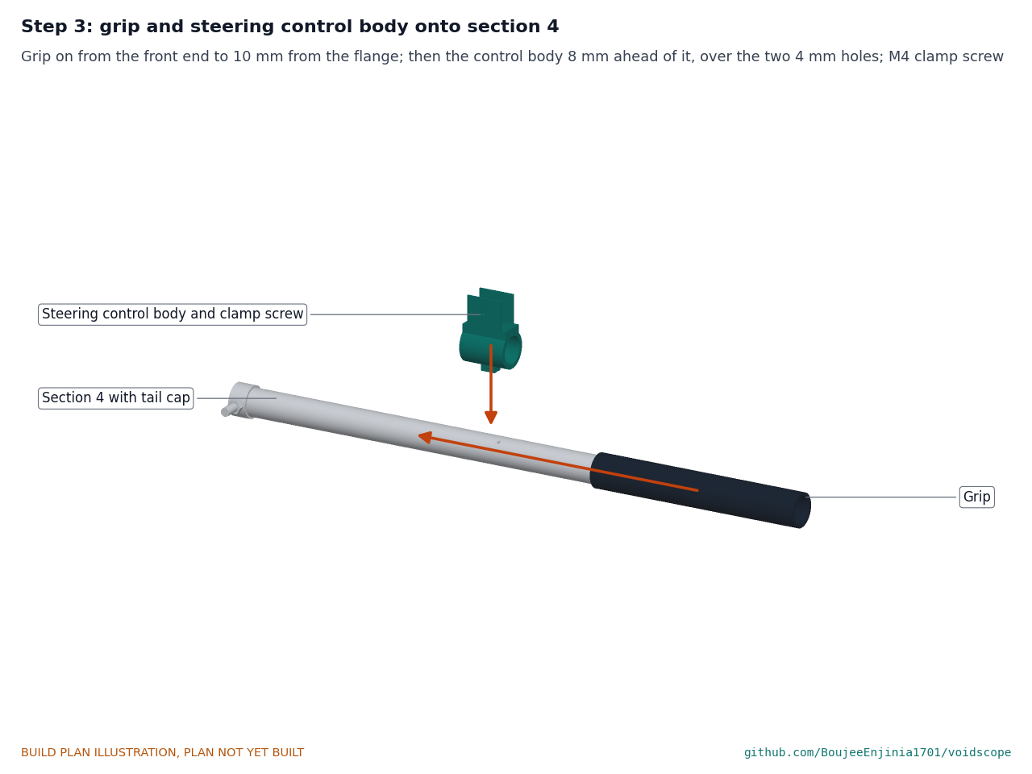
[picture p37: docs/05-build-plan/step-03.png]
Step 3


Wet the inside of the grip with soapy water and slide it on from the front end of section 4 until it stops 10 mm in front of the flange. Let it dry. Then slide the steering control body on from the front end until it is 8 mm ahead of the grip, with its two housing holes over the two 4 mm holes on top of section 4. Do up the M4 clamp screw.

### Step 4: speaker into the collar

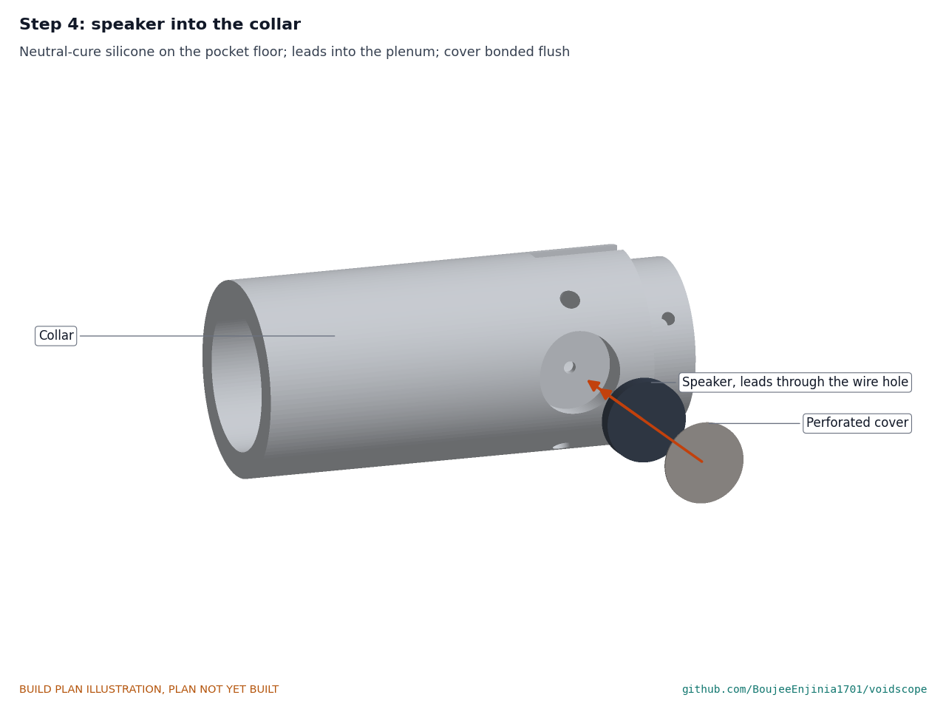
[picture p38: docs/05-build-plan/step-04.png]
Step 4


Feed the speaker leads through the 3 mm wire hole into the chamber. Bed the speaker on neutral-cure silicone, then bond the perforated cover over it, flush.

### Step 5: thread the cable, guide tube and steering housings through every section

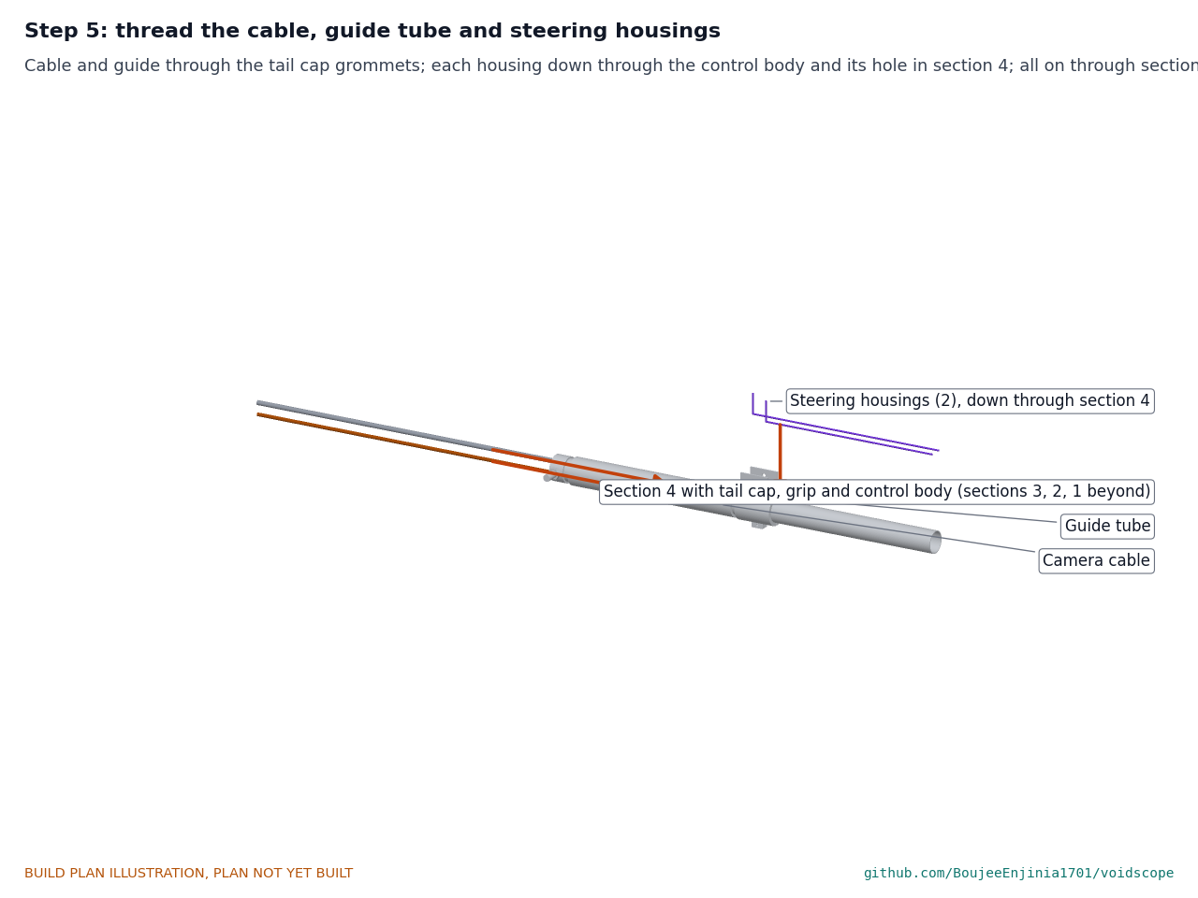
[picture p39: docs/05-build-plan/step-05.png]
Step 5


Lay the sections in a line, tail cap at the back. From the tail cap end, feed the cable and the guide tube through their grommets and through sections 4, 3, 2 and 1 in turn, staying in the spaces above and below each spring. Feed each steering housing, with its wire inside it, down through its hole in the control body and section 4, then forward through sections 4 to 1 low down on its own side, below the springs. Leave 1 m of the cable and guide out at the front and about 2 m of each behind the tail cap. Seal round the housings where they pass section 4 with a little silicone.

### Step 6: cable, guide tube and housings into the collar

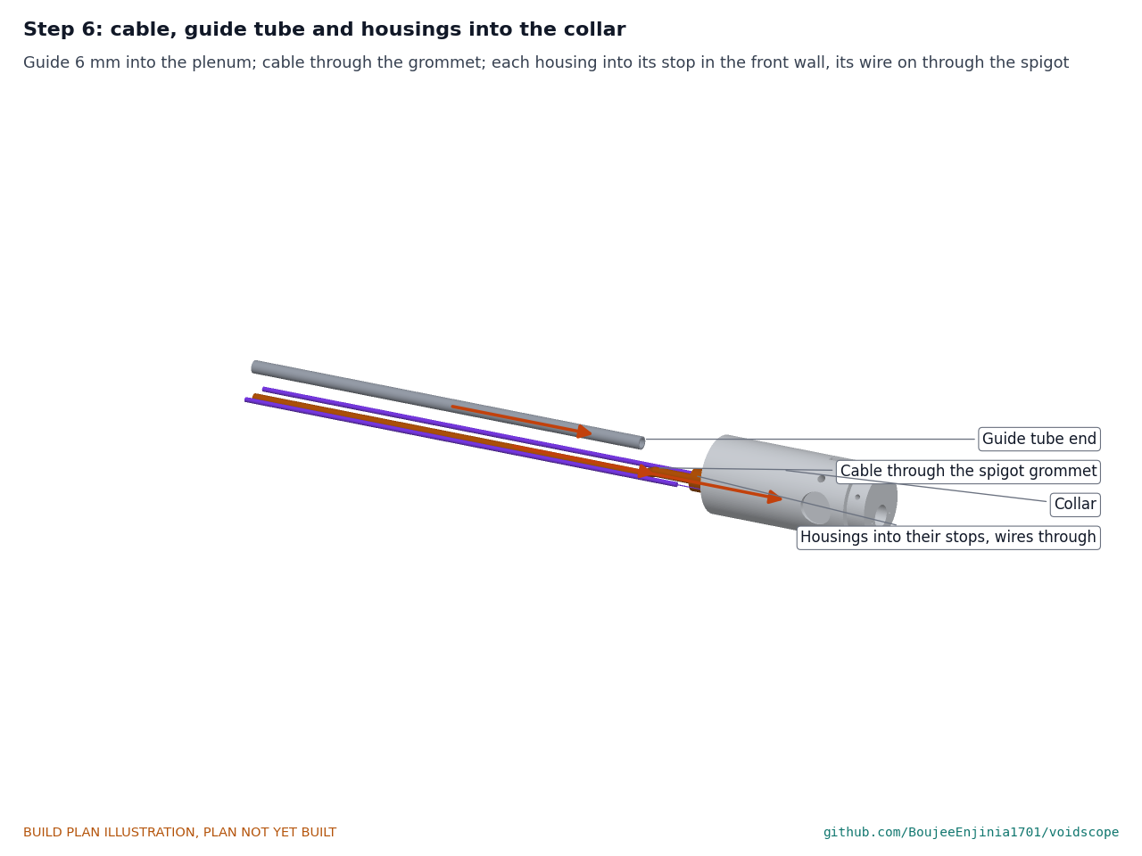
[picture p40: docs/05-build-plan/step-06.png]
Step 6


Push the guide tube 6 mm into the collar's air chamber. Push each housing into its 3.2 mm stop in the chamber's front wall and its wire on through the 1.2 mm hole and out of the spigot. Break the speaker pair out of the cable inside the chamber and solder it to the speaker leads; pass the rest of the cable through the spigot grommet. Cover every joint with heat-shrink and seal the grommet with a little silicone.

### Step 7: nose onto the collar

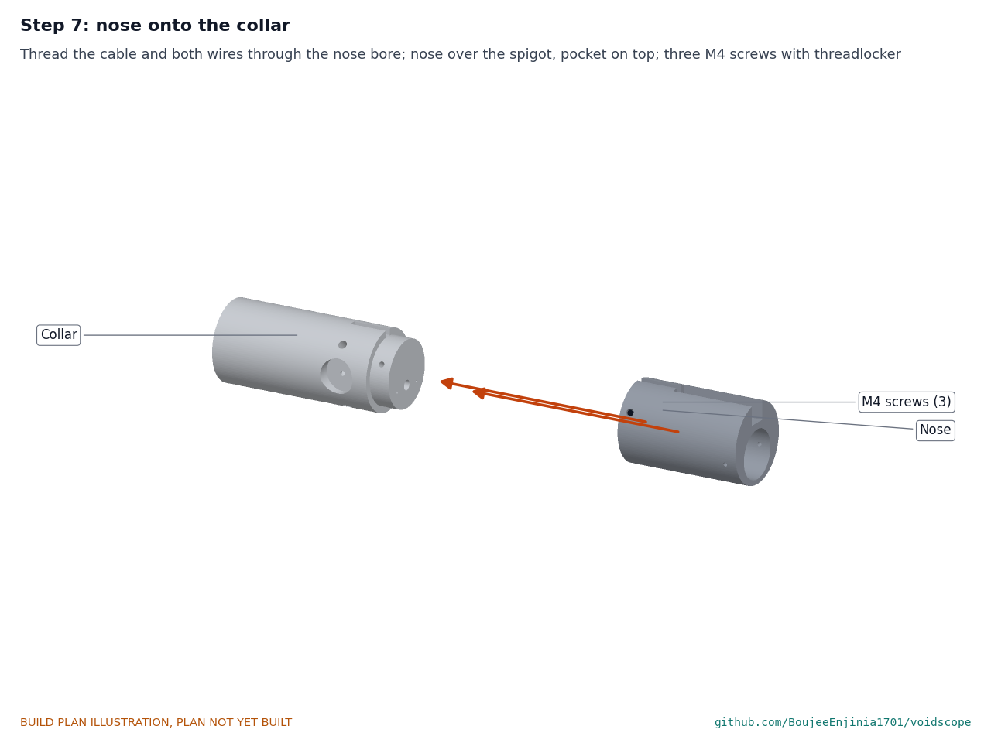
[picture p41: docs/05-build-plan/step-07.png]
Step 7


Thread the cable and both wires through the nose's bore from behind. Slide the nose onto the spigot with its pocket on top and fix it with three M4 countersunk screws and threadlocker.

### Step 8: steerable tip onto the nose

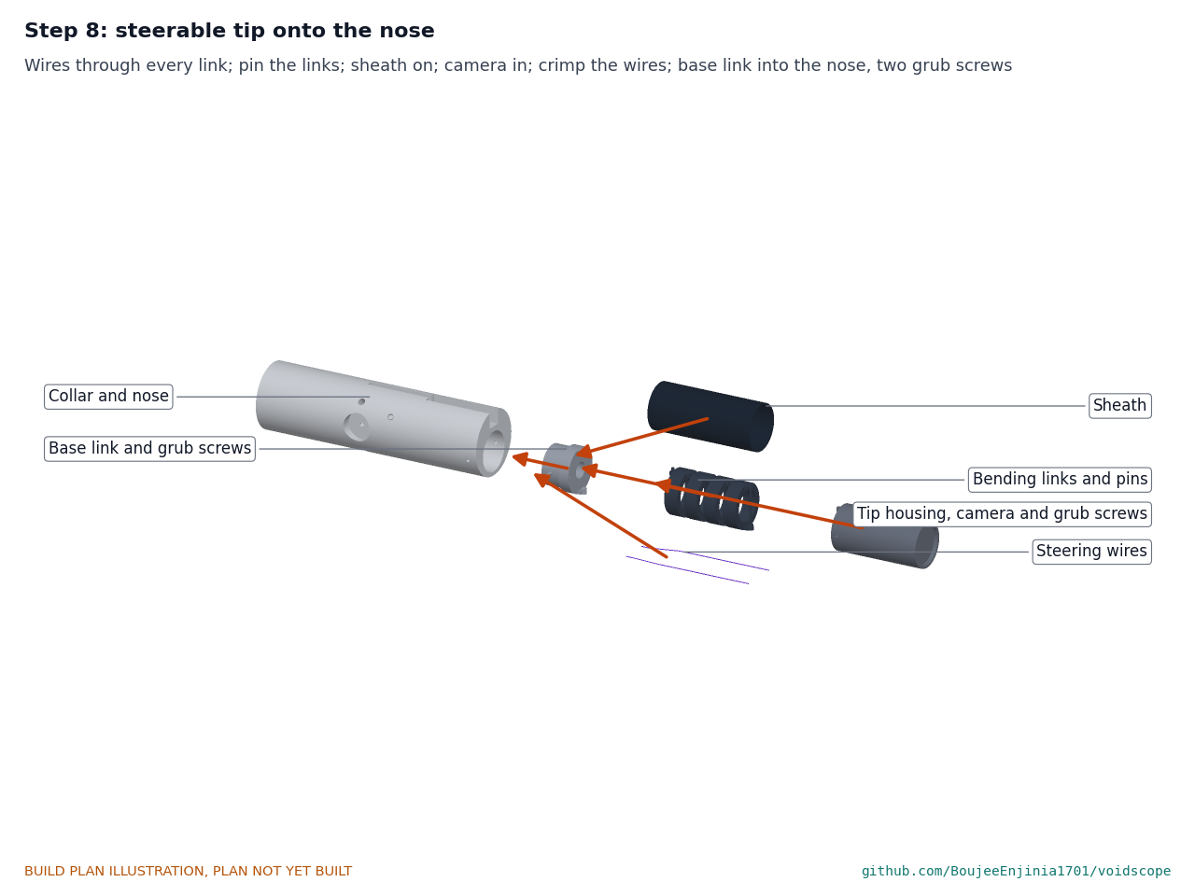
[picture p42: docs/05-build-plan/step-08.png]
Step 8


Thread each wire through its slanted hole in the base link, then through the side holes of links 1 to 4 in turn, and the camera pigtail back through the tip housing, the links and the base link. Pin the joints: each pin is pressed into the outer lug and turns in the inner one. Slide the sheath over the bending section and bind its ends. Splice the camera pigtail to the cable in the nose bore and heat-shrink it, then push the base link into the nose and fit its two grub screws. Push the camera into the tip housing until it meets the step and fit its two grub screws. Pull each wire through its anchor hole, crimp a ferrule on it in the cross hole, and trim it.

### Step 9: section 1 into the collar

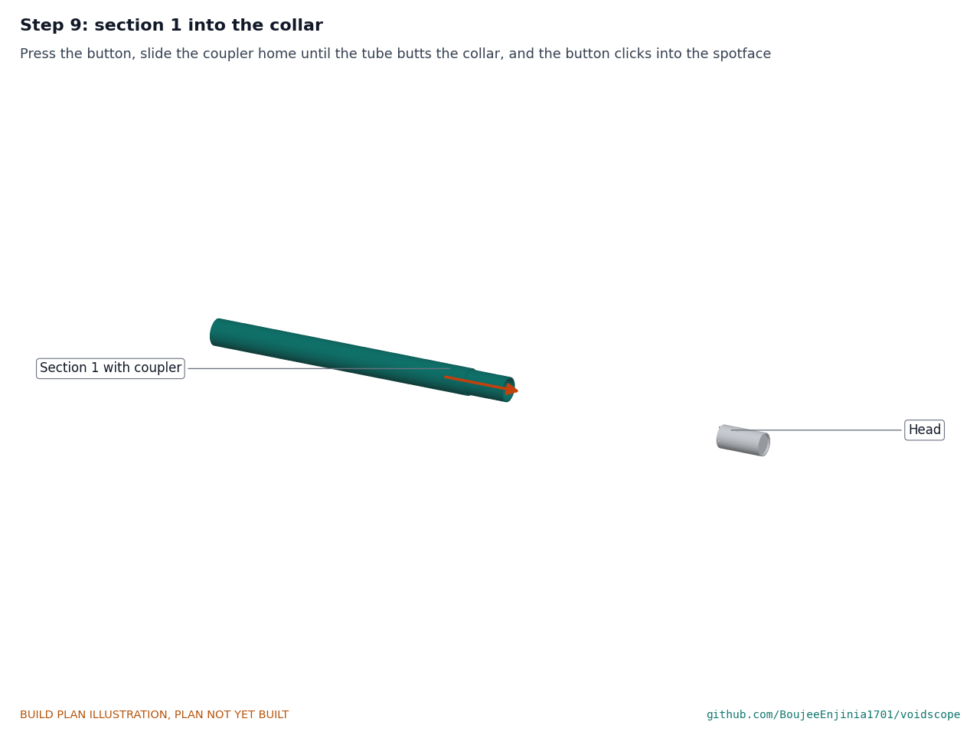
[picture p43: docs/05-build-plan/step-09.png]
Step 9


Slide section 1 forward along the lines, press its front button and push the coupler into the collar socket until the tube butts the collar and the button clicks into the spotface.

### Step 10: join sections 2, 3 and 4

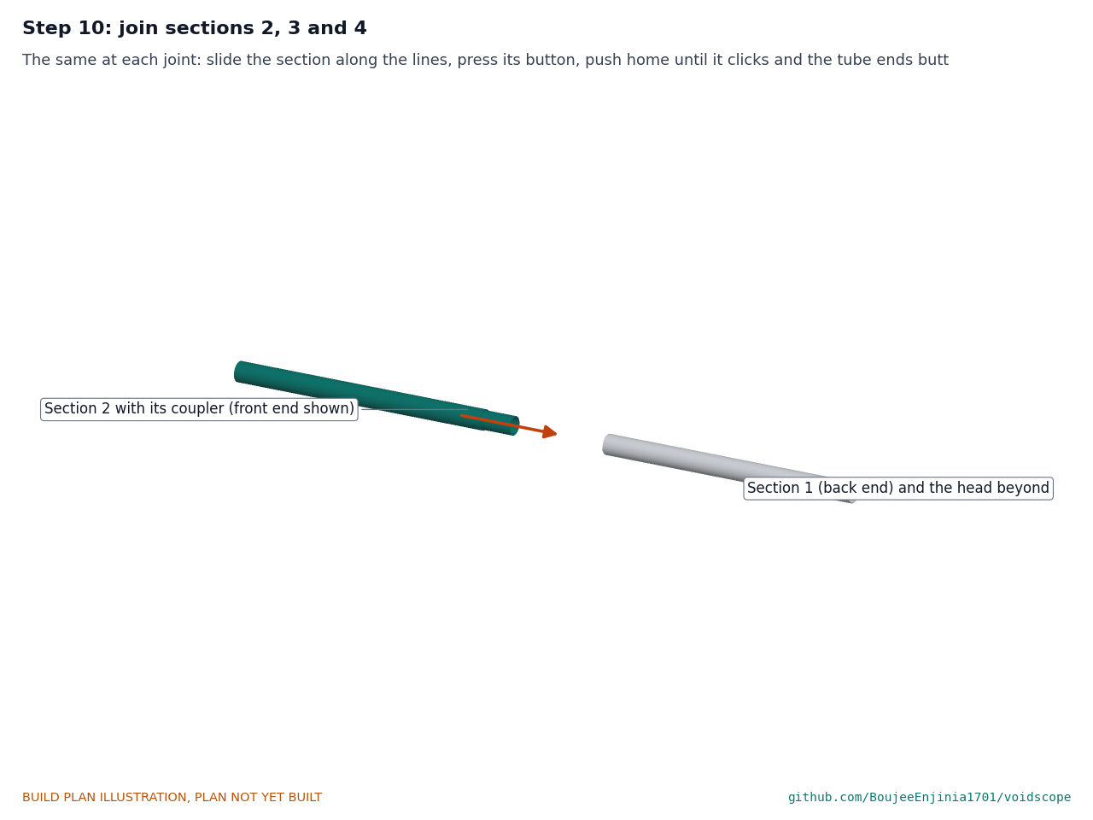
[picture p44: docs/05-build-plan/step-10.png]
Step 10


Slide each section forward along the lines and click it onto the one in front. The depth bands should run on in order. To store the probe, undo the joints and lay the sections side by side in the carry case, with the lines and housings in loose loops at least 150 mm across.

### Step 11: steering wires onto the drum; set the tip straight

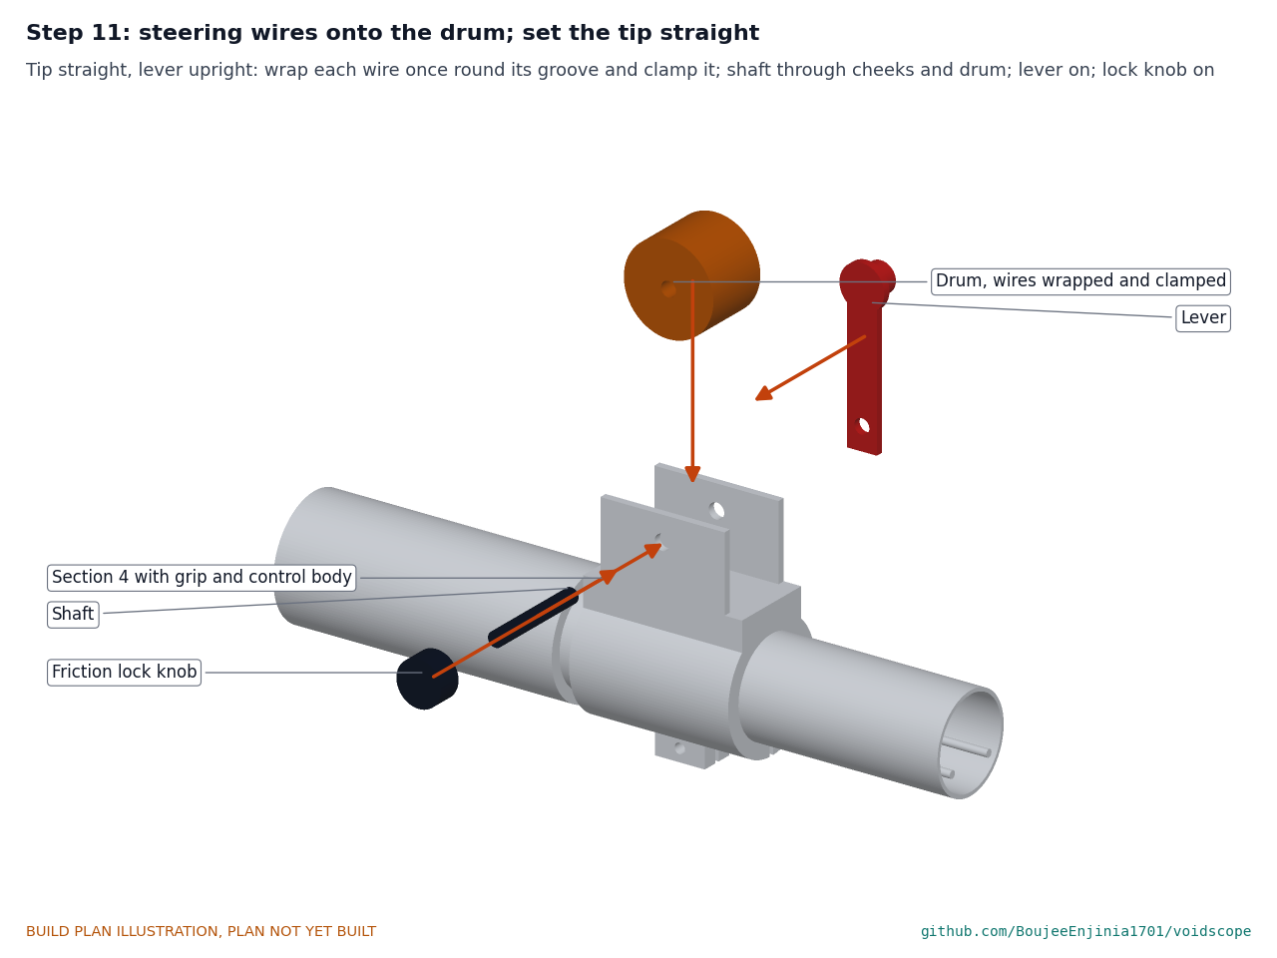
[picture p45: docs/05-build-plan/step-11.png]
Step 11


With the tip straight and the lever's place marked upright, take each wire up from its housing stop, wrap it once round its own groove on the drum (one from the front, one from the back) and clamp it with the groove's screw, taking up the slack by hand. Push the shaft through one cheek, the drum and the other cheek; fit the lever upright on the button-line side and the lock knob on the other. Turn the lever each way to its stop: the tip must bend 90° to each side and come back straight when the lever is upright.

### Step 12: water tube through the guide and into the bite valve pocket

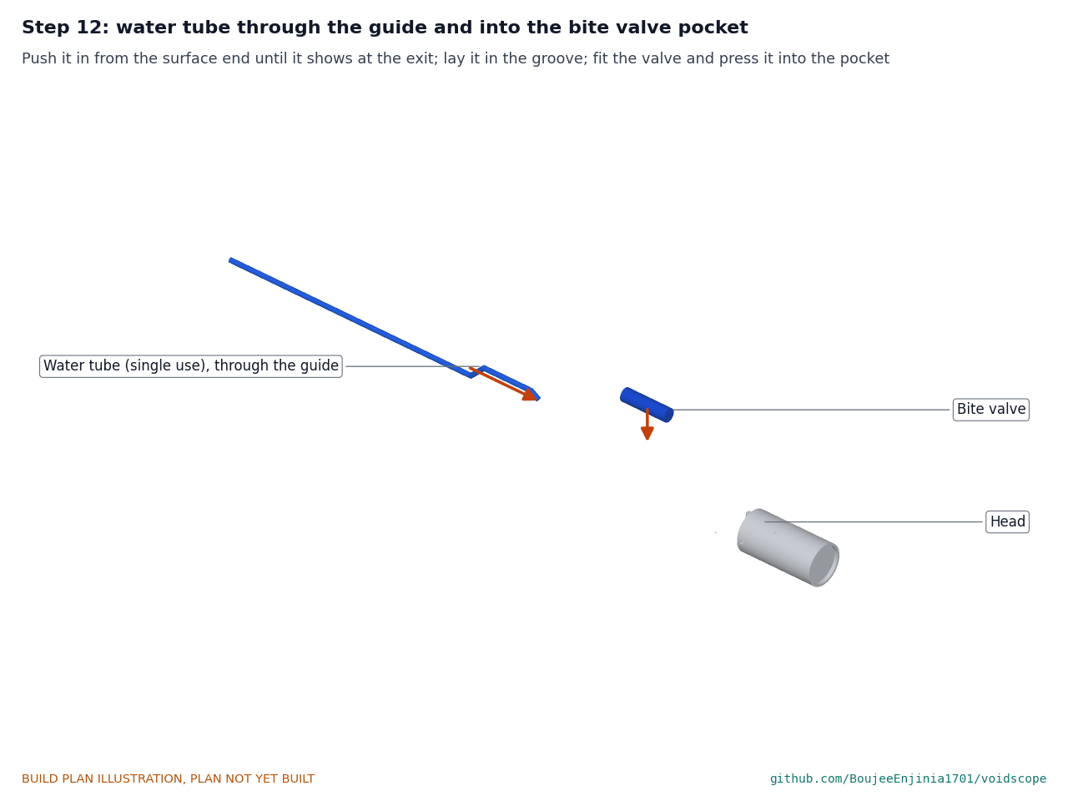
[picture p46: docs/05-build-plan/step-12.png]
Step 12


From the surface end, push a new water tube through the guide tube until it appears in the collar's air chamber; guide it up and out of the 45° exit with a bent wire, lay it in the top groove, fit the bite valve and press the valve into its pocket. Do this with clean gloves; the tube end must touch nothing but the valve.

### Step 13: equipment plate into the case

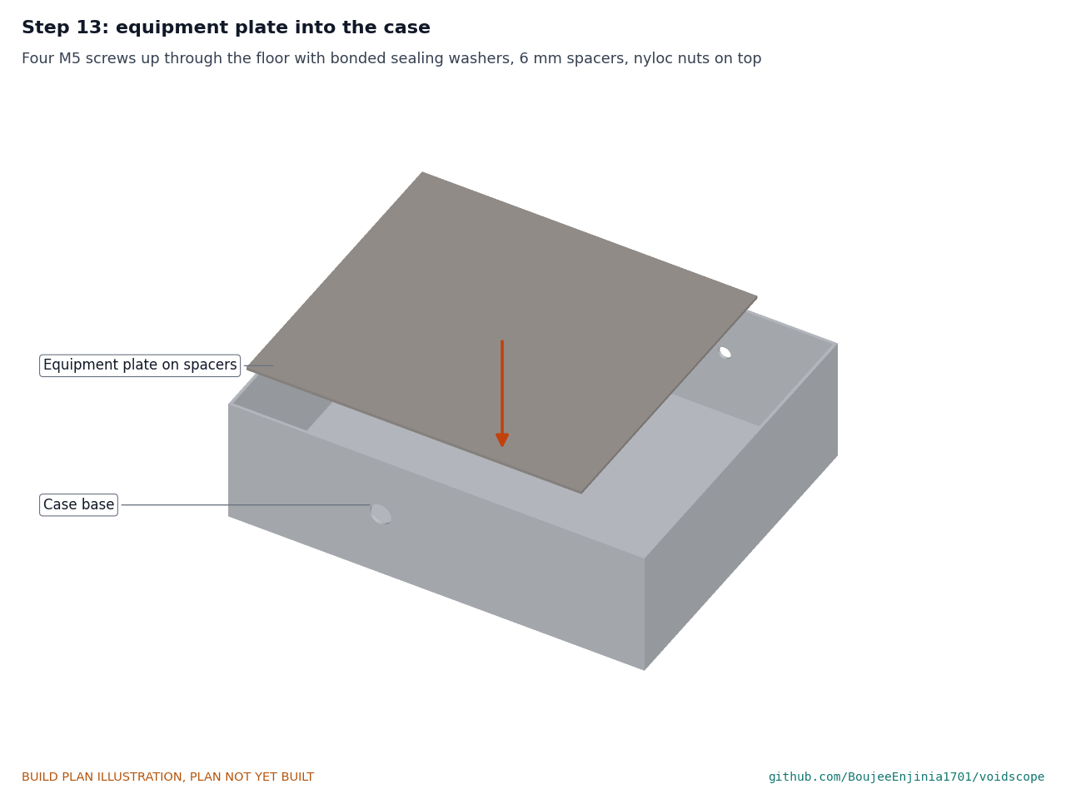
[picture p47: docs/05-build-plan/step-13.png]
Step 13


Four M5 screws up through the floor with bonded sealing washers outside, 6 mm nylon spacers inside, the plate on top, nyloc nuts.

### Step 14: battery, blower, modules and flow meter onto the plate

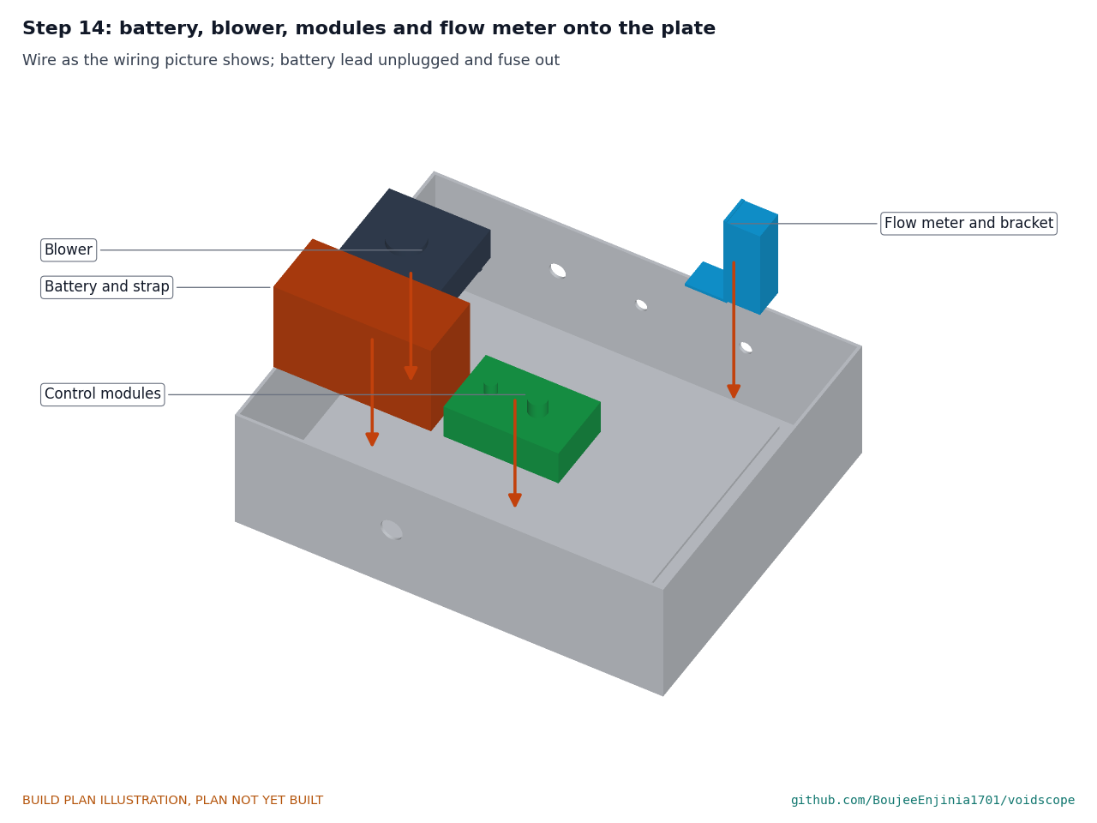
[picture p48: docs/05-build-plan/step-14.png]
Step 14


Fix each part to the plate; strap the battery. Wire them as Figure 25 shows, with the battery lead unplugged and the fuse out. Join the filter, blower, flow meter and outlet with short lengths of hose and hose clips.

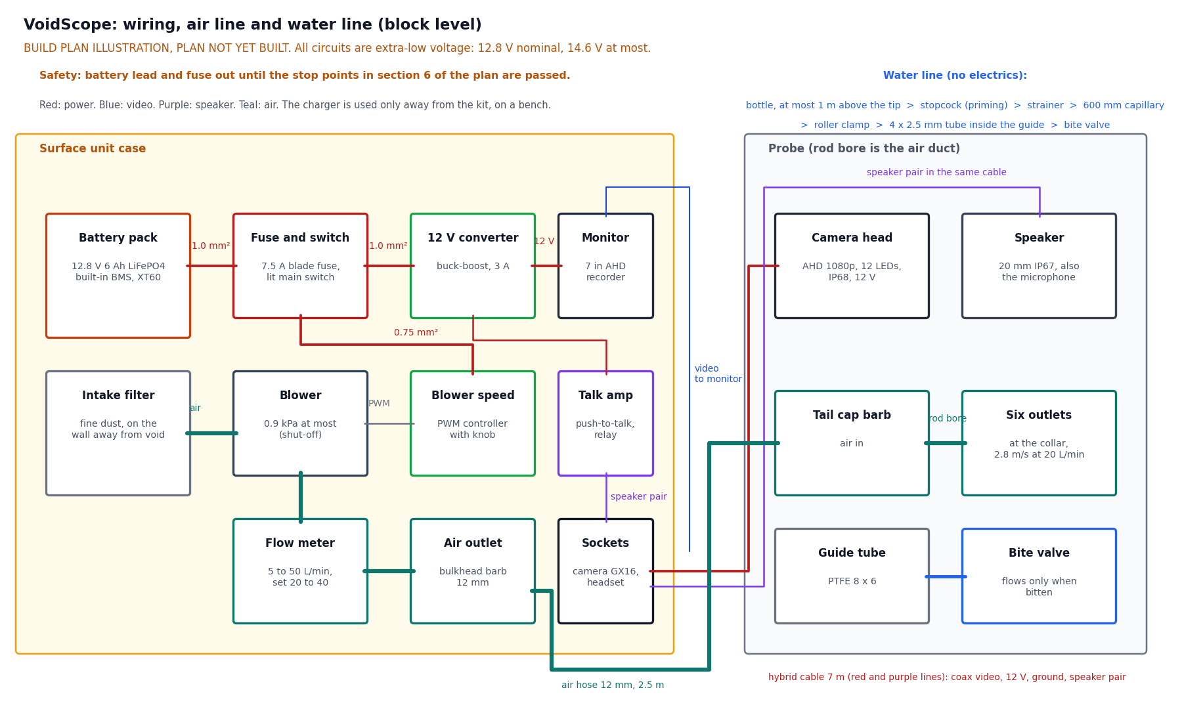
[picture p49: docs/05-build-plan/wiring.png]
Figure 25. Wiring, air line and water line


*Figure 25. Block-level wiring with wire sizes, and the air and water lines. All circuits are extra-low voltage.*

### Step 15: wall fittings and intake filter

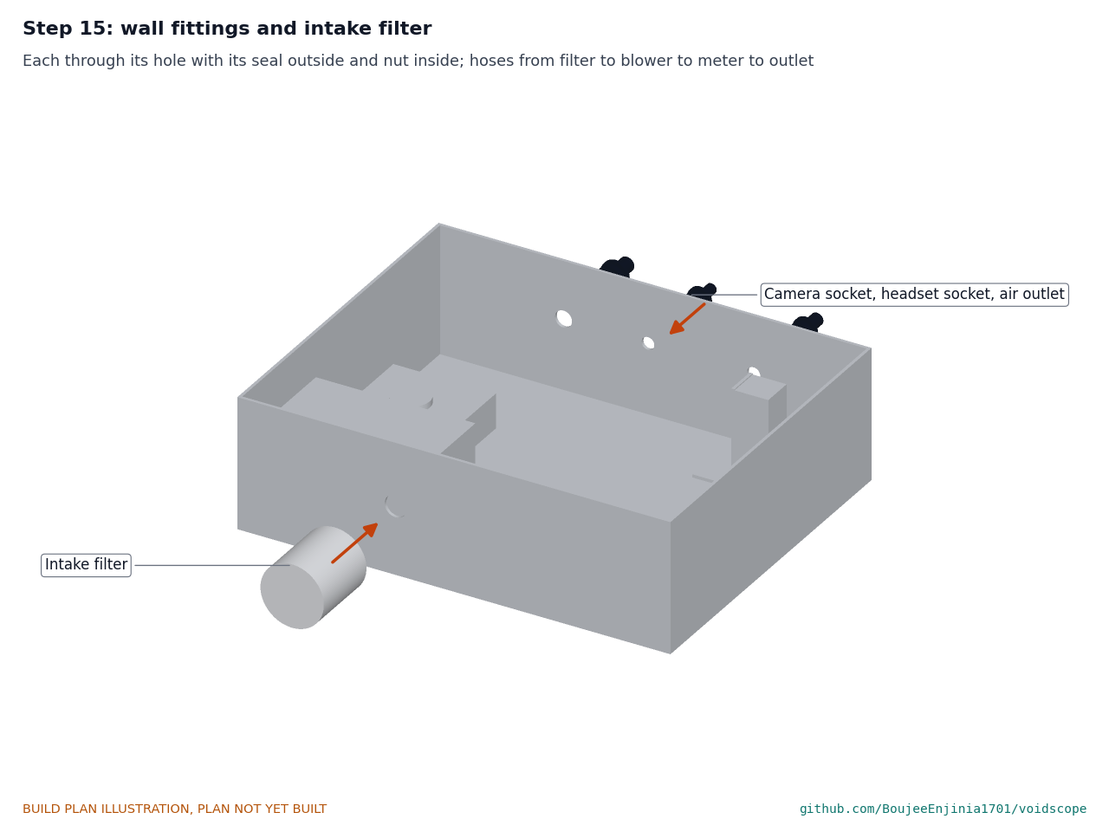
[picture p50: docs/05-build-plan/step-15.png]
Step 15


Fit the camera socket, headset socket and air outlet through the wall facing the probe, and the intake filter through the opposite wall, each with its seal outside and nut inside.

### Step 16: monitor and bracket into the lid

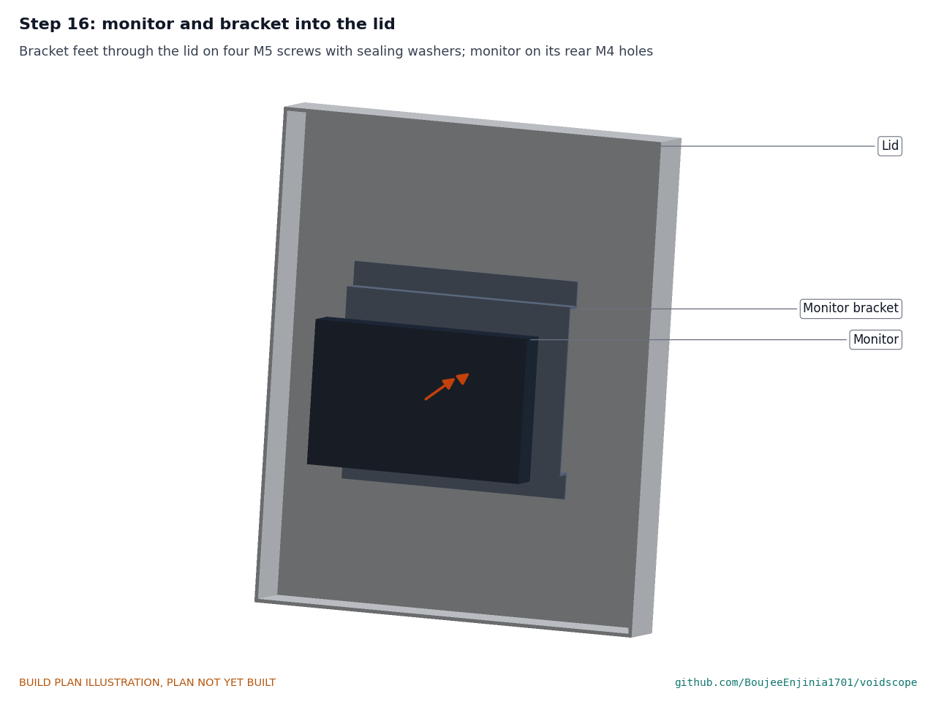
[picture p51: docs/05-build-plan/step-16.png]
Step 16


Bolt the bracket feet through the lid with four M5 screws and sealing washers; screw the monitor to the bracket; run its leads to the modules with enough slack for the lid to open fully.

### Step 17: set up at the hole

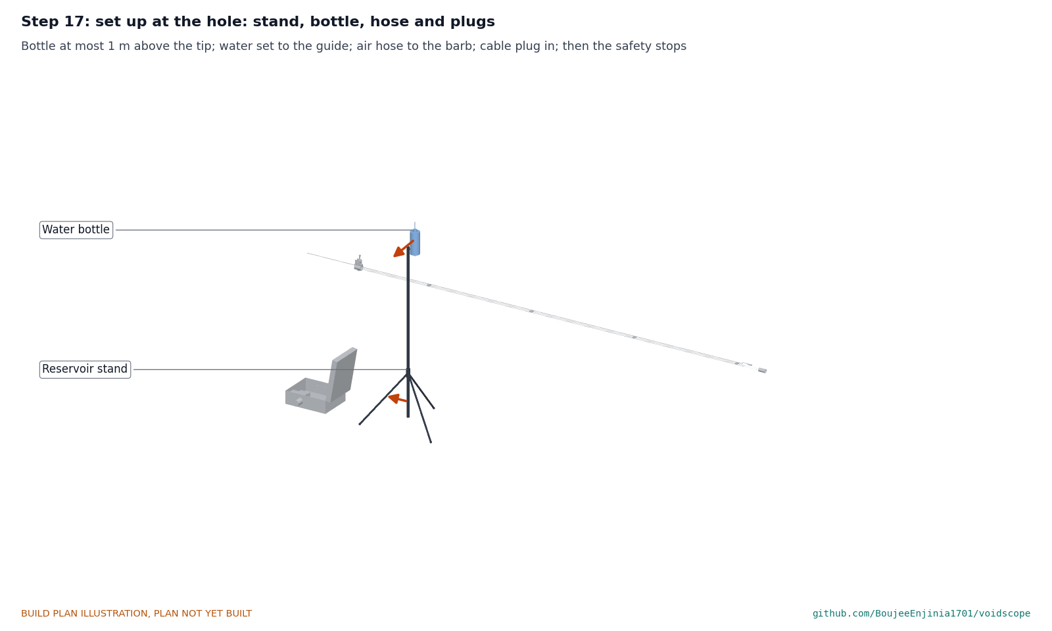
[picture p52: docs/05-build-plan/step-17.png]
Step 17


Stand the surface unit beside the hole with its lid toward the operator. Plug in the camera cable; join the air hose to the outlet and the tail cap barb; sleeve the hose and lines together. Hang the bottle on the stand no more than 1 m above the tip; join the water set from the bottle through the stopcock, strainer, capillary and roller clamp to the water tube. Steer the tip both ways on the monitor, then set the lever upright and tighten the lock knob so the tip is straight. Then work through the safety stops in section 6.

## 5. First checks

These are the checks a TRL 4 test report would record; this plan only lists them. Requirement numbers are those of VDS-REQ-001.

*Table 2. First checks.*

| Check | Requirement | How | Pass when |
| --- | --- | --- | --- |
| Core hole | R1 | With the tip locked straight, pass the assembled probe through a 51 mm ring from the tip back to the steering control | It passes without catching at the tip, head or buttons |
| Reach | R2 | Measure from the front of the grip to the tip, and from the front of the steering control to the tip | 4,000 mm or more from the grip; note the second figure |
| See around a bend | R11 | Test box: a 51 mm hole into a 300 mm wide passage that turns 45° 0.5 m beyond the hole; 20 mm letters 1 m down the turned passage. Push the probe in straight, steer, read; then the other side; straighten and withdraw | Letters read on the monitor to each side; the tip comes back out through the hole without catching |
| Steering | R11 and calculation note J | Lever to each stop; measure the tip angle and the thumb force; then lock and push the tip lightly | 85° to 90° each way; 10 N or less at the thumb; the lock holds the tip |
| Joints | Design loads | Pull each joint by hand, then hang a 30 kg (300 N) load from the tip with the probe vertical; twist each joint | Nothing moves; each button releases with one press |
| Picture | R3 | Dark box, 20 mm letters at 1 m, then with dust | Letters readable on the monitor and in the recording |
| Sealing | R4 | Head under 1 m of water for 30 min with the camera on | Picture stays clear; no water in the head |
| Water ceiling | R5 | Bottle at 1.0 m above the tip, clamp fully open, collect at the bite valve held open for 10 min | Between 1.2 and 1.8 mL/min at room temperature; none with the clamp shut or the valve not bitten |
| Air | R6 | Flow meter at 20 L/min; manometer at a blocked tip at full speed | 20 L/min reached; blocked-tip pressure 1.0 kPa or less |
| Battery | R7 | Run video and light from one full pack | 4 h or more at room temperature (the -10 °C run is a TRL 4 test) |
| Setup | R9 | Two people from closed cases to a picture | 3 min or less |
| Water set change | R10 | Pull the old tube, push a new one, prime | 5 min or less, no tools |
| Voice | R12 | Talk with a person at the tip in a noisy yard | Both understood without repeating |
| Handling | Calculation note B | Push 2 m into a box with the tip unsupported, then 3 m | Held steadily at 2 m; at 3 m the tip must rest on something |

## 5a. Drill card

A printed, laminated card kept in the lid of the surface unit. It is for drills with the team's medical lead; the plan does not cover real use on a person. Amish decided on 2026-10-03 (round 2, 3A) to keep the bite valve on the nose: "i agree with all the 46 recommendations you provided. please proceed." The card therefore carries this rule.

*Table 3. Drill card.*

| When | What to do |
| --- | --- |
| Before the tip goes in or out of a hole | Lever upright, lock knob tight, tip straight on the monitor (stop S9) |
| To give water | Only when the medical lead directs it (stop S7). **Steer the tip aside** with the lever, fully to one side, so the bite valve on the nose is the foremost part and the person can reach it. The camera then sits about 109 mm to the side and 51 mm ahead of the nose. Open the roller clamp from closed; the person bites the valve to drink |
| After giving water | Close the roller clamp, straighten the tip on the monitor, lock the lever, then carry on |
| Never | Force the lever past its stops; use the bent tip to move debris; give water to a person who cannot speak or drink |

Whether a survivor can reach the valve past the tip is confirmed in drills with the medical lead (design decisions register, to confirm item 14).

## 6. Safety stops

Stop at each point. Carry on only when everything listed is true.

- **S1. Before the lathe work.** Chuck key out of the chuck; work held firmly (the 6.5 mm offset in a four-jaw chuck is balanced); guards in place; safety glasses on; no gloves at the lathe.
- **S2. Before the battery is plugged in.** The fuse is out; with a meter, there is no short from the battery socket to ground; every wire end is crimped or soldered and covered; the polarity at the converter matches the pack.
- **S3. Before the fuse goes in.** The pack reads 12.8 to 13.6 V, is undamaged and is strapped down; the main switch is off.
- **S4. Before the blower runs on the probe.** With the outlet blocked by a gloved thumb, the blower at full speed cannot be felt pushing hard; a manometer at the outlet reads 1.0 kPa or less. The intake filter is fitted and faces away from any engine or smoke.
- **S5. Before water goes into the line.** The water set is new and sealed until now; the capillary and strainer are in the line; there is no pump, pressurised container or syringe connected to the bottle side; the bottle hangs no more than 1 m above the tip. Prime with the syringe through the stopcock only before the probe goes in, then turn the stopcock to the bottle and close the syringe port.
- **S6. Before the probe goes into any void, even in training.** The site's structural safety officer has cleared the work position; the operator stays outside the void and off unstable debris; the probe is never used as a lever.
- **S7. Before water is offered to a person (outside this plan; drills only).** The team's medical lead directs it; the person is conscious, can speak and can drink; the flow is set by the roller clamp from closed; the camera tip is steered aside so the bite valve can be reached (drill card, section 5a).
- **S8. Charging.** Packs are charged only on their own charger, away from the kit, on a non-combustible surface, never below 0 °C and never unattended on a first charge.
- **S9. Before the tip goes into or comes out of a hole.** The lever is upright, the lock knob is tight and the tip is straight on the monitor. Never force the lever past its stops, and never use the bent tip to move debris: the links are printed nylon.

## 7. Tools, skills and workspace

**Tools.** Online laser-sintering (SLS) print service for the bending links and the steering control body; metal lathe with a three-jaw and a four-jaw chuck, boring bar, parting tool and 1/4 BSP tap (or the machine shop allowance in the bill of materials); drill press with a vee block and a 45° vee block; drills 3 to 14 mm, step drill to 22 mm; small milling machine or a saw and files for the nose pocket and grooves; tube cutter or fine-tooth saw; deburring tool; M3 and M4 taps; 1.2 mm drill and a 2.0 mm reamer; ferrule crimping pliers and wire rope cutters; scriber, straight edge and calipers; sheet folder or vice with hardwood jaws for 2 mm sheet; heat gun; soldering iron, wire strippers and crimpers; multimeter; spirit level; manometer reading to 2 kPa; graduated cylinder (25 mL) and stopwatch; clamp stand.

**Skills.** Basic turning, drilling, tapping and light milling; bonding with structural epoxy; through-hole soldering and crimping; safe handling of lithium iron phosphate packs. No mains wiring is part of the build: the charger is a bought, certified unit.

**Workspace.** A bench about 2 m long so a section can lie flat; a metalwork corner kept apart from the electronics; a clean area for the water set; the charging spot of S8.

**Personal protective equipment.** Safety glasses for turning, drilling, cutting and soldering; nitrile gloves for epoxy and for handling the water set; hearing protection when cutting tube; no gloves near a turning chuck or drill.

## 8. Where the numbers come from

- Model and constructability checks: `cad/src/model.py` (`python cad/src/model.py --check`, 180 checks); STEP and STL exports in `cad/step/` and `cad/stl/`.
- Pictures: `cad/src/build_plan_media.py`, using `.kit/build_views.py`; written to `docs/05-build-plan/` and `cad/drawings/VDS-DWG-101` to `VDS-DWG-114`.
- General arrangement: `cad/drawings/VDS-DWG-001.pdf`, Rev P3.
- Calculations: `docs/04-calcs/01-sizing.md` (VDS-CAL-001 v0.2) and `docs/04-calcs/sizing.py`.
- Bill of materials: `bom/bom.csv`.
- Decisions: `docs/decisions/0003-steerable-camera-tip.md` (VDS-DDR-003) and `docs/decisions/0002-design-for-construction.md` (VDS-DDR-002), with VDS-DDR-001; register `docs/06-design-decisions.md`.
- Requirements: `docs/03-requirements.md` (VDS-REQ-001 v0.4).

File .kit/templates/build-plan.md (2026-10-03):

---
doc_id: PRJ-BLD-001
title: Project prototype build plan
project: Project name
doc_type: Build plan
version: "0.1"
status: Draft
date: YYYY-MM-DD
author: Amish Chadha
license: CERN-OHL-S-2.0
revisions:
  - version: "0.1"
    date: YYYY-MM-DD
    author: Amish Chadha
    change: First build plan; design made constructable
---

# Project prototype build plan

**Plan, not yet built.** How to build the first proof-of-concept prototype, component by component. Building and testing to it is TRL 4 work. Decisions still to be made are kept in the design decisions register (`docs/06-design-decisions.md`), not here.

## 1. What you are building

Every component, pulled apart and numbered in build order

One short paragraph: what the prototype is, how many components, which are made and which are bought, and the main ways they are made.

## 2. What changed to make it buildable

| Component | The concept had | The buildable design has | Why |
| --- | --- | --- | --- |

## 3. Making the components

### 3.1 Component name

Making sketch

**What it is and what it is made from.**

**How to make it.**

1. Mark out ...
2. Cut ...

**How it fits the parts next to it.**

Close-up of the joint

**Check before moving on.**

## 4. Putting it together

### Step 1: ...

Step 1

## 5. First checks

| Check | Requirement | How | Pass when |
| --- | --- | --- | --- |

## 6. Safety stops

## 7. Tools, skills and workspace

## 8. Where the numbers come from

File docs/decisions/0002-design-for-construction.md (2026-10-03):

---
doc_id: VDS-DDR-002
title: VoidScope design for construction
project: VoidScope
doc_type: Design decision record
version: "0.1"
status: Draft
date: '2026-10-03'
author: Amish Chadha
license: CERN-OHL-S-2.0
revisions:
- version: "0.1"
  date: '2026-10-03'
  author: Amish Chadha
  change: "Changes that make the TRL 2 concept physically buildable, with the reason for each; decided under Amish's 2026-10-03 pre-approval"
---

# 0002: Design for construction

- **Date:** 2026-10-03
- **Status:** accepted. Decided by Amish under his pre-approval of 2026-10-03: "I pre-approve the batch runs along with any recommendations you come up with. I also accept any cost overruns or variations from the assumed scope cost."

## Context

STANDARDS section 18 asks for the design to be made constructable while the build plan is written: every part made by a stated process and fixed to its neighbours (Amish, 2026-09-30: "fix the design assumptions to match and be physically feasible"). The TRL 2 concept (VDS-PRC-001 v0.2, VDS-DDR-001) said what each part does but not how the rod sections join, how the lines cross the joints, how the head holds the camera, the bite valve and the speaker inside 50 mm, or how the surface unit is laid out. The changes below answer those questions. A first build123d check of the model found three more problems (P12 to P14), fixed the same way.

The changes keep what VoidScope does: the same reach, envelope, camera, water and air paths, audio, battery and safety stops. Nothing here changes the pitch or the safety case. Every change is in `cad/src/model.py`, which runs 106 constructability checks (`python cad/src/model.py --check`): parts that must touch do touch, slide fits have their clearance, and parts that must stay apart do. All 106 pass.

## Decision

*Table 1. Changes made to the model, the BOM and the calculations.*

| # | The concept had | The constructable design has | Why |
| --- | --- | --- | --- |
| P1 | A rigid rod "about 50 mm" in about 1 m sections, joints not defined | 38.1 x 1.47 mm (1.5 x 0.058 in) 6061-T6 tube in four 1,050 mm sections; 34.93 x 2.11 mm couplers, 120 mm long, 60 mm bonded and pinned into each front end | These two stock tube sizes telescope with 0.11 mm a side, so the coupler slides in by hand and no turning is needed; the 38.1 mm rod leaves room for a 48 mm head |
| P2 | No joint lock | A bought V-spring snap button in each coupler, through an 8.5 mm hole in the next section | Locks push, pull and twist; one press to undo; the spring strip lies across the bore and leaves room above and below for the lines (3.0 and 2.0 mm clear) |
| P3 | Lines with connectors at each joint | Cable and guide tube left threaded through all sections and the tail cap; sections slide along them for storage | No connectors inside the rod; setup is four clicks (R9) |
| P4 | A separate air line | The rod bore is the air duct, sealed at the tail cap and the head; the joints need no seals | 10 Pa loss instead of about 460 Pa in a 9 mm line; each joint leaks about 0.08 L/min |
| P5 | Water line inside the rod, not replaceable | A PTFE 8 x 6 mm guide tube in the rod; the single-use 4 x 2.5 mm water tube pushes through it | The water set is changed in about 4 minutes without tools (R10) |
| P6 | A one-piece sealed head | A turned collar (socket, plenum, six outlets, speaker pocket, 45° water exit, spigot) and a turned nose (camera bore, lip, bite valve pocket), joined by three M4 screws | Each part can be turned on a small lathe; the camera can be changed |
| P7 | Camera on the axis | Camera bore 6.5 mm below the axis | Makes room on top for an 11.5 mm bite valve pocket inside the 48 mm outline, with 2.85 mm minimum walls |
| P8 | A 28 mm speaker | A 20 mm IP67 speaker in a flat-floored pocket | A flat 28 mm part cannot sit under a 48 mm round outline; 20 mm fits with its cover flush |
| P9 | Button hole in the collar like the rods | The same 8.5 mm hole with a 14 mm spotface | The collar wall is 6.4 mm thick; the spotface lets a fingertip reach the button |
| P10 | A handheld display | Monitor with recorder in the lid of the surface unit, on a folded bracket | One battery and one cable; the crew's hands are on the rod |
| P11 | Surface unit not laid out | Equipment plate on four 6 mm spacers, screwed through the floor with bonded sealing washers; flow meter upright on an angle bracket; wall fittings on the side toward the probe; intake filter on the far side | The case stays sealed; a variable-area flow meter only reads upright; the tallest part is 19 mm below the rim so the lid closes |
| P12 | Tail cap 38.1 mm with a 25 mm bore (found by the check) | 44 mm flange and a 30 mm bore | The lines overlapped the 25 mm bore; the 44 mm flange gives 7 mm of wall for the 1/4 BSP barb thread and is still under the 48 mm head |
| P13 | Water groove floor 19.5 mm above the axis (found by the check) | Floor 20.0 mm | The tube overlapped the 40 mm spigot under the nose; now it rests on it and stays flush with the 48 mm outline |
| P14 | Bite valve pocket 45 mm long; reservoir stand beside the case (found by the check) | Pocket 50 mm; stand 450 mm further out | The tube's bend down into the valve hit the groove floor; a stand leg crossed the open case |

*Table 2. Parts added to the model and the BOM.*

| Added | BOM line |
| --- | --- |
| Couplers, snap buttons and pins | 6 |
| Tail cap, air barb and grommets | 7 |
| Water guide tube | 10 |
| Camera spacer ring and spigot grommet | 1, 3 |
| Equipment plate, spacers and sealing washers | 15 |
| Monitor bracket | 16 |
| Flow meter bracket | 20 |
| Lathe time allowance | 29 |

## Consequences

- The calculations (VDS-CAL-001 v0.1) are made on the constructable design; nothing in them was computed on the concept.
- Drawing VDS-DWG-001 is at Rev P2; making sketches VDS-DWG-101 to 109 are new; the concept media are regenerated from the model.
- Estimated cost USD 1,578 against the USD 2,000 value-engineering target, USD 422 under it.
- `project.yaml`: `design_state: constructable`.
- What remains to confirm with real parts is listed in VDS-DEC-001, "To confirm when parts are bought".

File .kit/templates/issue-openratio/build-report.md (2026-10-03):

---
name: Build report
about: Tell us what happened when you built, printed or tested part of this design
title: "Build report: "
labels: build-report
---

This is a research and educational prototype, not a medical device. It is a TRL 3 concept and is not released for fabrication. If you build any part of it, you do so at your own risk. Reports help everyone.

**What you built** (part, sub-assembly or test)

**Materials, tools and settings**

**What worked**

**What did not work, with photos or measurements if you have them**

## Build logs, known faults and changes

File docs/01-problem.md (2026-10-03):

---
doc_id: VDS-PRB-001
title: VoidScope problem statement
project: VoidScope
doc_type: Problem statement
version: "0.3"
status: Draft
date: '2026-10-03'
author: Amish Chadha
license: CERN-OHL-S-2.0
revisions:
- version: "0.1"
  date: '2026-09-30'
  author: Amish Chadha
  change: Initial scaffold
- version: "0.2"
  date: '2026-10-03'
  author: Amish Chadha
  change: "TRL 2 populate: constraints tied to requirements, first co-design candidate named, open questions answered by the TRL 2 decisions (VDS-DDR-001)"
- version: "0.3"
  date: '2026-10-03'
  author: Amish Chadha
  change: "TRL 3: budget worded as a value-engineering target; safety section added; no change to the problem"
---

# VoidScope problem statement

Local crews reach most collapse survivors first, but they search voids blind and supply survivors by improvisation.

## The problem

Survival after a collapse falls quickly with time. More than 90 per cent of survivors are rescued in the first three days, and most in the first 24 hours by local responders with little equipment ([Gulf News, citing Ilan Kelman, UCL, 2023](https://gulfnews.com/world/mena/why-first-72-hours-are-crucial-for-turkey-syria-quake-rescues-1.1675864021699)). INSARAG medical guidance for entrapped patients recommends starting oral intake where possible, while warning that non-intravenous routes absorb slowly and can cause regurgitation ([INSARAG Medical Working Group, 2023](https://insarag.org/wp-content/uploads/2023/05/Attachment-C2-MWG-The-Medical-Management-of-the-Entrapped-Patient-with-Crush-Syndrome-March-2023.pdf)). Water reaching a survivor early therefore matters, but it has to be given with care.

Commercial search cameras solve the seeing part well. The Leader Cam has a 47 mm head sized for standard 51 mm core holes, 170 degree articulation and two-way audio on a 2.4 m or 3.7 m carbon pole ([Leader](https://www.leader-group.company/en/urban-search-and-rescue-equipment-usar/usar-life-locator-detector-and-search-camera/usar-search-cameras/leader-cam-search-camera-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)); the SearchCam 3000 offers 240 degree articulation and poles up to 4.26 m ([Savox datasheet](https://www.datocms-assets.com/120614/1756472896-savox-searchcam-3000-datasheet-2.pdf)). They cost about $17,500 USD ([Emergency Responder Products](https://emergencyresponderproducts.com/products/leader-cam)) and none of them carries water or air. The gap is a low-cost, open probe that local teams can build, that fits the same core holes, and that turns from a search tool into a supply line once someone is found.

## Users and context

| User | Need | Context |
| --- | --- | --- |
| Municipal fire and rescue crews | A camera probe they can afford and repair to search voids before committing to a dig | Urban collapses where no USAR team is nearby in the first hours |
| Volunteer and community emergency response teams | A simple kit that works after short training, with a clear written procedure | Earthquake-prone towns in low and middle income countries |
| Medical lead on a rescue team | A controlled way to give small amounts of water and to ventilate a void while extrication continues | Confined-space medicine alongside the dig |
| USAR trainers | An inexpensive probe for drills and for teaching void search | Training grounds and rubble piles |

## Operating environment

- Collapsed masonry and concrete, with voids reached through gaps or cored holes of about 50 mm (2 in) and larger.
- Dust, water, mud, sharp rebar and broken glass along the probe path.
- Ambient -10 to +45 °C (14 to 113 °F), day and night work, rain.
- No mains power; battery operation for a full shift is needed.
- Unstable structures and aftershocks; the operator stays outside the void.

## Constraints

- Value-engineering target of USD 2,000 in parts for the full kit (a hypothetical control target, not a spending limit; STANDARDS section 18).
- Probe outer diameter at or below 50 mm (target) so it passes a standard 51 mm core hole.
- Commodity parts, hand tools and a basic 3D printer only; hardware under CERN-OHL-S-2.0, software under MIT.
- Water path built from food-grade materials, cleanable and single-use where it touches the survivor.
- Published as an open engineering reference, not as certified rescue or medical equipment.

## Out of scope

- Acoustic, seismic or radar life detection.
- Powered steering or a crawler base in the first version.
- Intravenous fluids, drugs or any medical treatment beyond water and air delivery.
- Certification to any rescue equipment or medical device standard at this TRL.

## Prior work

| Prior work | What it does | Gap for these users | Source |
| --- | --- | --- | --- |
| Leader Cam search camera | Articulating colour camera head (47 mm) on a telescopic carbon pole with two-way audio and LED light | About $17,500 USD; no water or air delivery | [link](https://www.leader-group.company/en/urban-search-and-rescue-equipment-usar/usar-life-locator-detector-and-search-camera/usar-search-cameras/leader-cam-search-camera-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) |
| Savox SearchCam 3000 | Articulating search camera with extension tubes up to 4.26 m, two-way audio and Li-ion power | Closed commercial kit of 18.6 kg in its case; no water or air delivery | [link](https://www.datocms-assets.com/120614/1756472896-savox-searchcam-3000-datasheet-2.pdf) |
| Savox Delsar Life Detector kit | Seismic and acoustic sensors with a control console for locating buried victims | Locates sounds and taps but cannot see into a void or supply the survivor | [link](https://cseis.com/product/savox-delsar-usar-ready-to-deploy-life-detector-kit/) |

## Co-design

An accredited or aspiring USAR team, or a national fire service training academy in an earthquake-prone country, that can test the probe on training rubble and bring a confined-space medicine lead into the design of the water and air lines. The first candidate to approach is the disaster management training school of the Armed Police Force, Nepal, with Turkey's AFAD training centres as the second; neither has been contacted, and neither is a partner (VDS-DDR-001, D11).

Co-design checklist for the first meeting:

- [ ] Confirm the users, the first-hours context and the 51 mm core hole as the common entry size.
- [ ] Ask the medical lead to review the bite valve, the drip ceiling and the rule that water is given only to a conscious person who can drink.
- [ ] Agree a training rubble site and a dust and darkness test box for TRL 4.
- [ ] Confirm the kit can be carried by two people and set up within 3 minutes.

## Questions answered at TRL 2

The open questions of version 0.1 were answered by the TRL 2 decisions of 2026-10-03 (VDS-DDR-001), made under Amish's pre-approval:

- Lines inside or alongside: inside. The rod bore carries the air, and a guide tube inside the rod carries the single-use water tube, so nothing snags on rebar (D1).
- Drip rate and mouthpiece: a gravity drip with a ceiling of 5 mL/min set by a fixed capillary, and a bite valve at the tip so water flows only when the survivor bites and sips (D7). The medical lead's acceptance is a TRL 4 item.
- Articulation: none in the first version; the camera is aimed by turning the rod (D3).
- Tethered crawler block: VoidScope stays independent (D10).
- Trial host: the first candidate to approach is named above.

## Safety

> **Safety:** VoidScope is safety-critical rescue equipment. It is published as an open engineering reference, never as certified rescue equipment, and it is not a medical device. Only trained rescue teams should use it, inside their own incident command and structural safety procedures, and the operator never enters the void. Water can be inhaled by a survivor who is drowsy, injured or lying badly, so water is given only under the direction of the team's medical lead. Air must be clean and at low pressure. The surface unit holds a lithium iron phosphate battery.

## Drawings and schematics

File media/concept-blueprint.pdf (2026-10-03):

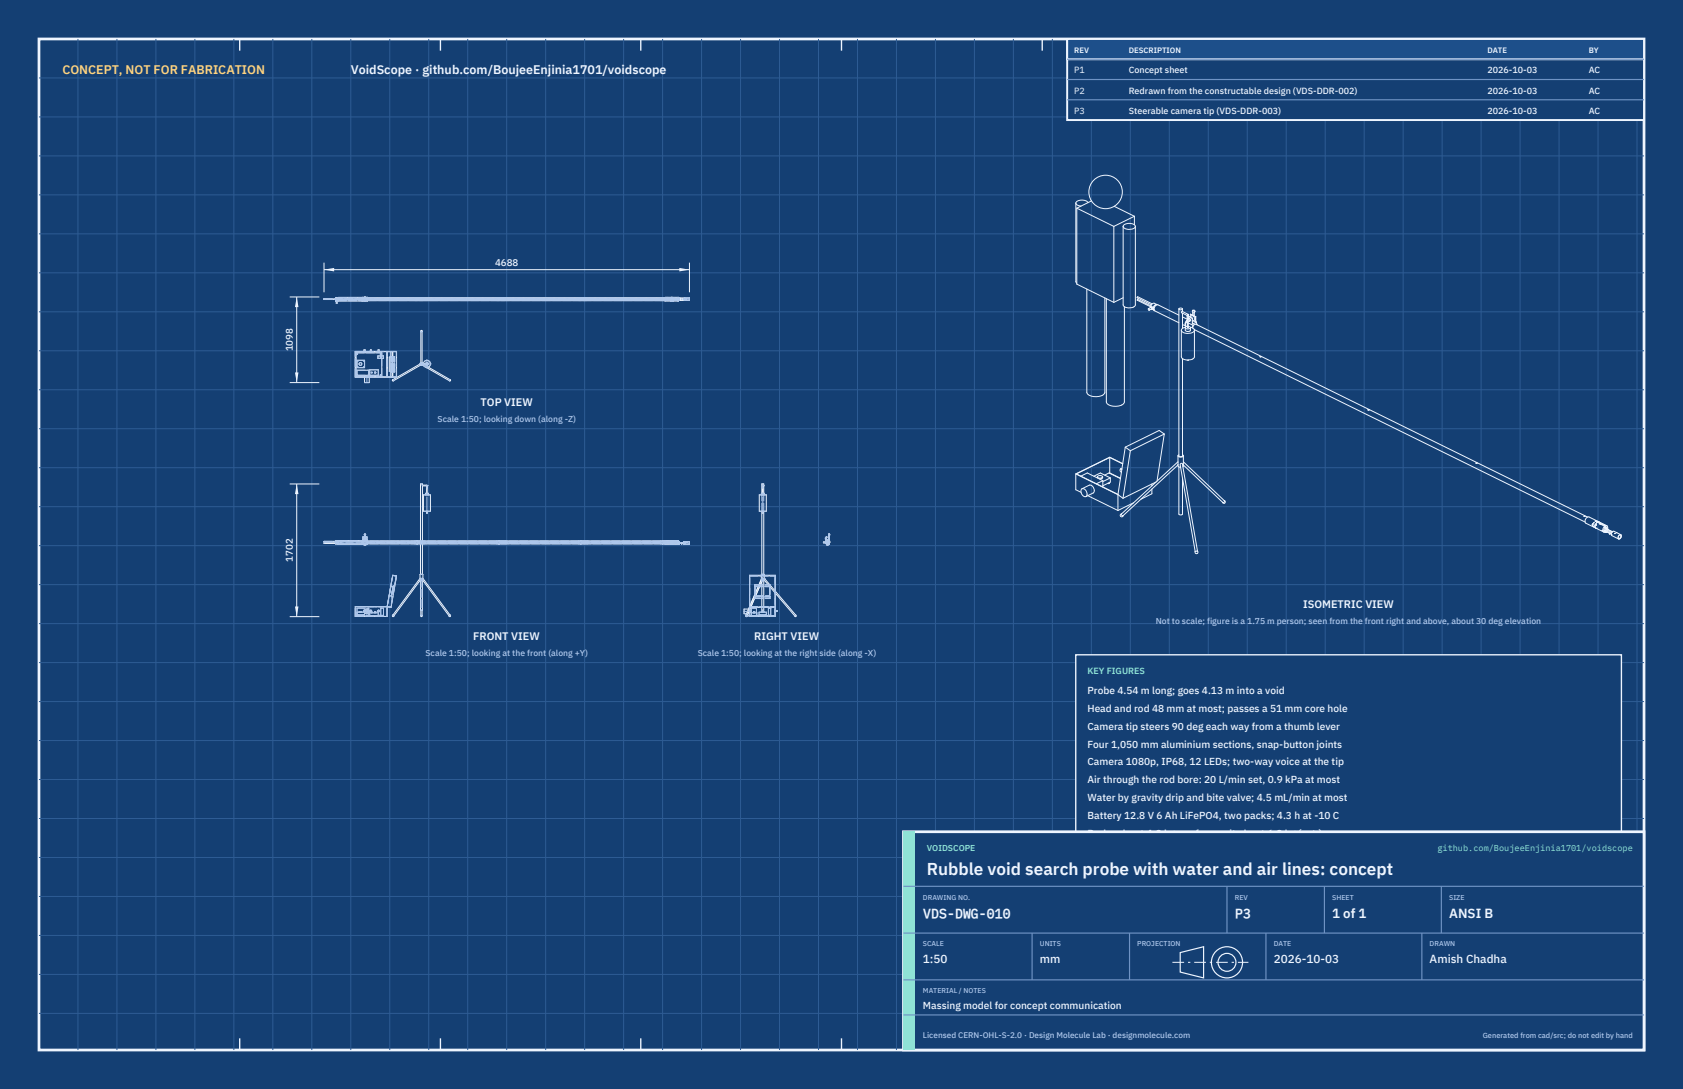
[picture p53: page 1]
CONCEPT, NOT FOR FABRICATION; VoidScope · github.com/BoujeeEnjinia1701/voidscope; FRONT VIEW; TOP VIEW; RIGHT VIEW; ISOMETRIC VIEW; REV; DESCRIPTION; DATE; Concept sheet; Redrawn from the constructable design (VDS-DDR-002); Steerable camera tip (VDS-DDR-003); VOIDSCOPE; github.com/BoujeeEnjinia1701/voidscope; DRAWING NO. VDS-DWG-010; REV P3; SHEET 1 of 1; SIZE ANSI B; SCALE 1:50; UNITS mm; PROJECTION; DRAWN Amish Chadha; Licensed CERN-OHL-S-2.0 · Design Molecule Lab · designmolecule.com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

Scale 1:50; looking down (along -Z)

Not to scale; figure is a 1.75 m person; seen from the front right and above, about 30 deg elevation

Scale 1:50; looking at the front (along +Y)

Scale 1:50; looking at the right side (along -X)

KEY FIGURES
Probe 4.54 m long; goes 4.13 m into a void
Head and rod 48 mm at most; passes a 51 mm core hole
Camera tip steers 90 deg each way from a thumb lever
Four 1,050 mm aluminium sections, snap-button joints
Camera 1080p, IP68, 12 LEDs; two-way voice at the tip
Air through the rod bore: 20 L/min set, 0.9 kPa at most
Water by gravity drip and bite valve; 4.5 mL/min at most
Battery 12.8 V 6 Ah LiFePO4, two packs; 4.3 h at -10 C
Probe about 4.2 kg; surface unit about 6.2 kg (est.)

Rubble void search probe with water and air lines: concept

MATERIAL / NOTES
Massing model for concept communication

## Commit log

2026-10-03 VoidScope at TRL 3: constructable design (kit 1.7.0)
    Problem, concept and requirements; sizing calculations; CAD model, STEP and STL; general arrangement drawing; bill of materials; build plan with making sketches, joint close-ups and step pictures; design decisions register (all decided under Amish's 2026-10-03 pre-approval); TRL 2 and TRL 3 review; photoreal renders and storefront card. Private until Amish opens it.
    [bom.csv, results.csv, voidscope-assembly.step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]
2026-10-03 Carry Amish's 2026-10-03 requirement decisions into the design
    Amish chose option A on each requirement decision ("1A 2A 3A 4A 5A 6A 7A 8A 9A 10A 11A"). CampBreak: primed foot valve, pre-coupled suction hose and a drilled 30 s gather (R9 now 3.2 min at 100 m, me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
    [bom.csv, results.csv, voidscope-assembly.step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]
2026-10-04 Carry Amish's round-2 and round-3 decisions into the design
    Amish approved all 46 round-2 recommendations ("i agree with all the 46 recommendations you provided. please proceed.") and all round-3 recommendations ("For round 3, I agree with all your proposed r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
2026-11-05 Kit 1.9.1 upgrade: pipeline documents and detailed CAD for every option
    STEM check with fixes under the standing instruction and an independent
    review, concept options scored against the user requirements, URS, PRS,
    RTM, REG, FEA, RSK, MKT, PLN and DDR, every option modelled at D3 with
    cad/fidelity.json passing, and the concept options picture rendered with
    Blender Cycles on Amish's Mac. Concept choices stay proposed, awaiting
    Amish.
    Claude-Session: https://claude.ai/code/session_01LppsZSzPTJWTBAV5wh1Goq

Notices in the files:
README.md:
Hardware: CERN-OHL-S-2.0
